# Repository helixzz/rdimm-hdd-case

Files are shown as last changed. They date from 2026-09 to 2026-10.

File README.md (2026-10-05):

# RDIMM HDD Case

**最新完整版本：[v4.4.1 实物版本标记版](docs/v4.4.1.zh-CN.md) · [下载](https://github.com/helixzz/rdimm-hdd-case/releases/tag/v4.4.1)**。外壳底面、上盖外面及两片托盘厚端梁均刻有 `V4.4.1` 和 BASE/LID/MID/TOP 代号。完整两盘 P2S＋AMS 2 Pro 工程，参考 **4:53:10 / 167.67 g / 32 次换料**；配合尺寸与 v4.4 相同，可复用旧件。专用支撑部分仍需工具，刻字实物效果及完整套件验证待完成。以下为历史测试与版本记录。

**历史完整版本：[v4.4 双材料整套工程](docs/v4.4.zh-CN.md) · [下载](https://github.com/helixzz/rdimm-hdd-case/releases/tag/v4.4)**。四个永久零件、两盘、8 条裸 DDR5 RDIMM；采用 RC6 实测能拆净的整块 Support For PLA 支撑，统一 3.2 mm 安装孔并屏蔽孔内支撑，移除角部脆弱残片。P2S＋AMS 2 Pro 参考 **4:51:04 / 167.66 g / 32 次换料**，比旧单材料版更慢；固定端和顶盖限位支撑仍需工具，完整套件装配与耐久待实测。以下为历史测试和版本记录。

**RC6 实测更新：[结果与后续方向](docs/validation-v4.4-trials.zh-CN.md)**。N 两端下垂，固定端阻挡 DIMM，免支撑对照未通过。A 基本合格，A/C 支撑均可一次拆净、无残留；A 固定端及 C1/C3 仍需工具用力拆除。该结果取代下方 RC6 的“待验证”状态，不代表完整产品已通过验证。

**最新测试盘：[v4.4 RC6：整块支撑与无支撑对照](docs/v4.4-rc6-solid-trial.zh-CN.md) · [下载](https://github.com/helixzz/rdimm-hdd-case/releases/tag/v4.4-rc6-solid-trial)**。一盘 A/N/C1/C3 四件，取消细齿与异材锁键，可拆支撑及把手全部 Support For PLA。N 是真正无支撑的诊断对照，非生产承诺。P2S＋AMS 2 Pro 参考 **1:03:14 / 26.27 g / 10 次换料**；[整盒研究](docs/rc6-solid-study.zh-CN.md)筛选低把手候选约 4:51:09 / 32 次。实际打印与拆除仍待验证。

**2026-10-05 实测更新：[RC5 反馈与整块支撑初筛](docs/validation-v4.4-trials.zh-CN.md)**。DIMM 支撑在拆除前已出现散丝，RC5 一体支撑未通过；分体压条使用复杂，暂不作为首选。C 组较易拆净但仍有交界面瑕疵，P1/H32 观察正常。后续转向简单、整块专用材料牺牲支撑，已筛选并发布下列 RC6 对照盘。

**上一轮测试盘：[v4.4 RC5：一体/分体压条对比](docs/v4.4-rc5-peel-trial.zh-CN.md) · [下载](https://github.com/helixzz/rdimm-hdd-case/releases/tag/v4.4-rc5-peel-trial)**。一盘七件：A 连体稀疏支撑，B＋独立永久压条，C1/C3、H32、修正孔内支撑的 P1。P2S＋AMS 2 Pro，约 **1 小时 21 分 27 秒 / 34.12 g / 12 次换料**。B 固定端和压条无支撑；活动端仍需支撑。仅试件，实际拆除与装配待验证。[整套成本比较](docs/rc5-structure-study.zh-CN.md)：A/B 仍比旧双材料候选慢，尚不能宣称生产提速。

**2026-10-04 实测反馈：[RC4 结果与改进方向](docs/validation-v4.4-trials.zh-CN.md)**。H32 的 3.2 mm 孔表现良好；A 固定端仍难拆，A/C 的 Support for PLA 接触薄片仍有残留，尚未达到免工具拆净目标。P1/P2 漏加孔内禁支撑，已在研究副本修正并复核；原发布附件未覆盖。RC5 已完成整盒候选筛选，现提供一体/分体同盘复核。

**上一轮测试盘：[v4.4 RC4：完整产品研究实物复核](docs/v4.4-rc4-product-trial.zh-CN.md) · [下载](https://github.com/helixzz/rdimm-hdd-case/releases/tag/v4.4-rc4-product-trial)**。一盘六件，PLA Basic＋Support for PLA / AMS 2 Pro；约 **1 小时 03 分 15 秒、25.00 g、6 次换料**。验证支撑把手、卡簧斜撑、顶盖限位支撑、3.2 mm 孔，以及真实外壳截面的填充对照。尚非完整生产版本。

**完整产品优化研究：[整套切片、材料策略与批量排版](docs/full-product-optimization.zh-CN.md)**。以完整 8 条容量盒子为对象：选择性双材料约 4 小时 10 分钟；两套三盘平均每套约 3 小时 37 分钟 / 专用支撑料 3.67 g。已整合 3.2 mm 安装孔、角部残片清除及支撑改进，完成几何与刀路检查；尚待实物验证，不是新生产版本。

**制造改进研究：[质量、效率与后处理评估](docs/manufacturing-study.zh-CN.md)**。拨片斜撑及支撑把手去底脚的四试件对照盘，参考从 63 分 43 秒降至 49 分 55 秒，少三处底脚接触界面；含材料分配、装卸路径及残留避让检查。后续 RC4 实测仍有拆除和残留问题，见上方反馈；不是新生产版本。

**上一版试件：[v4.4 RC3 双材料测试盘](docs/v4.4-rc3-dual-trial.zh-CN.md) · [下载](https://github.com/helixzz/rdimm-hdd-case/releases/tag/v4.4-rc3-dual-trial)**。P2S＋AMS 2 Pro，PLA Basic＋**Support for PLA**；一盘四件，明确建模上下接触层并加宽支撑把手，约 64 分钟 / 22.86 g（含冲刷及擦料塔）。孔径已选定 **3.2 mm**，用于 H32 及后续完整工程；本版仍是局部试验，非完整替换套件。[上轮实物反馈](docs/validation-v4.4-trials.zh-CN.md)。

**上轮综合试件：[v4.4 RC2 一盘 12 件](docs/v4.4-rc2-combined-trial.zh-CN.md) · [试件下载](https://github.com/helixzz/rdimm-hdd-case/releases/tag/v4.4-rc2-combined-trial)**。约 57 分钟、22.6 g，合并 DIMM 槽支撑/残留避让、顶盖支撑抽取、安装孔孔径及托盘角部清理。仅用于局部验证，不替代完整套件。

**当前完整版本：[v4.3](docs/v4.3.zh-CN.md) · [正式下载](https://github.com/helixzz/rdimm-hdd-case/releases/tag/v4.3)**。保留侧壁加强棱，并用从底板长出的连续内凹圆弧连接，棱顶圆角、与活动托盘留 0.4 mm 间隙。完整四件两盘，P2S 参考约 3 小时 11 分钟，比 v4.2 增加约 13 秒。仅外壳变化，v4.2 盖板和托盘可复用。完整实物配合与强度仍待验证。

**历史完整版本：[v4.2](docs/v4.2.zh-CN.md) · [正式下载](https://github.com/helixzz/rdimm-hdd-case/releases/tag/v4.2)**。下载一个完整包即可得到全套两盘 P2S 工程、四个零件、支撑示意及检查记录。托盘第一弹臂采用 3 mm 基座，盖板采用连续间隙与斜面导入；八处齿头下方让位 0.5 mm，底部改为连续内凹 R6 过渡；两盘参考约 3 小时 11 分钟。实际完整配合与强度仍待实物验证。已有 RC4 盖板可复用；外壳及旧托盘需更新才能获得全部修复。

**历史盖板修订：[v4.1-rc4 替换盖板](docs/v4.1-rc4.zh-CN.md)**。延续斜面导入，将连接颈侧间隙向下连续延伸并平顺接回根部，修正 RC3 横移与上浮组合时的局部干涉。仅重打盖板约 37 分钟，RC1/RC2 外壳、托盘复用；舌片主体厚度和承托面积保持 RC3，实际松紧和强度待验证。

3D-printable storage for **8 bare DDR5 RDIMMs** inside a **147 × 101.6 × 26 mm** envelope, with traditional 3.5-inch HDD side and bottom mounting positions.

为服务器内存设计的硬盘位收纳盒：三层托盘，容量 2 + 3 + 3 条，优先保持标准 3.5 寸硬盘外形。目标参考内存为 Samsung M321RAJA0MB2-CCP / CCPKF，打印机参考为 Bambu Lab P2S。

**历史结构候选：[v4.1-rc2 缩小拨扣窗口](docs/v4.1-rc2.zh-CN.md)**。两个短端开口的上方恢复连接壁，下部保留拨扣和支撑清理空间；配置 p2 对小拱顶局部屏蔽支撑，六侧孔内也无支撑。RC1 盖板及托盘不变、可继续使用。完整两盘参考 3 小时 12 分 6 秒，较 RC1 增加约 30 秒、0.63 g。几何和名义刀路通过，实际操作与抗震/跌落仍待验证。

**上一版结构：[v4.1-rc1 扣合与卡扣根部加固](docs/v4.1-rc1.zh-CN.md)**。四处平面扣脚、加厚弹臂和根部圆角、长侧壁三角加强筋；仍按压、滑 8 mm、抬盖，8 条四件两盘。不混用 v4.0/v3 盖板及托盘。

**上一版打印工艺：[v4.0-rc4-p1 六侧孔局部禁止支撑](docs/v4.0-rc4-p1.zh-CN.md)**。保留 RC4 圆孔尺寸，切片确认六孔内支撑归零，其余关键支撑保留；需打开带配置的工程，STL 不包含此修订。无支撑孔顶质量及实际定位销配合尚待打印验证。

**历史几何候选：[v4.0-rc4 两条长边 R2 圆角](docs/v4.0-rc4.zh-CN.md)**。在去除侧字的 RC3 基础上，只在长内壁与底板交界增加 R2，并保留安装孔净空；短端卡扣和 SATA 区不变。圆角最高 Z=6，活动托盘最低面 Z=10.8，间距 4.8 mm，完整几何路径和名义刀路检查通过。盖板及托盘与 RC2/RC3 兼容；外壳盘预计增加约 2 秒、0.13 g，整套仍约 3 小时 7 分。改善底部横纹的效果及完整实装尚待验证，当前打印无需中断。

**打印反馈与新候选：[v3.2-rc1 打印可靠性修订](docs/v3.2-rc1.zh-CN.md)**。v3.1 首个外壳出现按压锁扣粘连，暂停按旧方案批量制作。RC 修订锁扣、PCB 槽口，并提供明确支撑配置和一盘可选验证件；完整件仍两盘，既有盖板可保留。[候选几何](models/v3.2-rc1/)需要配套工艺，不能继续无支撑打印；本版仍待实物验证，未覆盖旧 Release。

**检查件实测更新：[RC2 A 底座修正](docs/v3.2-rc2-latch-check.zh-CN.md)**。RC1 小盖板缺少下承托而倾斜掉落，修正件只重打 A 底座，复用原小盖板，参考约 13 分钟。单槽实际 DIMM 装卸无干涉，但固定力偏弱、清理费技巧；完整套件与运输性能仍未验证。RC2 此处仅为检查件修订，不替换整套 RC1 文件。

**当前固定版本：[v3.1 完整两盘实测版](docs/v3.1.zh-CN.md) · [下载 Release](https://github.com/helixzz/rdimm-hdd-case/releases/tag/v3.1)**。v3-S 正式命名为 v3.1，单件几何不变；单套两盘（外壳＋盖板、三个托盘），STL / 3MF 二选一。另有十套共 15 次任务的批量排版与实际参考切片时间。状态仍为待实物验证的预发布，不能把时间估计当作质量保证。[版本规则](docs/versions.zh-CN.md)。

**历史工作名称：[v3-S 一体拨扣托盘](docs/v3-simple.zh-CN.md)，当前请使用 v3.1**。保留 8 条容量和 v3 外壳，取消三片独立限位框，内部只剩三个托盘；每槽插入固定端、拨扣放下、松手固定。新试件仍[一盘完成](models/v3-simple/first-test-all.stl)，整套缩减为两盘。尚未打印验证卡扣力度、耐用性与实际保持能力；请先试单槽件。[查看实际网格预览](models/v3-simple/simple-tray-preview.png)。

**New experimental v3: [免工具取放与固定背板避让](docs/v3.zh-CN.md).** No mandatory internal screws; sliding lid with a release latch, three keyed retainer frames, 2 mm deeper mounting holes, and a connector-end recess. Remains 147 × 101.6 × 26 mm / 8 modules. Print the mechanism/retainer coupons and empty bay-fit gauge first: **v3 has not been physically tested**, and the connector recess does not establish universal backplane compatibility. Closed cover required for inversion retention. Complete [three-plate STL layouts](models/v3) are supplied; v2 and v2-R remain unchanged and must not be mixed with v3.

V3 now includes [engraved operation guides](models/v3/operation-guides.png): `1 PRESS`, `2 OPEN`, `KEEP LEVEL`, matching layer numbers, `LIFT` at the thick end bars, and `SATA END`. These are shallow recesses in the printable geometry, with no external font dependency; the assembly interfaces remain compatible with the earlier unmarked v3.

**V3 首次试打只需一盘：[first-test-all.stl](models/v3/first-test-all.stl)**。空壳、单槽托盘与框、滑轨及锁扣小样共 7 件已排好位置，[查看排版](models/v3/first-test-all.png)。保持 100% 比例，按层打印；需按说明设置局部支撑并检查细筋。无需再分别打印三组试件。

**Status: engineering prototype. A user printed v2 and reported noticeable movement when carrying it.** The experimental [v2-R retention retrofit](docs/retention.zh-CN.md) adds a screwed tray stack and PCB-edge keepers while reusing the v2 body; **the retrofit is not yet physically tested**. This is not a certified ESD or transport enclosure. V2 offers either plastic mounting pilots or optional metal inserts on the six side holes; bottom and lid pilots still require tapping.

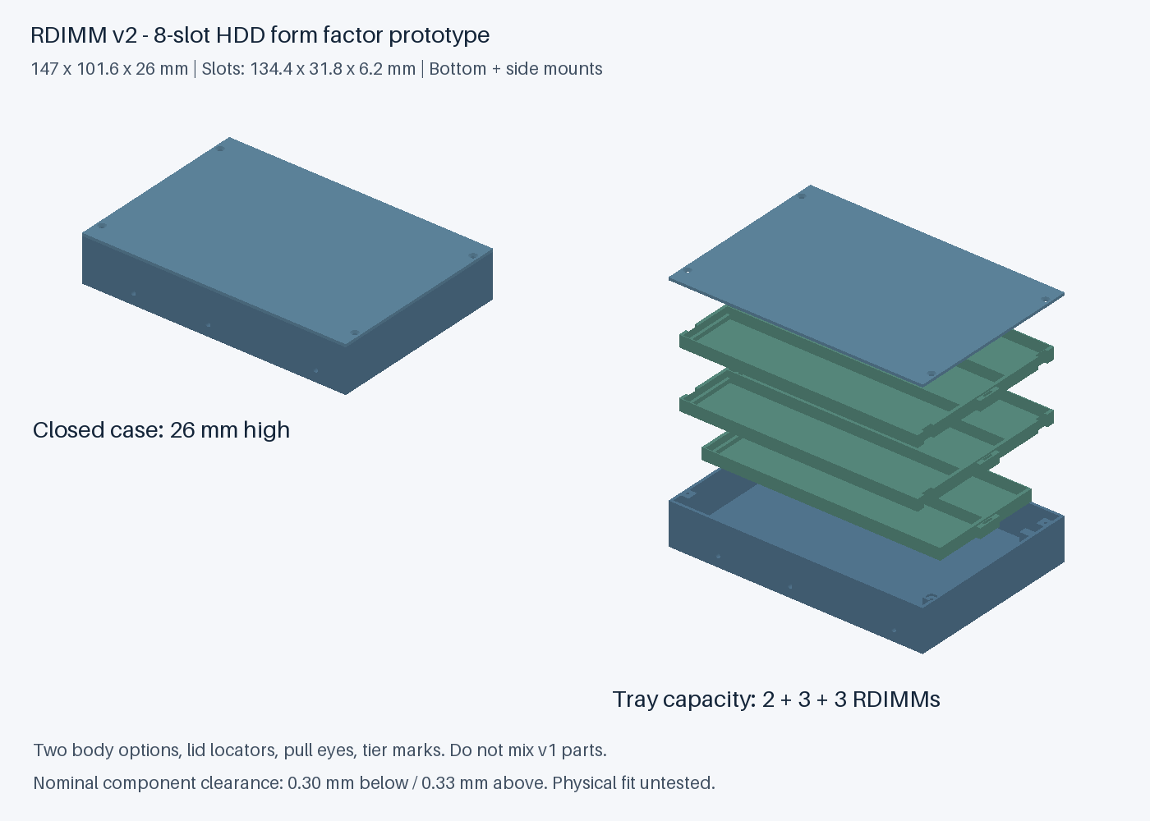
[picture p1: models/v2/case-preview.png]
Mesh-derived assembly preview


**V2 prototype:** greater component-to-floor clearance, lid locating collars, tray pull eyes and tier marks, plus optional side inserts. See [changes and tradeoffs](CHANGELOG.md) and the [detail preview](models/v2/v2-details.png). Do not mix v1 and v2 parts.

## Print the current prototype

- **已有 v2 外壳且遇到晃动：[v2-R 固定升级件与小样说明](docs/retention.zh-CN.md)**。先打印 `models/v2-retention/first-test-plate.stl`；需额外 M2 螺丝，不能混用旧托盘。
- **整盘打印：[P2S 两盘排版与导入说明](plates/v2/README.zh-CN.md)**。每盘一个 STL / 3MF，无需逐件摆放；普通攻牙版和侧面嵌件版分别提供替代第一盘。
- Browse [v2 STL files](models/v2), or use GitHub **Code → Download ZIP** on the branch you intend to print. [V1 files](models/v1) remain available as a historical baseline.
- **先阅读：[v2 中文打印与装配说明](docs/v2.zh-CN.md)**。尺寸出处和原始硬盘孔位来源另见 [v1 基准说明](docs/printing.zh-CN.md)。
- Print one `fit-coupon-1-slot-print-3.stl` first, then three total plus `stack-coupon-cap.stl` for stack fitting. If choosing side inserts, also print `side-insert-coupon.stl` before the body.
- Full set: choose **one** of `body-pilot.stl` / `body-side-inserts.stl`; add `tray-bottom-2.stl`, `tray-middle-3.stl`, `tray-top-3.stl`, and `lid.stl`, one each. STL units are mm; use 100% scale. The lid is already exterior-face-down for printing.

HDD mounts use **6-32 UNC**, not M3. The optional metal-side version is dimensioned specifically for **PEM IUTB-632-150** inserts. Bottom holes remain 2.7 mm plastic pilots, now 3.3 mm deep. Limit installed screw intrusion to 3.0 mm and check actual effective thread depth. The lid uses four M2 countersunk screws; its plastic pilots still require tapping. Read the full guide before printing or installing hardware.

## Design basis and limitations

| Item | v2 value |
| --- | --- |
| Assembled envelope | 147 × 101.6 × 26 mm |
| Capacity | 8 RDIMMs; not a proven maximum-density packing |
| Nominal cavity per module | 134.4 × 31.8 × 6.2 mm |
| Reference maximum module envelope | 133.80 × 31.40 × 5.57 mm |
| Nominal component clearance | 0.30 mm below, 0.33 mm to next tray above |
| Mounting positions | 6 side, 4 bottom; traditional HDD pattern |
| PCB contact assumption | 2 mm component-free region at each short edge |

The envelope comes from Micron's DDR5 RDIMM reference drawing, cross-checked against another Samsung double-sided RDIMM drawing. It is **not a measured or verified mechanical drawing for the exact target Samsung part**. Sources and coordinate conventions are recorded in the [design/printing guide](docs/printing.zh-CN.md#设计基准与来源).

Automated checks cover closed meshes, connected parts, both body assemblies, simplified RAM interference, 64 component-offset cases, insert envelopes, the coupon stack, and 3 mm screw penetration. They do not establish print tolerances, tapping strength, exact component placement, chassis compatibility, or ESD performance. There is no independent PCB latch: arbitrary-orientation retention and transport safety are not established. Ordinary PETG/ASA is not inherently static dissipative. Physical work remains explicitly tracked in the [v2 validation record](docs/validation-v2.md). A 38 mm upright variant is a future design direction; chassis clearance must be established before adopting it.

## Rebuild on another computer

Use **Python 3.12** and Git on Windows, macOS, or Linux. From the repository root:

```sh
python -m venv .venv
# Windows PowerShell:
.venv\Scripts\Activate.ps1
# macOS / Linux instead:
# source .venv/bin/activate
python -m pip install -r requirements.txt
python src/build_case.py
```

The v2 generator writes nine STL files, `verification.json`, and two mesh-derived PNG previews to ignored `build/`. Geometric assertions run as part of generation; do **not** run Python with `-O`. To choose another directory, pass `--output-dir PATH`. The default preview labels are English; for Chinese labels supply `--font PATH_TO_CHINESE_FONT` (font not bundled).

The design parameters currently live near the top of `src/build_case.py`. Changing dimensions requires reviewing the construction and checks, not just editing a single number. Commit source changes and intentionally regenerated `models/v2/` artifacts together; normal rebuilds leave the tracked baseline untouched. To refresh the v2 baseline, use `python src/build_case.py --output-dir models/v2`. Rebuild the untouched v1 design with `python src/build_v1.py --output-dir build/v1`. GitHub Actions rebuilds both versions on Windows and Linux and uploads the generated files.

## Collaborating

See [CONTRIBUTING.md](CONTRIBUTING.md) for the edit/build/review workflow and [AGENTS.md](AGENTS.md) for agent handoff constraints. Open an issue for print feedback or design proposals. Include module part number, material, nozzle/layer settings, measurements, and photos when available. Share changes in a branch and pull request so work from different computers can be reviewed together.

## License

Original source, CAD/model files, previews, and documentation in this repository are provided under the [MIT License](LICENSE). Referenced manufacturer drawings are linked as design references, are not redistributed here, and retain their respective owners' rights. No manufacturer endorsement or universal fit certification is implied.

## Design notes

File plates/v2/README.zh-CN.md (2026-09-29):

# v2 整盘打印排版（P2S）

已有用户实打反馈：原 v2 携带时有明显晃动。这里仍是原版打印文件；[v2-R 固定升级件](../../docs/retention.zh-CN.md) 可保留外壳、更换内部件和盖板，先试小样。

完整盒子为 **两盘、共五个零件**。每盘提供相同排版的 STL 和通用 3MF，二选一导入，**不要两种格式同时导入**。无需逐件手动摆放。

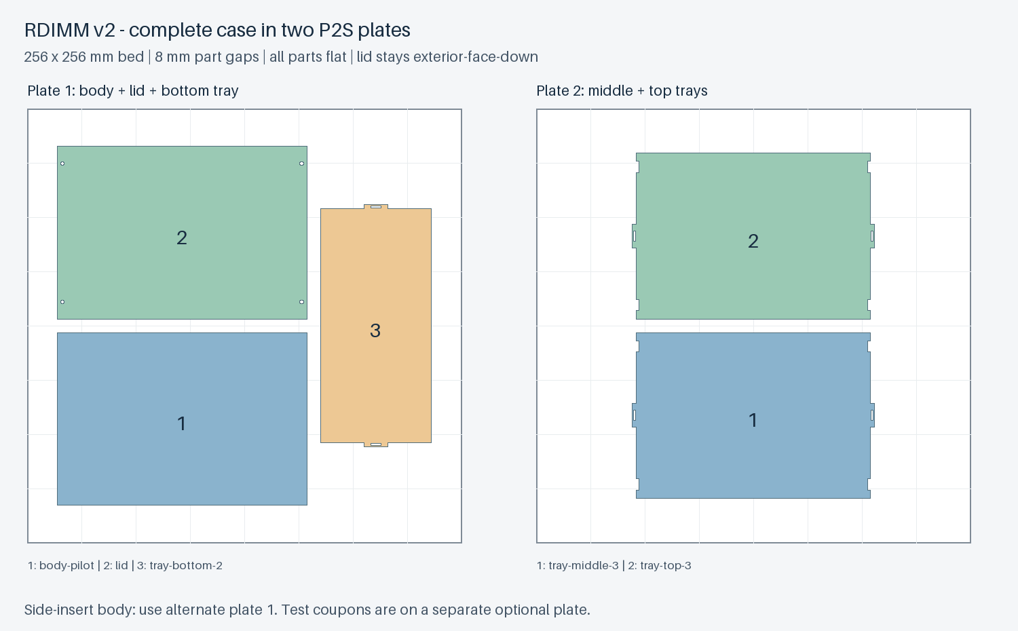
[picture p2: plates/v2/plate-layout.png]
两盘排版


## 打印哪些文件

| 文件（扩展名任选 `.stl` 或 `.3mf`） | 内容 | 是否必选 |
|---|---|---|
| `plate-1-pilot` | 普通攻牙外壳＋盖板＋两槽底托盘 | 与下一项二选一 |
| `plate-1-side-inserts` | 侧面嵌件外壳＋盖板＋两槽底托盘 | 与上一项二选一 |
| `plate-2-middle-top` | 三槽中托盘＋三槽顶托盘 | 必选 |
| `optional-test-plate` | 三个单槽试件＋试装平盖＋一个嵌件孔径试件 | 可选；不是正式盒内零件 |

默认打印 `plate-1-pilot` 和 `plate-2-middle-top` 即可得到一套。侧面嵌件版的指定五金与加工要求见 [v2 装配说明](../../docs/v2.zh-CN.md)。试件仍建议先试装；若只想先打一个单槽，原始单件文件在 `models/v2/`。

## 在 Bambu Studio 中使用

1. 新建项目，选择实际 **P2S、喷嘴、打印板和耗材**；本排版按 256 × 256 mm 热床制作。
2. 导入选定的第一盘文件。STL 已把同盘零件保存在同一个文件内；3MF 是保留相对位置的模型组件，**不含打印机/耗材/工艺预设**。若软件询问，按模型/几何导入。保持 **100% 比例**，不拆散后重新排列，不自动改变朝向。
3. 使用**逐层打印**，不要切换为逐对象顺序打印；8 mm 间距不是喷头逐对象避让距离。使用已有合适的耗材配置，0.4 mm 喷嘴可从 0.20 mm 层高开始检查。盖板已经外表面朝下，不要再次翻转。
4. 切片并检查床边、薄壁、侧孔桥接和首层。若需要 brim，可先将宽度控制在每件 3 mm 以内；更大的 brim、裙边或新增擦料塔可能需要重新检查排版。没有预生成 G-code，也没有发送到打印机。
5. 第一盘打印后取件、清理打印板，再打印第二盘。也可在同一个 Bambu Studio 项目中新建第二个打印盘，把第二盘文件导入那里。**不要把两个文件同时放到同一物理打印盘。**

每盘 STL 导入后被整体自动居中通常不影响相对布局；不要选择把各个实体重新自动排布。正式第一盘占地约 220.4 × 211.2 mm，第二盘约 142.8 × 203.6 mm。全部零件都接触 Z=0，未叠放打印。

## 为什么不能保持平放而合成单盘

对实际 v2 网格的 XY 投影做并集后，五个零件的投影面积合计约 **65,912.76 mm²**；256 × 256 mm 热床只有 **65,536 mm²**。即使不留任何间距，保持这些打印朝向也不能装进同一平面。这一结论不涉及把零件竖起来、修改设计或增加另一种支撑策略。

本排版只平移零件，并将两槽托盘绕 Z 轴旋转 90°，没有缩放或修改模型。正式两盘均留至少 8 mm 零件包围盒间距；第一盘最小床边余量约 17.8 mm，第二盘约 26.2 mm。两种第一盘是替代选项，不能同时打印当作同一套所需零件。

打印面积参考：[Bambu Lab 官方 P2S 介绍](https://blog.bambulab.com/the-icon-redefined-meet-the-p2s-a-completely-reengineered-version-of-the-ultra-productive-p1-series/)。

## 重建与验证

在项目根目录运行：

```sh
python src/layout_v2.py --output-dir plates/v2
```

生成器从现有 `models/v2/*.stl` 读取，检查尺寸保持、床内边界、8 mm 间距、STL 闭合性及实体数量、导出回读坐标/体积、3MF XML 网格回读；记录源 STL 的 SHA-256。详细结果在 `layout-verification.json`。

这些几何验证不是实际打印验证。Bambu Studio 的命令行导入/再导出检查另记录在 `bambu-import-check.json`，并不代表已切片或已选择你的耗材配置。v2 原有的实物验证与 ESD 限制仍适用。

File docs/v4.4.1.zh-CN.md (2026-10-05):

# v4.4.1：每个零件都有实物版本号

完整收纳盒可放 **8 条裸 DDR5 RDIMM**，外形 147×101.6×26 mm，底层两槽、两片活动托盘各三槽。采用 P2S＋AMS 2 Pro、PLA Basic＋Support For PLA 双材料工程。

本版在 v4.4 完整工程上增加可直接打印的版本号与零件代号，便于识别拆散、混放的零件。只增加非配合面的浅凹字，四个永久零件的装配尺寸、20 块专用支撑、3.2 mm 安装孔和日常操作不变。已有 v4.4 零件可以继续配合使用，无需仅因缺少标记而报废。

| 零件 | 实物文字 | 位置 |
|---|---|---|
| 外壳 | `V4.4.1 BASE` | 外壳底面，翻过来可正向阅读 |
| 上盖 | `V4.4.1 LID` | 上盖外侧平面 |
| 中层托盘 | `V4.4.1`、`MID` | 厚端梁顶面 |
| 顶层托盘 | `V4.4.1`、`TOP` | 厚端梁顶面 |

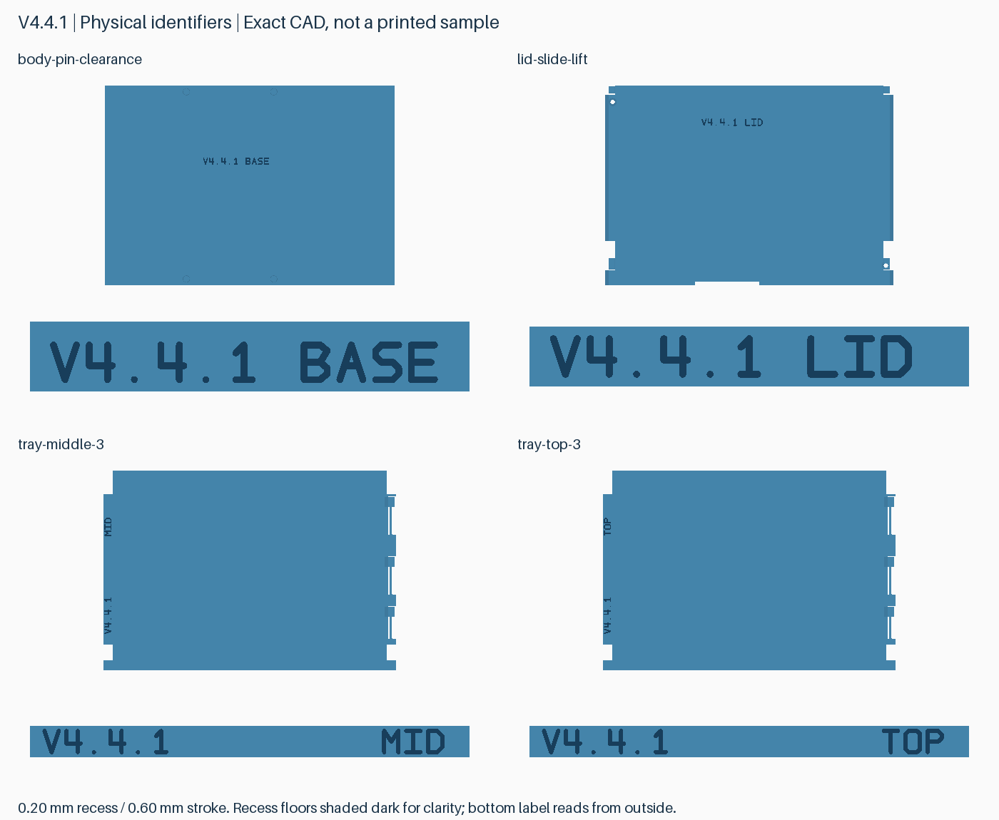
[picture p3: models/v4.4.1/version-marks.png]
版本标记位置


图为真实 CAD 几何示意，字槽底面加深颜色以便辨认；实际仍为同色单材料表面，没有额外换色。字深 **0.20 mm**、笔画宽 **0.60 mm**、字高约 3.6 mm。托盘薄底板、卡簧和 DIMM 接触面不刻字。保留原有操作提示。从本版起，后续版本的所有永久零件均须带完整版本号，试件还须带试件编号；一次性拆除的支撑不标号。

## 下载与打印

从 [v4.4.1 Release](https://github.com/helixzz/rdimm-hdd-case/releases/tag/v4.4.1) 下载 **rdimm-v4.4.1-complete-P2S-AMS2Pro.zip**。这是完整两盘工程，不是补丁文件。解压后以“工程”打开：

- `rdimm-4.4.1-plate-1-pin-clearance-P2S-AMS2Pro.3mf`：外壳＋上盖。
- `rdimm-4.4.1-plate-2-upper-trays-P2S-AMS2Pro.3mf`：中层＋顶层托盘。

| 打印盘 | 参考时间 | 总耗材（含冲刷、擦料塔） | 换料 |
|---|---:|---:|---:|
| 1 外壳＋上盖 | 3 小时 24 分 23 秒 | 121.39 g | 22 次 |
| 2 两片托盘 | 1 小时 28 分 47 秒 | 46.28 g | 10 次 |
| 整套 | **4 小时 53 分 10 秒** | **167.67 g** | **32 次** |

相比 v4.4，整套增加约 **2 分 6 秒**，换料次数不变。以上为 Bambu Studio 切片估算，不含换盘和后处理。P2S、0.4 mm 喷嘴、0.20 mm 层高、纹理 PEI 板、按层打印。材料 1：Bambu PLA Basic；材料 2：**Bambu Support For PLA / GFS02**，不是 Support for PLA/PETG。打印前映射至实际 AMS 槽位。

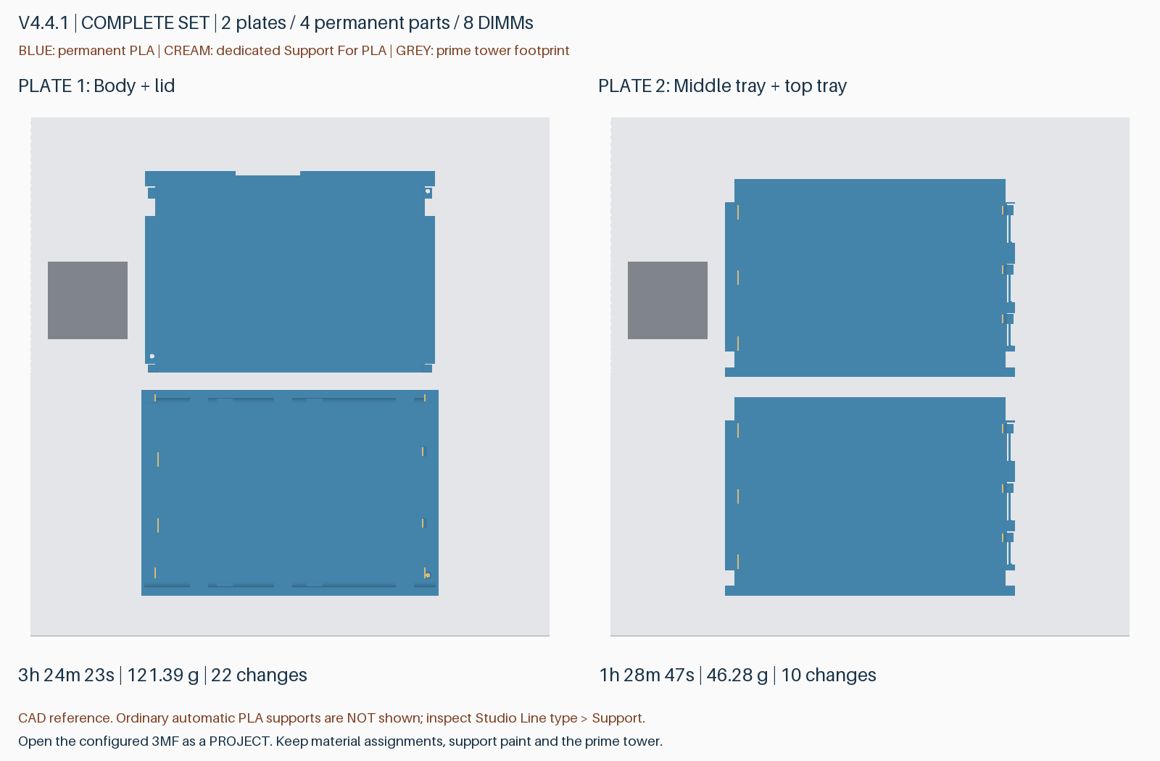
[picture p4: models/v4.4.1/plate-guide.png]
完整两盘排版


保留文件中的摆放、材料分配、禁支撑涂色和擦料塔；不要重新拆分模型、自动落底或全局禁用支撑。普通自动支撑仍用 PLA，20 块专用支撑及其把手均为 Support For PLA。双向冲刷各 800 mm³，不冲刷进成品或支撑。包内四份 STL 只供几何参考，不可替代配置工程；无 G-code。

## 拆支撑与装配

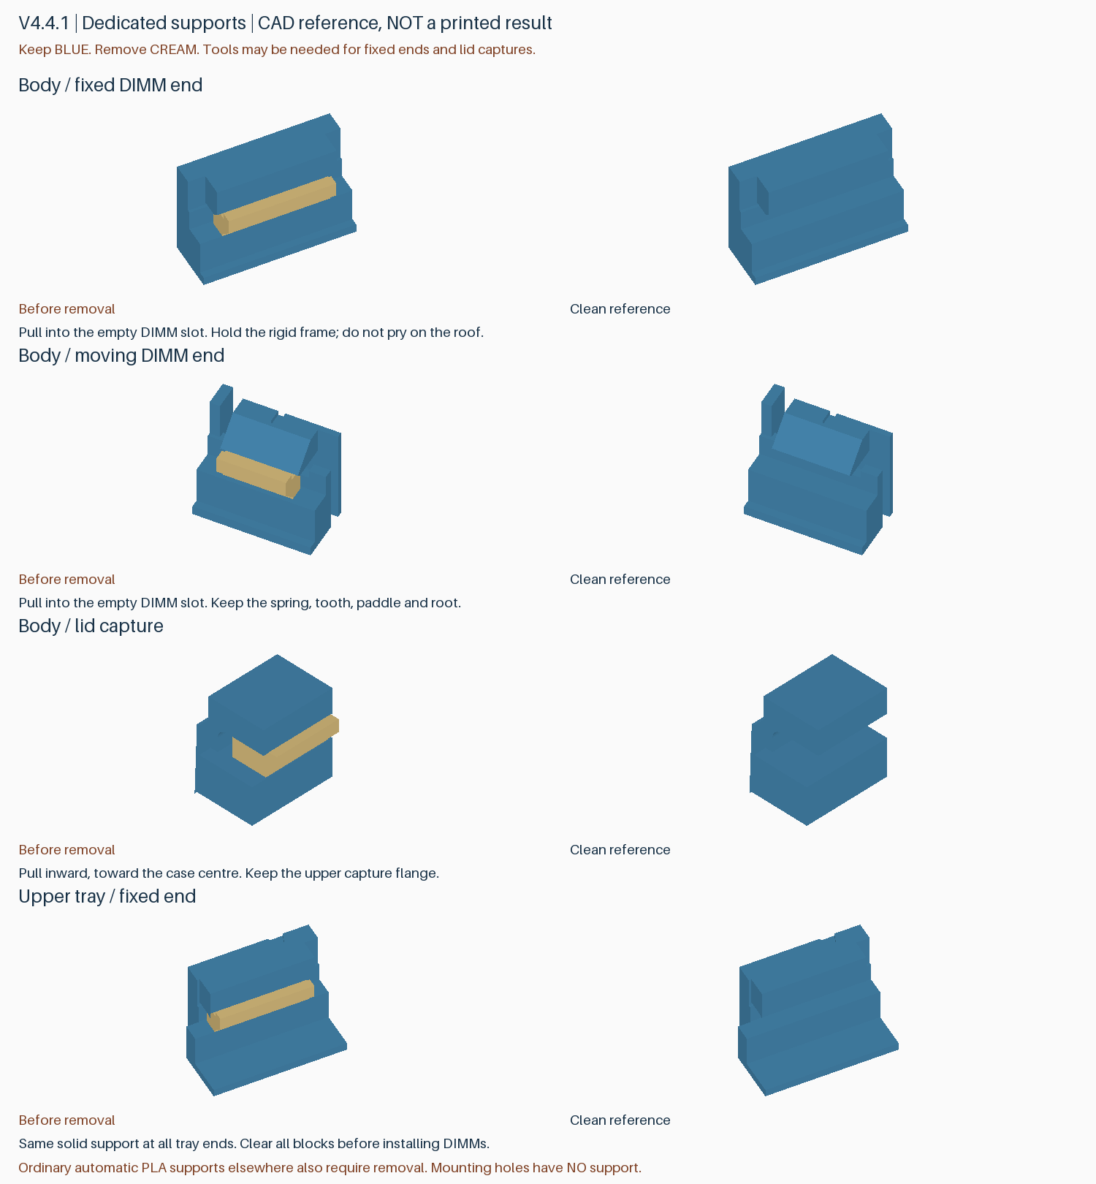
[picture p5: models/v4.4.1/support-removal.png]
支撑拆除示意


图中蓝色保留，米黄色拆除；另有未画出的普通 PLA 自动支撑，可用 Studio 的线类型预览检查。DIMM 两端支撑向空槽内侧取出，顶盖限位支撑向盒子中心取出。扶住刚性框架，不要在卡簧或顶棚上猛撬。固定端和顶盖限位仍可能需要工具；RC6 局部试件实测可一次拆净，不代表完整盒子的每处都能徒手拆除。十个底部/侧面安装孔均已屏蔽孔内支撑。

清理后先检查空盒卡簧回弹与上盖装卸，再安装内存；固定端先就位，拨开活动端装入。上盖沿 OPEN 方向滑动约 8 mm 后抬起，装回反向操作。3 mm 卡簧基座、齿头、PCB 承托台、盖板限位顶棚均保留。

参考兼容对象为三星 M321RAJA0MB2-CCP/CCPKF 一类无散热片 DDR5 RDIMM；不支持马甲条，未验证 DDR4 或其他板形。单侧 SATA 避让深 7.5 mm，无电气连接功能，实际硬盘槽/背板先用空盒验证。普通 PLA 无 ESD 防护认证。

## 验证范围与重建

- 几何标记均完整落在实体面上，字槽后方保留至少：外壳 2 mm、上盖/托盘 1 mm 的实体；四件保持连通、水密，文字不凸出外形。标记仅减料，其余结构沿用 v4.4 已检查的几何与装卸路径。
- 两盘重新切片无警告，配置导入网格、20 块专用支撑逐层连续及接触覆盖、10 孔无支撑、8 条 DIMM 弹臂通道、外壳锁扣自由通道重新通过检查。
- 186 个托盘卡簧根部层连接、8 处齿头间隙和 8 处普通支撑区域复核通过。六处文字区域的字槽内部采样无名义挤出覆盖、无自动支撑填入；版本号未在切片中被填平。
- 实物刻字清晰度受首层、平台纹理和耗材影响，尚待打印确认；完整双材料套件装配、抗冲击和疲劳仍未完成实物验证。数值检查不能证明这些性能。

源码入口：`build_v4_4_1.py` 生成几何；`manage_v4_4_1.py prepare --bambu <Studio路径> --profiles <官方BBL配置目录>` 配置并切片；依次运行 `manage_v4_4_1.py audit`、`manage_v4_4_1.py preview`。公开报告位于 `docs/reports/v4.4.1-*`。在干净 `v4.4.1` 标签提交运行 `manage_v4_4_1.py package` 生成完整包和 SHA-256。旧 v4.4 及其他已发布标签、附件保持不变。

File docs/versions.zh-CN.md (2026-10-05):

# 版本管理

| 名称 | 定位 | 目录 / 固定依据 |
|---|---|---|
| **v4.4** | 完整双材料两盘：整块专用支撑、3.2 mm 十孔无支撑、清除脆弱角片 | [说明](v4.4.zh-CN.md)、[Release](https://github.com/helixzz/rdimm-hdd-case/releases/tag/v4.4)；RC6 局部能拆净，固定/C 仍需工具，完整套件待实测 |
| **v4.4-rc3-dual-trial** | 一盘四件：PLA＋Support for PLA 专用接触层、加宽支撑把手、选定 H32 | [说明](v4.4-rc3-dual-trial.zh-CN.md)、[预发布](https://github.com/helixzz/rdimm-hdd-case/releases/tag/v4.4-rc3-dual-trial)；1 小时 03 分 43 秒，完整版本仍为 v4.3 |
| **v4.4-rc2-combined-trial** | 一盘 12 件：槽支撑、顶盖支撑、孔径及角部清理综合试验 | [说明](v4.4-rc2-combined-trial.zh-CN.md)、[预发布](https://github.com/helixzz/rdimm-hdd-case/releases/tag/v4.4-rc2-combined-trial)；56 分 31 秒，完整版本仍为 v4.3 |
| **v4.4-rc1-support-trial** | 一盘 A/B 支撑拆除和残留避让试验，非正式替换托盘 | [说明](v4.4-rc1-support-trial.zh-CN.md)、[预发布](https://github.com/helixzz/rdimm-hdd-case/releases/tag/v4.4-rc1-support-trial)；完整版本仍为 v4.3，待试印 |
| **v4.3** | 完整两盘：保留加强棱＋底部连续圆弧；仅外壳更新 | `models/v4.3/`、[说明](v4.3.zh-CN.md)、[Release](https://github.com/helixzz/rdimm-hdd-case/releases/tag/v4.3)；v4.2 盖板和托盘复用，强度待实测 |
| **v4.2** | 完整两盘正式发行版：3 mm 托盘基座、齿头下让 0.5 mm、内凹 R6 底部过渡、RC4 盖板 | `models/v4.2/`、[说明](v4.2.zh-CN.md)、[Release](https://github.com/helixzz/rdimm-hdd-case/releases/tag/v4.2)；统一包，实物验证待完成 |
| **v4.1-rc4** | 连续颈部净空、斜面接回根部的替换盖板候选 | `models/v4.1-rc4/`、[说明](v4.1-rc4.zh-CN.md)；仅替换盖板，修正组合位姿局部干涉，实际手感/强度待验证 |
| **v4.1-rc3** | 斜面导入、扩大间隙的替换盖板候选 | `models/v4.1-rc3/`、[说明](v4.1-rc3.zh-CN.md)；兼容 RC1/RC2 外壳与托盘，仅需打一盘盖板，配合及强度待实测 |
| **v4.1-rc2** | 缩小两处底层拨扣窗口并恢复上方连接壁，配套 p2 支撑配置 | `models/v4.1-rc2/`、[说明](v4.1-rc2.zh-CN.md)；RC1 盖板、托盘兼容，实际操作与抗震待实测 |
| **v4.1-rc1** | 平面扣脚、卡扣根部及侧壁加固候选，工艺 p1 保留六孔屏蔽 | `models/v4.1-rc1/`、[说明](v4.1-rc1.zh-CN.md)；必须整套使用，抗震/跌落待实测 |
| **v4.0-rc4-p1** | RC4 几何的六侧孔支撑屏蔽工艺补丁，孔顶待实测 | [工艺说明](v4.0-rc4-p1.zh-CN.md)；需要带配置的工程，不另建几何目录 |
| **v4.0-rc4** | 两条长内壁底部 R2 圆角试印候选，保留孔净空 | `models/v4.0-rc4/`、[评估与说明](v4.0-rc4.zh-CN.md)；与 RC2/RC3 配套件兼容 |
| **v4.0-rc3** | 取消外侧凹刻的待实测候选，未加圆角 | `models/v4.0-rc3/`、[说明](v4.0-rc3.zh-CN.md)；与 RC2 盖板及托盘兼容 |
| **v4.0-rc2** | 按 SATA 标准补足导向头进深至 7.5 mm，完整待实测候选 | `models/v4.0-rc2/`、[说明](v4.0-rc2.zh-CN.md)；RC1 盖板和上托盘复用，外壳更新 |
| **v4.0-rc1** | 单侧 SATA 方向修正、底层一体化、短滑抬盖的完整待实测候选版 | `models/v4.0-rc1/`、[说明](v4.0-rc1.zh-CN.md)；新外壳与新盖板成套使用，旧 Release 不变 |
| v2 | 已有实物反馈的旧托盘方案 | `models/v2`，保留不改 |
| v2-R | 内部螺丝固定实验 | `models/v2-retention`，不是当前免工具方案 |
| v3 / v3.0 | 三个托盘 + 三片独立限位框 | `models/v3`，标签 `v3.0` 固定在 `a675a8b3467316f5444930ef6d1a1fd0e53bebea` |
| v3-S | 一体拨扣方案工作名称 | `models/v3-simple`，几何基准提交 `cc9afd5bc0aef89c80ddbaa6241953b412729875` |
| **v3.1** | 一体拨扣方案的完整实测发行版 | **`models/v3.1`，标签 `v3.1` 与 GitHub Release** |
| **v3.2-rc1** | 修订外壳锁扣、托盘槽口并明确配置支撑的待实测候选版 | `src/build_v3_2.py`、`models/v3.2-rc1/`、[说明](v3.2-rc1.zh-CN.md)；不覆盖 v3.1 |
| **v3.2-rc2（仅 A 试件）** | 修复小盖板倾斜下落，重用 RC1 小盖板；非完整套件发行版 | `models/v3.2-rc2-latch-check/`、[范围与打印说明](v3.2-rc2-latch-check.zh-CN.md)；完整外壳和托盘仍为 RC1 |

v3.1 单件几何与 v3-S 相同，外壳 / 滑盖与 v3 相同；只有托盘方案需要成套替换。v3.1 不使用旧限位框，不能与 v2 / v2-R 零件混装。小样与整盘文件也应取自对应目录，不要凭 `first-test-all.stl` 的同名文件判断版本。

版本号描述设计快照，不表示已经通过实物验证；v3.1 首次发布标记为预发布。几何检查、参考切片、实物装配和批量可靠性是不同阶段，验证表仅填写实际观察。

## 发布规则

1. 修改源代码，生成单件、整盘、预览和清单，再完成几何与导入检查。只在需要时重新跑切片对照。
2. 将源代码与生成物一起提交；确认对应提交的 Windows / Linux CI。
3. 创建不移动的标签。以标签对应提交生成 Release 下载包，记录 SHA-256 和提交号。
4. 发布后不覆盖旧标签或同名附件。模型、公差、功能切片配置改变时发布新编号，如 v3.1.1 / v3.2；兼容性在更新记录明确说明。
5. 原型反馈写入对应版本实测表，记录机器、材料、层高、文件校验、打印日期和完整结果。不要把后来版本的测试结论回填到旧版本。

最少盘数结论仅针对单套、固定平放方向和不叠印。批量十套的 15 次任务是一种已检查方案，不作全局最优声称。

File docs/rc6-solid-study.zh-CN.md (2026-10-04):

# RC6 整块支撑研究

依据 RC5 拆除前即有散丝的实物反馈，取消异材锁键、分散齿和分体永久压条。保持完整盒子永久几何、3.2 mm 孔、既有工艺及冲刷配置，改变可拆的专用材料支撑。

## 完整两盘成本

| 方案 | 时间 | 换料次数 | 专用材料总量 | 全部耗材 |
|---|---:|---:|---:|---:|
| 前轮高把手整块初筛 | 5:28:37 | 46 | 26.86 g | 183.38 g |
| 本轮低把手，局部顶高 5.0 mm | 4:51:09 | 32 | 18.78 g | 167.66 g |
| 本轮较高把手，局部顶高 5.4 mm | 5:01:54 | 36 | 21.10 g | 172.16 g |

耗材均含正常擦料塔与冲刷。5.0 mm 候选的实际专用支撑体约 0.50 g，剩余大部分开销来自换料。对比基线 RC5 一体锁键方案 4:54:32，仅少约 3 分 23 秒；对比历史 RC4 选择性接触层方案 4:10:29 仍更慢。支撑更大并不必然使总时间更长，跨越多少换料层更重要；但这些结果只适用于已切片的组合，不能把单项节省直接相加。

把手从内侧向外以 45°底面长出，末端厚 1.0 mm，整块宽度延续接触面的宽度。5.0 mm 版本的外伸约 0.85 mm（DIMM）/0.95 mm（C），较高版本增加 0.4 mm；能否方便手指施力尚未知。新把手在高于顶棚接触面的位置留出间隙，避免与保留件融合。

## 为什么选择低把手

两档完整几何及 660 个支撑取出姿态通过。5.0 mm 两盘的 20 个支撑均从首层起单体连续，并保持逐层连续；最低下方 PLA 投影覆盖约 85.6%，最低顶棚接触区刀路覆盖约 98.6%，最长未覆盖扫描段 0.45 mm。全部 10 个安装孔与 8 条弹臂通道通过刀路检查。

5.4 mm 在其中一个固定端接触区出现 0.60 mm 的局部刀路空段，超过本轮 0.50 mm 的筛选界限，因此没有通过完整细查，也没有作为本次交付候选。0.50 mm 是约一条标称 0.42 mm 挤出线宽加采样/边缘余量的工程筛选值，不是物理失效阈值。不能据此断言较高把手实物一定更差。

本次接触区域填为完整块体，不再把“越稀疏越好”作为目标。接触面积增加可能令取出力上升。每层连通及下方投影覆盖只能排除某些明显不稳定的几何，不能模拟异材附着力、喷嘴拖动或热变形；RC5 失败已经证明连通性通过不等于实际可靠。

## 无支撑对照的边界

研究副本还去掉整盒所有建模局部支撑，并保留相应禁支撑区域。初步切片约 3:06:54、0 次换料；尚未完整审核所有自动生成支撑，**不作为“整盒完全免支撑”的合格数据或生产下载**。

交付试件 N 则做了明确的全件刀路检查，自动支撑及专用材料均为零。其永久结构与 A 相同（仅标字不同），足以做同盘实物对照。局部接触面首个 PLA 层在下方没有直接承托；屋顶仍与周边永久结构连接，并非整个零件浮空。是否下垂、是否妨碍 DIMM 装入、是否能保持内存，要以实际结果决定。不会只凭“能切片”和照片中最终成形就移除生产支撑。

数据位于 [研究报告目录](reports/rc6-solid-study/)，可打印的局部试验见 [RC6 一盘指南](v4.4-rc6-solid-trial.zh-CN.md)。不发布研究整盒为新版生产工程。

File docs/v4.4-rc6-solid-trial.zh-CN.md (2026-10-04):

# v4.4 RC6：整块专用支撑与无支撑对照

RC5 的 DIMM 支撑在打印完成、尚未拆除时就出现散丝。RC6 取消细梳齿和 PLA/Support 锁键，把**可拆支撑体及把手全部做成连续的 Support For PLA 实体**；永久零件仍为普通 PLA。独立永久压条不再进入本轮试验。

本版只有一张局部测试盘，不是完整生产托盘。最新完整版本仍为 v4.3。

## 打印入口

[下载版本 ZIP](https://github.com/helixzz/rdimm-hdd-case/releases/tag/v4.4-rc6-solid-trial)，解压后以工程方式打开唯一的 **rdimm-4.4-rc6-solid-trial-plate-0-P2S-AMS2Pro.3mf**。

- P2S，0.4 mm 喷嘴，0.20 mm 层高，纹理 PEI 板，按层打印。
- 材料 1：Bambu PLA Basic；材料 2：**Bambu Support For PLA / GFS02**。映射到实际 AMS 2 Pro 槽位；不是 Support for PLA/PETG。
- 保留零件材料、禁支撑涂色和正常擦料塔，不要全局关闭支撑，也不要把全部自动支撑界面改成材料 2。专用支撑是显式建模的零件，切片中按材料识别。
- 双向冲刷仍为 800 mm³，不冲刷到模型、填充或支撑中。本轮没有用减少冲刷量或提高速度换取节省。
- 参考 **1 小时 03 分 14 秒，10 次换料**；PLA **20.49 g**＋Support **5.78 g**，总计 **26.27 g**，包含冲刷及擦料塔。实际专用支撑体约 0.117 g。

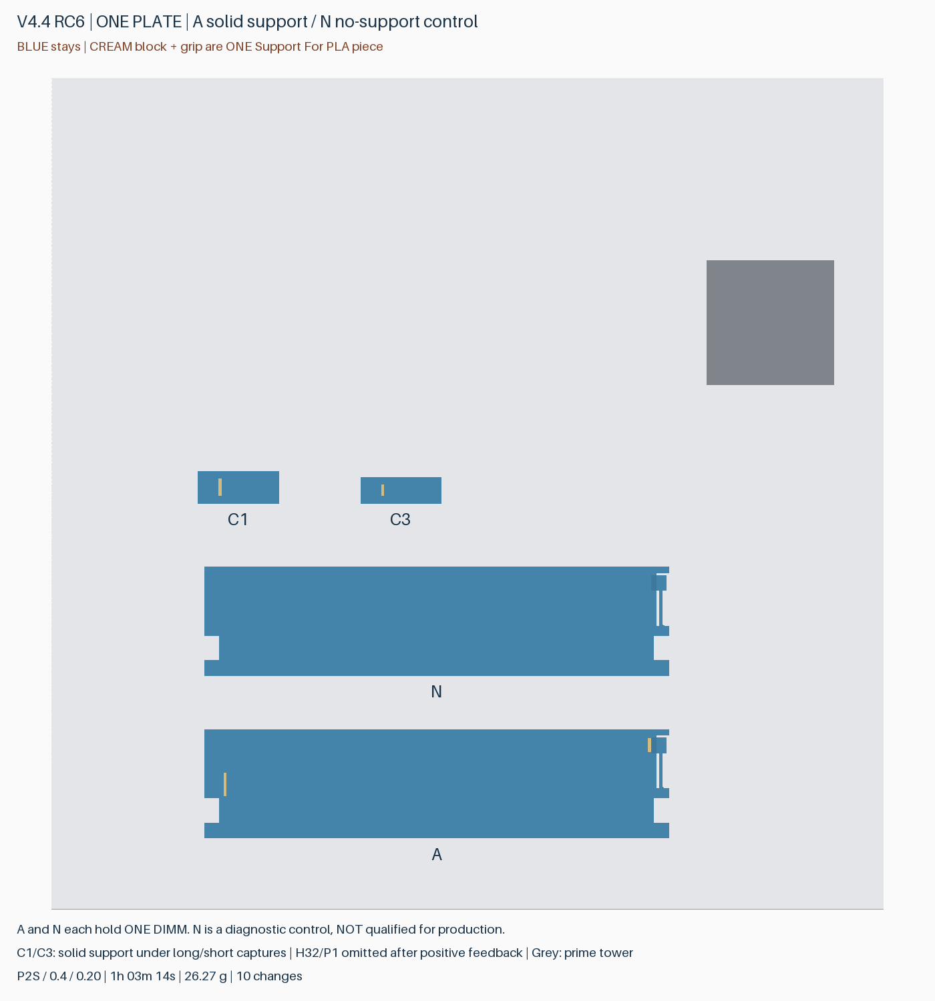
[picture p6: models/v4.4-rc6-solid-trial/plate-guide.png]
整盘识别


图中蓝色是保留件，米黄色是整块取出的专用支撑。只需两种耗材。几何参考 3MF 不含完整工艺，请使用 ZIP 中的已配置工程。

## 这盘验证什么

| 件 | 结构 | 检查内容 |
|---|---|---|
| A | 一体 DIMM 槽，固定端和活动端均使用整块支撑 | 支撑是否完整打印；是否容易整块取出；有无残留；永久齿头底面质量 |
| N | 与 A 相同的永久结构，仅识别字不同，完全不加局部支撑 | 首层悬空能否形成可用底面；是否下垂、缩窄槽口；DIMM 装卸与保持 |
| C1 | 长顶盖限位结构，整块专用支撑及把手 | 拆除难度、支撑残留、保留顶棚底面质量 |
| C3 | 短顶盖限位结构，同样采用整块支撑 | 与 C1 分别记录，避免只看丢弃支撑的表面 |

N 是诊断对照，**不是已经通过的免支撑方案**。同盘换料仍会发生，不可用 N 的打印时间推断独立单材料整套时间。H32、P1 已获得正面反馈，本轮不重复打印；完整研究继续保留 3.2 mm 孔及禁支撑。

## 拆除与记录

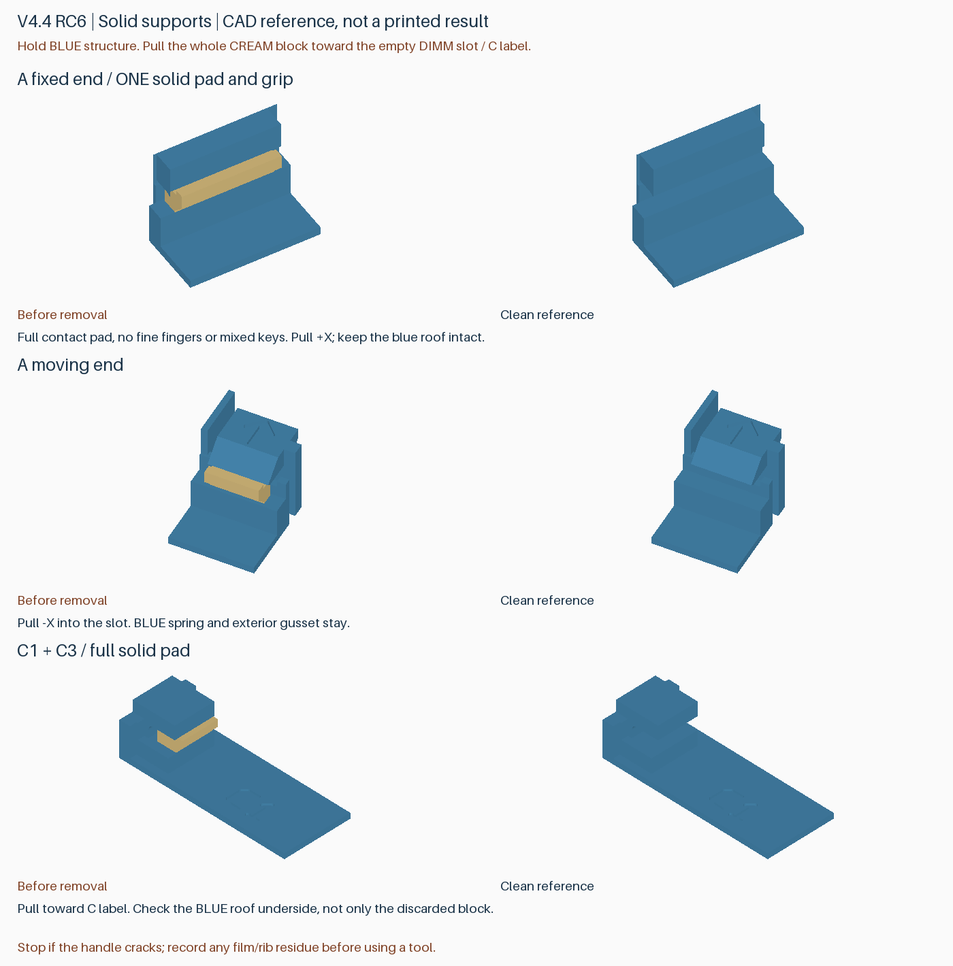
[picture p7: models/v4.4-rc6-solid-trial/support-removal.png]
保留件与整块支撑


1. 冷却后先观察并记录：是否已有散丝、翘起、脱落或缺失的支撑。这样能区分打印失败和拆除断裂。
2. 扶住蓝色刚性框架，抓住米黄色宽把手，向开放的槽内拉出。A 两端都向 DIMM 槽中央拉；C 向标字的一侧拉。把手与支撑同材同体，不需要拆开它们。
3. 不用活动卡簧或顶棚当支点猛撬。如果仍需工具、仍会断裂或留薄层，请按真实体验记录，不必强求徒手。
4. 检查留下的 PLA 顶棚/齿头底面，分别记录拉丝、下垂、坑洞、残料。**支撑容易取下与功能面打印良好是两项不同指标。**
5. N 无支撑可拆。先与 A 比较槽口与底面，清掉松散碎屑后再轻试 DIMM；放不进时不要硬压。检查活动舌片回弹，以及轻微翻转时内存是否会脱出，不进行带真 DIMM 的跌落试验。

建议反馈格式：A 固定端 / A 活动端 / C1 / C3：打印是否完整、徒手或工具、残留、永久面质量；N：底面质量、DIMM 装卸、保持效果。

## 筛选与验证

完整产品先比较了两档实心宽把手：5.0 mm 顶高方案约 **4:51:09 / 32 次换料**；5.4 mm 约 **5:01:54 / 36 次换料**。本盘采用 5.0 mm；比上一轮未发布的高把手整块候选 **5:28:37 / 46 次**少约 37 分 28 秒、14 次换料。仍慢于历史 RC4 选择性界面候选约 4:10:29；没有实际制造时间或质量保证。

整盒 20 组支撑通过取出路径和实际刀路检查；所有 10 个安装孔无支撑，8 条自由弹臂通道无干涉。完整几何验证含 DIMM、载条托盘、底层释放与顶盖动作。此前版本的永久几何没有在本轮被改形。

这次额外检查了支撑**从第一层开始就是单个连续区域，并且逐层连续**。本盘首层与下方 PLA 刀路的投影覆盖约 97.1%–99.9%；规定接触区域的顶面刀路覆盖约 98.9%–100%。覆盖采样间距 0.05 mm，仍有最多 0.40 mm 的局部刀路间隙，不能称为每处绝对贴合。N 的两个接触面首层下方均没有直接承托。

这些是几何和名义挤出刀路检查，不是粘接、喷嘴碰撞、热变形或剥离力仿真。宽底面比细齿更连续，但能否稳定打印、是否更好拆、会不会因接触面积变大而更粘，都需要本轮实测。详见 [整盒比较报告](rc6-solid-study.zh-CN.md)。旧版标签和附件不覆盖。

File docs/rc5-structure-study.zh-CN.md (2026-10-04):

# RC5 完整产品结构比较

目标是改善整个 8 条 DIMM 收纳盒的制造和后处理，试件只用于筛选之后的实物复核。本轮没有发布新的完整生产套件。

## 同一设备与工艺下的整套切片

P2S / 0.4 mm / 0.20 mm，PLA Basic + Support For PLA，正常擦料塔，双向冲刷均 800 mm³，不冲刷进功能件。未提高打印速度或改变外壁/顶面质量设置。耗材包括冲刷和塔。

| 完整方案 | 两盘合计 | 换料 | PLA | Support For PLA | 总耗材 |
|---|---:|---:|---:|---:|---:|
| RC4 选择性双材料，历史基线 | 4:10:29 | 12 | 约 139.95 g | 7.23 g | 147.19 g |
| A 连体梳齿 + PLA 锁键把手 | 4:54:32 | 32 | 149.22 g | 18.67 g | 167.88 g |
| B 固定端分体压条；其余同 A | 4:55:30 | 32 | 149.65 g | 18.46 g | 168.11 g |

基线已知的实测缺点是固定端支撑把手先断，专用材料接触薄片残留。A 用连体专用材料梳齿替换分离的上下薄片，并通过 PLA 把手的几何锁键拉出；专用材料跨越更多层，增加换料。因此 A 比基线多约 44 分钟，不能称为效率提升。

B 每个完整托盘/底座增加一根永久压条，整套增加三件。固定端的八个狭槽不再需要支撑，但活动卡簧和顶盖限位仍需专用材料；相关层仍要换料，整套次数没有下降。当前 B 比 A 多约 58 秒、0.23 g；专用材料少约 0.21 g。它主要验证是否能用一次装配换掉困难清理，并不证明生产效率更好。

此前全专用材料把手方案约 5 小时 29 分只是初筛；早期锁键方案约 4 小时 39 分未通过实际刀路锁键检查。最终加大锁键、抬高连接后采用上表结果，不能沿用早期时间。

## 结构与工艺筛选

- A：固定端稀疏齿间隙 0.8 mm，活动端更小；连接脊把不同齿连为同一可取出件。两种材料实体不重叠，名义锁键能带动支撑；实际剥离力与层间断裂仍未知。
- C：保留 RC4 的两端 0.6 mm 接触齿与既有跨度，再接上取出脊。没有简单把 DIMM 支撑间距套用到长顶棚。新增连接脊会增加局部接触，不能说所有接触面积均比 RC4 小。
- B：两个蘑菇形安装柱承受上提/侧移，外侧小舌片阻止反向滑出。压条倒置打印，安装槽用斜面收口，消除早期设计在内部平顶生成的自动支撑。永久零件全部 PLA，固定端无专用材料。
- B 安装条长度避开已有外壳立柱；保留原 PCB 座面与压住 PCB 的位置。完整托盘仍按原动作进出外壳，日常 DIMM 取放不需要拆压条。
- H32 保持 3.2 mm；修复 P1/P2 旧试件漏涂孔内禁支撑的生成流程，本次只留 P1 复核实际外壳截面。

## 验证边界

每种完整方案检查 512 个参考 DIMM 姿态、242 个载条托盘进入姿态、1520 个底层释放姿态、132 个顶盖姿态。B 另外逐件检查 80 个压条装卸位置、11 个舌片抬起位置及五方向几何止挡。抬起形状是名义变形示意，非材料力学仿真。

完整 A 的 20 组、B 的 12 组专用支撑经过名义实际挤出线宽的连接/锁键/屋顶覆盖检查；两种整套各 10 个孔内无自动支撑，8 条自由弹臂通道无材料干涉。B 的三根永久压条及固定端无自动支撑。打印盘/擦料塔无平面重叠，路径在 256 mm 范围内。

RC5 最终测试盘的屋顶下方最长未覆盖 Y 向扫描段：A 固定端 0.50 mm、A/B 活动端 0.40 mm、C1 4.25 mm、C3 2.45 mm；网格步长 0.05 mm。这是刀路覆盖指标，不是热变形或桥接质量预测，也不意味着每层所有齿都已相连。不同高度的齿由上升连接脊最终连通。

报告见 [结构研究数据](reports/rc5-structure-study/)，最终测试盘见 [RC5 说明](v4.4-rc5-peel-trial.zh-CN.md)。目前仅几何与切片通过，不能宣称零残留、指定拔力、抗跌落或量产验证完成。下一步以同盘 A/B 的清理时间、安装时间、残留和保持表现选择路线；进一步分拆其他结构才可能消除剩余换料，但尚未验证。

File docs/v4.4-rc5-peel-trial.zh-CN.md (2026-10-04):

# v4.4 RC5：一体支撑与分体压条对比盘

一盘打印两种 DIMM 固定结构，比较拆支撑、装配和实际保持效果。本版为局部试件，**不能作为完整托盘装进旧外壳**。最新完整版本仍是 v4.3，旧版附件保持不变。

## 下载与打印

[下载版本包](https://github.com/helixzz/rdimm-hdd-case/releases/tag/v4.4-rc5-peel-trial)，解压后只打开其中的 **rdimm-4.4-rc5-peel-trial-plate-0-P2S-AMS2Pro.3mf**，选择打开为工程。已经排成一盘；不要用仓库的无配置几何 3MF 替代。

- P2S、0.4 mm 喷嘴、0.20 mm 层高、纹理 PEI 板，按层打印。
- 逻辑材料 1：Bambu PLA Basic；材料 2：**Bambu Support For PLA / GFS02**。发送前映射到实际 AMS 2 Pro 槽位。本工程不是 Support for PLA/PETG 配方。
- 保留对象/零件材料、局部禁支撑、正常擦料塔和冲刷配置。梳齿是显式建模的材料 2 零件，不会在“自动支撑”类别里显示。
- 不要把所有自动支撑界面全局改成材料 2；其余自动支撑采用 PLA 和已有间隙。不要启用冲刷进功能件、填充或支撑。
- 参考时间约 **1 小时 21 分钟**，**12 次换料**，总耗材约 **34.1 g**，包括冲刷与擦料塔。精确值见随包切片报告；实际时间与机器准备、耗材状态有关。

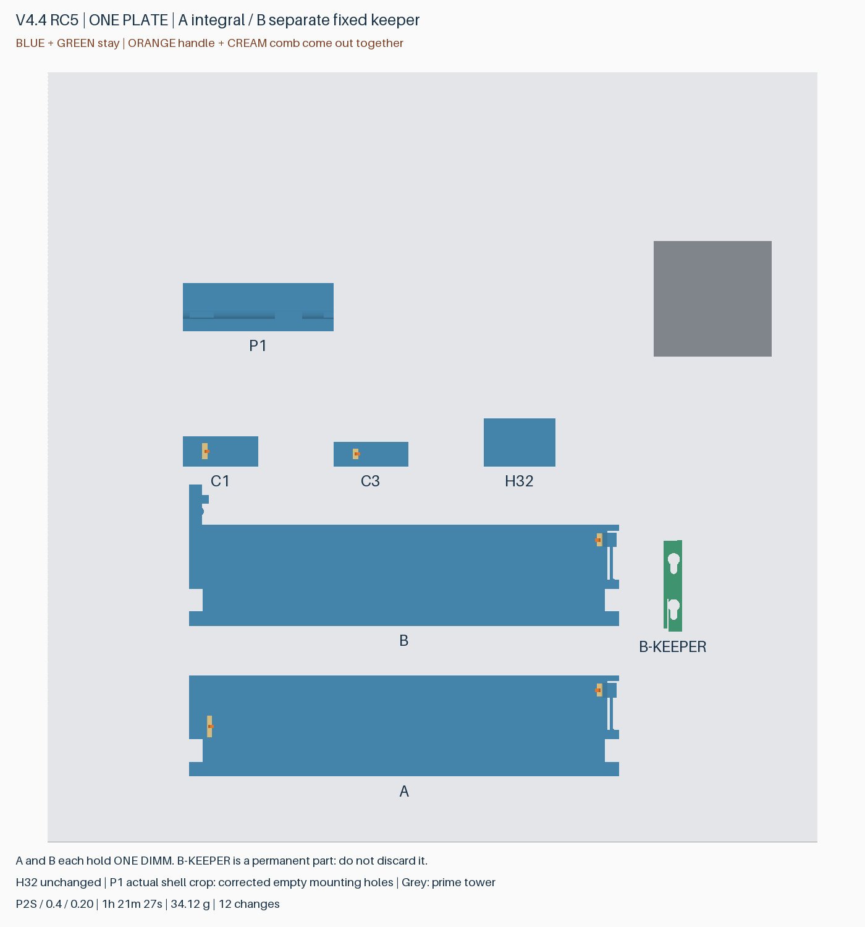
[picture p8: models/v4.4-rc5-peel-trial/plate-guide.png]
整盘识别图


图中颜色用来区分功能，不要求实际使用四种颜色。整盘仅两种材料。**B-KEEPER 是永久压条，不是要扔掉的支撑。**

## 各件怎么测试

| 标记 | 本次改变 | 重点记录 |
|---|---|---|
| A | 一体固定端；专用材料梳齿连成整体，PLA 把手通过几何锁键带动梳齿 | 固定端/活动端分别能否徒手取出；是否仍残留薄层；把手是否先断 |
| B + B-KEEPER | 固定端改为独立 PLA 压条，倒置打印后装配；活动端与 A 相同 | 压条能否无工具安装；是否松动、翘起；DIMM 是否易装且留在槽内 |
| C1、C3 | 长/短顶盖限位结构，支撑改成连体梳齿与锁键把手 | 侧向取出难度、残留、限位表面完整性 |
| H32 | 保留已通过试验的 3.2 mm 侧孔/底孔 | 作为孔径、孔顶质量的对照 |
| P1 | 实际外壳截面；补上之前漏掉的孔内禁支撑 | 两个安装孔均应没有自动支撑；观察孔顶与底板过渡 |

H32 和 P1 的孔内已逐一核对实际刀路，没有自动支撑。P1 不是整个外壳的平整度或强度测试。

## A、C 支撑拆除

完全冷却后，扶住刚性框架，握住伸出的 PLA 把手，沿槽的开口方向向外拉出；A 是朝 DIMM 槽中央，C 是远离限位顶棚向敞开侧。可以小幅侧向松动，但不要拿活动卡簧或顶棚当支点猛撬。取出的应是把手和相连梳齿整体。

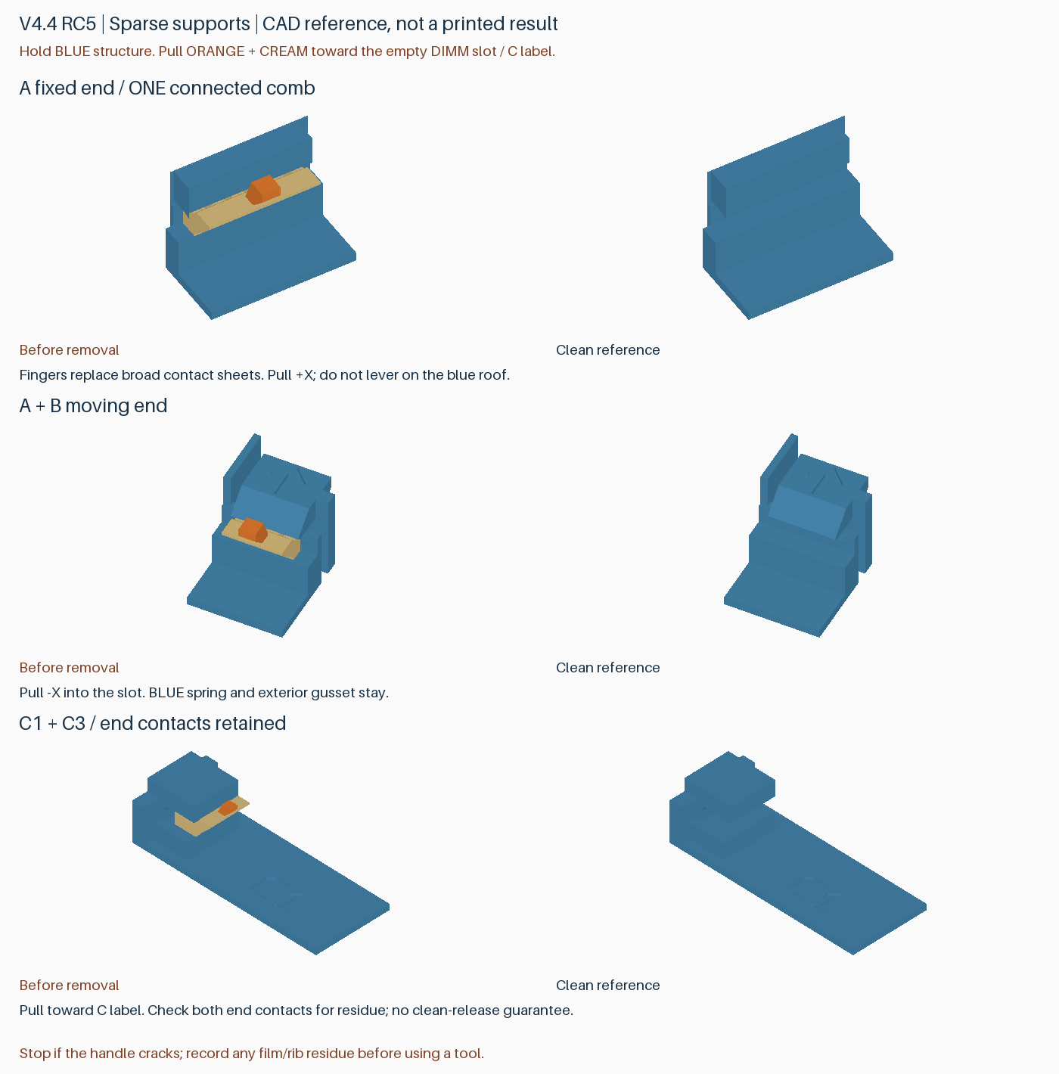
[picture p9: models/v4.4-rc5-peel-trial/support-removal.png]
支撑与保留件识别


DIMM 支撑采用稀疏接触齿；C 保留上轮端部接触位置，没有一律扩大跨度。连接脊负责带出专用材料，但能否避免残留仍需实测。若再次发生把手断裂或薄层残留，请先记录位置，再清理；不能用切片连通性替代实际剥离结果。

## B 压条装配

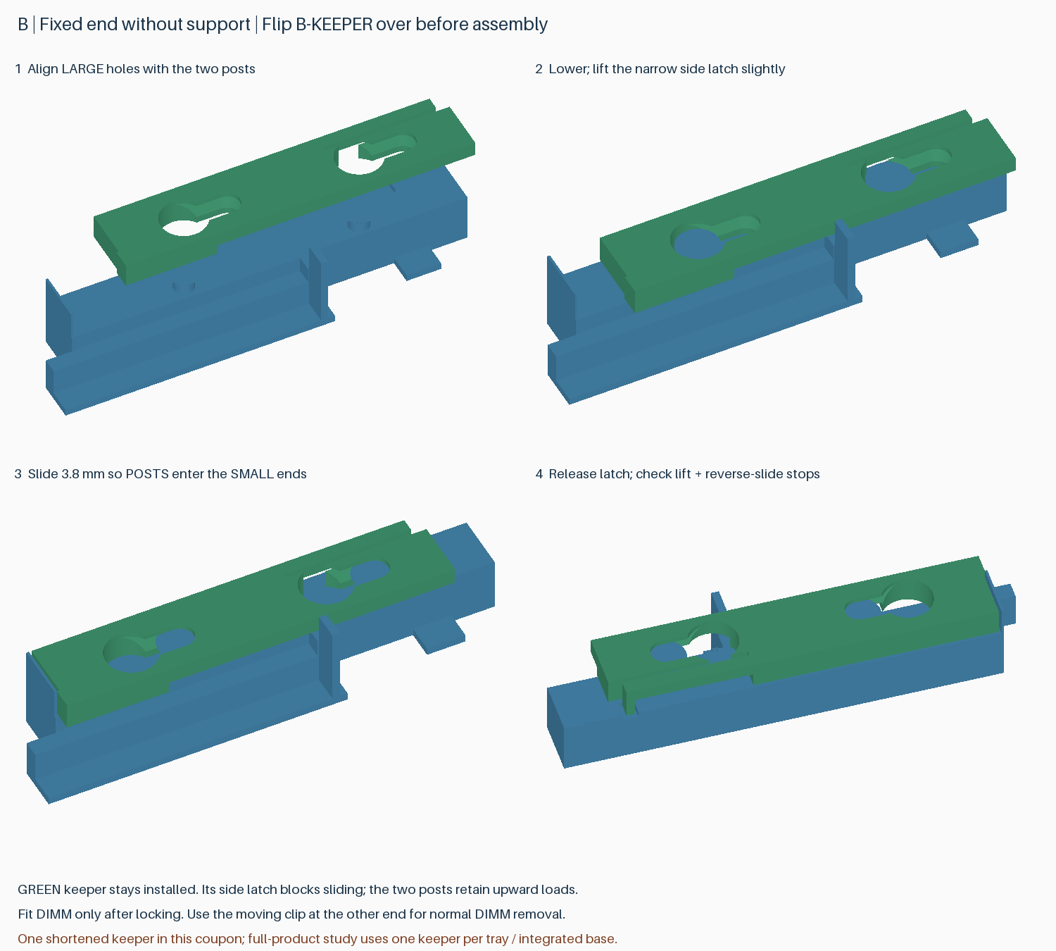
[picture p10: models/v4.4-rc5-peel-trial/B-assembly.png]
B 装配示意


1. 拿起 B-KEEPER，翻至压住 PCB 的短齿朝槽内、蘑菇形安装柱能进入大孔的方向。
2. 将两个大孔对准 B 上的两根安装柱，放到底。
3. 轻抬压条外侧的小止退舌片，沿长条方向滑动 **3.8 mm**，让柱头进入窄槽；松手使止退齿落入凹位。只需轻抬到能滑动，不要大幅掰折。
4. 轻提压条确认没有脱开，再按原方式从另一端拨开活动卡簧，装入 DIMM。日常取放内存无需拆这根压条。

若需拆压条，先取出 DIMM，轻抬止退舌片、反向滑回大孔位置后抬出。B 试件左端的延长底座是单槽试验的安装区域，不代表完整托盘会向外加长。

## 已检查与尚待验证

已检查完整 8 槽盒子的 DIMM 装卸、托盘放入、顶盖动作，以及分体压条装卸路径；两种完整候选的所有 10 个安装孔、8 条活动卡簧通道和相关材料刀路也已核对。本盘 5 组支撑的打印刀路线宽/层间连接与把手锁键、4 个孔的禁支撑、B 固定端及压条无自动支撑均通过检查。

这些检查不能预测粘接力、残留、翘曲、装配手感、疲劳或跌落保持能力。请分别反馈 A 固定端/活动端、C1/C3 的拆除和残留，以及 B 的装配难度和保持效果。先空件装配，确认没有碎屑或干涉后再放 DIMM。

本轮优先比较后处理方式，**并非提速版**。完整候选 A 约 4 小时 54 分，B 约 4 小时 55 分，均 32 次换料，慢于旧选择性双材料候选的约 4 小时 10 分。B 只消除了固定端狭槽支撑，其余结构仍需换料；详细成本与局限见 [完整结构比较](rc5-structure-study.zh-CN.md)。

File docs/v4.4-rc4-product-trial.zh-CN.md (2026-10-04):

# v4.4 RC4：完整产品研究的实物验证盘

> **2026-10-04 实测更新：** A 固定端把手仍会先断，A/C 接触层仍有残留；H32 表现良好。P1/P2 漏加安装孔禁支撑，原附件确有孔内支撑。详见[实物反馈与修正复核](validation-v4.4-trials.zh-CN.md)。原发布附件保持不变，本盘未通过免工具拆净目标，不建议为重现这些已知问题再次打印。

**一盘六件，P2S / 0.4 mm / 0.20 mm / AMS 2 Pro，PLA Basic＋Support for PLA。**

参考 **1 小时 03 分 15 秒，6 次换料**；PLA **21.45 g**＋Support for PLA **3.55 g**，合计 **25.00 g**，包含冲刷及擦料塔。时间来自 Bambu Studio 2.8.2.61 切片估算，不含取件和清理。

下载本版本的 `rdimm-v4.4-rc4-product-trial-P2S-AMS2Pro.zip`，解压后打开其中唯一的 `.3mf`，选择 **作为工程打开**。完整生产版本仍是 v4.3；本盘用于复核已经完成整套研究的候选，不是替换外壳或托盘。

## 打印前

1. 材料 1 对应 **Bambu PLA Basic**，材料 2 对应 **Bambu Support For PLA**（不是 Support for PLA/PETG）。发送时映射到实际 AMS 槽位。专用支撑料未到货时请先保存工程，不要将材料 2 也映射成普通 PLA。
2. 保持 **100% 比例、按层打印、Textured PEI Plate**，保留排版、擦料塔和全部零件。不要拆分组件、合并成 STL 或统一分配成一种材料。
3. P2 已设置独立对象参数；P1 及其他试件保持基准参数，无需手动切换配置。
4. **自动支撑界面显示材料 1（PLA）是有意设置。** 难拆位置的 14 个专用接触体已作为模型部件分配材料 2；不要把全局自动界面改成材料 2，否则会增加不必要的换料。

保留普通擦料塔、两方向各 800 mm³ 冲刷，关闭冲刷到成品/填充/支撑。这是沿用的试验设置，实际换料残留与结合强度仍需观察。

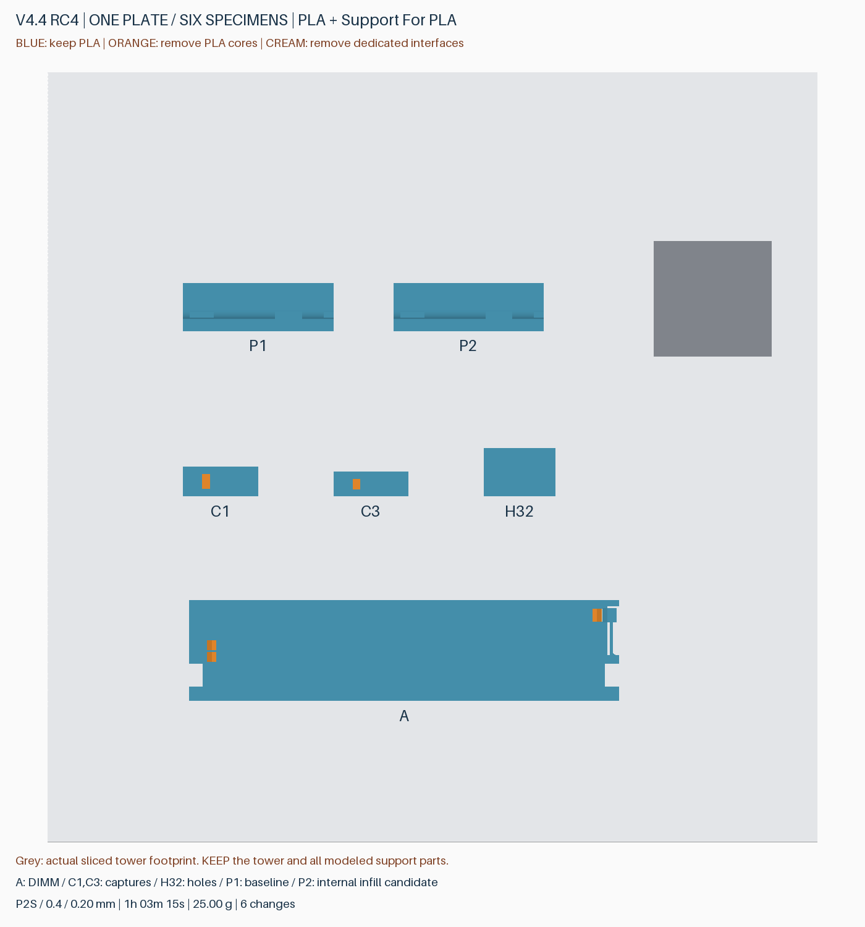
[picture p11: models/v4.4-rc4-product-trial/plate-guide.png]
六件一盘排版


## 六个试件

| 标记 | 完整产品对应位置 | 验证重点 |
|---|---|---|
| **A** | 上层托盘的一个完整 DIMM 槽，保留 3 mm 卡簧基座和原接触尺寸 | 三个抬高的支撑把手，取消底脚，上下专用接触层；拨片下方增加 45° 斜撑，不再生成此处额外自动支撑；验证残留、DIMM 装卸和回弹 |
| **C1** | 较长的顶盖限位结构，保持功能截面、缩短下方立柱 | 加宽把手＋上下专用接触层，水平抽出是否顺畅，槽内是否干净 |
| **C3** | 较短的顶盖限位结构 | 与 C1 相同；短结构单独验证 |
| **H32** | 标准孔深的侧孔与底部盲孔，各一个 | 已选定 **3.2 mm** 孔径、孔内无支撑；检查孔顶、有效深度及硬盘螺丝/免工具销钉配合 |
| **P1** | 实际外壳底板＋侧壁圆弧/加强棱的 50 × 16 × 12 mm 截段 | 基准：内部实心线宽 0.42 mm、稀疏线宽 0.45 mm、不合并填充层 |
| **P2** | 与 P1 相同的截段，仅刻字不同 | 候选：内部实心/稀疏线宽 0.50 mm，合并部分稀疏填充层；比较表面和局部刚度 |

P1/P2 保持原 Z 高度和打印朝向，几何来自完整研究外壳 X35–85 / Y0–16 / Z0–12 mm 区域；除刻字外一致。实际刀路确认 P2 出现 0.4 mm 稀疏填充层，P1 为 0.2 mm；两者顶面仍为 0.42 mm 线宽、0.2 mm 层厚，外墙参数不变。

未加入尚未入选的扩大残留凹槽、激进减薄、减少冲刷或无擦料塔方案。小试件不能验证四张托盘满盘时的翘曲和粘附。

## 支撑怎么拆

冷却后取件。下图为实际 CAD 对照，**蓝色保留；橙色 PLA 芯和米白色专用接触层去除**。橙色和蓝色仅为示意，实际二者使用同一种 PLA。

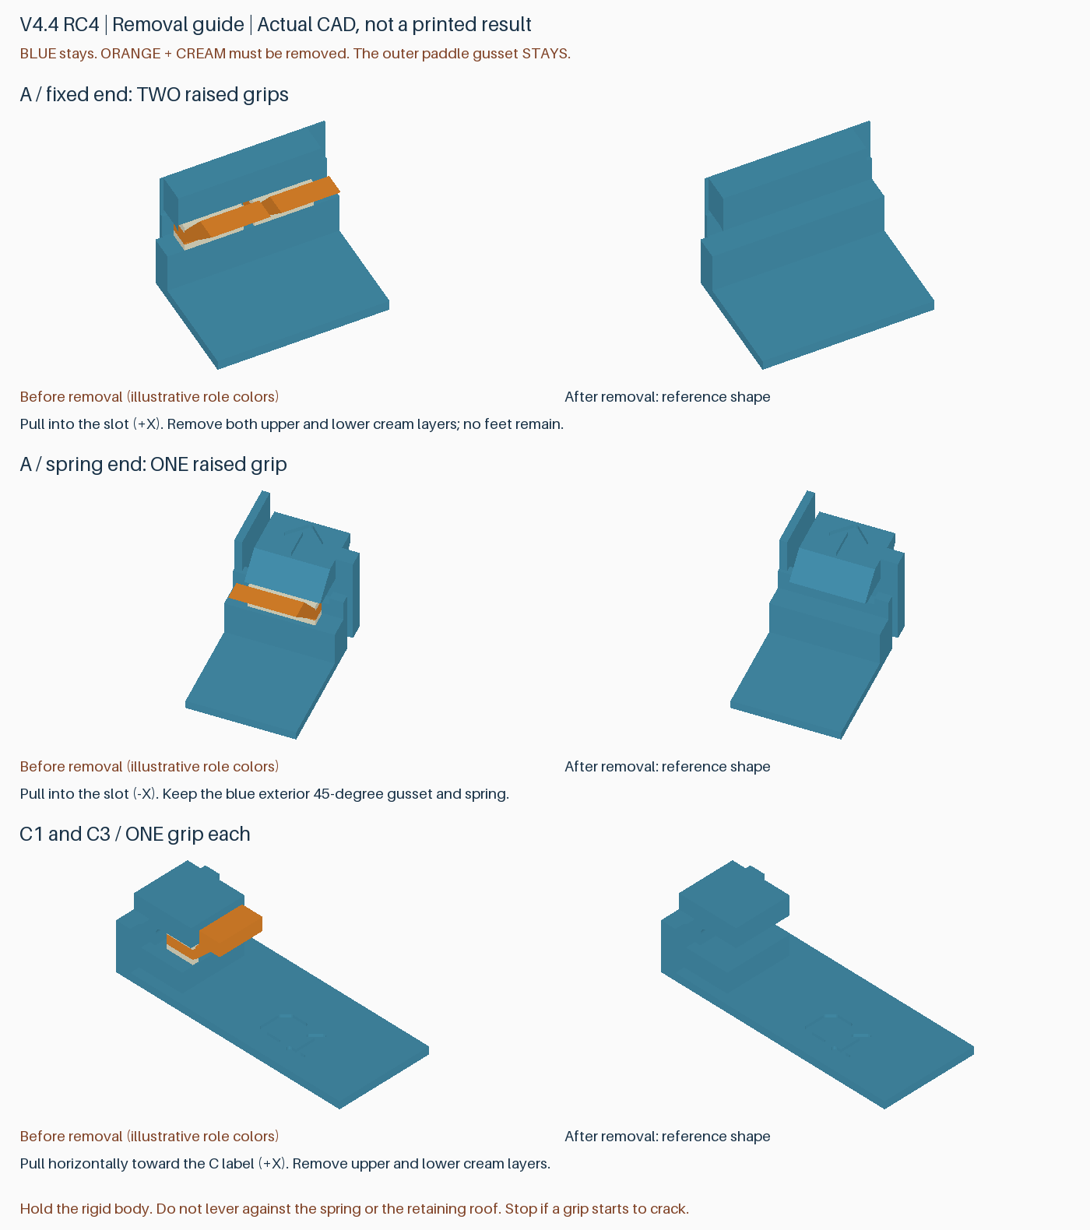
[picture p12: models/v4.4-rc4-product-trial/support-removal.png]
拆除前后对照


- **A 固定端两个把手、卡簧端一个把手**：扶住刚性框架，逐个水平向 DIMM 槽中心拉。去除上下薄接触层。卡簧头、外侧斜撑和基座均保留。
- **C1/C3 各一个把手**：扶住底座，向刻有 C 字样的一侧水平拉出。上下接触层均需去除；不要用顶盖限位唇当撬动支点。
- **H32**：孔内没有设计支撑，不应有需要拔出的实心塞；检查桥接垂丝。先记录原状，再尝试螺丝/销钉。
- **P1/P2**：不用拆内部填充。先比较表面，再用相近的小幅手力比较弯曲感即可，不需要掰断。

若把手先变白、裂开或断裂，停止加力并记录位置，再判断是否需要镊子辅助。装入 DIMM 前清除可脱落残渣，确认卡簧可活动；不要用 DIMM 挤压未拆干净的支撑。

## 打印后反馈

| 试件 | 建议记录 |
|---|---|
| A / C1 / C3 | 能否徒手抽出；是否需镊子/撬动；把手是否完整；清理耗时；上下界面有无残留 |
| A | DIMM 是否自然入槽、两端元件避让、卡簧回弹和固定效果；在软垫上方轻轻翻转检查是否固定，不做跌落测试 |
| H32 | 侧孔/底孔是否直接可用、孔顶垂丝、螺丝咬合或过紧、免工具销钉配合 |
| P1 与 P2 | 顶面凹陷/透出填充纹、侧面横纹、圆弧过渡；P2 是否明显更软或更易裂 |

优先验证 A/C 的后处理。若 P2 表面或刚度变差，即使更快也不采用；完整产品该工艺候选仅约省 10 分钟。小截面只能筛选明显问题，不能证明整盒刚度、长跨度顶面、满盘热变形或运输保护能力。

## 已完成的检查

- 六件及独立支撑体均为连通封闭网格；五个支撑芯共 **165 个水平抽出位姿**通过，无材料实体重叠。
- 对应完整产品的 512 个 DIMM、242 个托盘进入、1,520 个底层拆卸、132 个盖板位姿检查通过。
- 导入后全部三角形对应保留，最大顶点舍入约 **0.0000108 mm**；436 个局部禁支撑标记保留。
- **14 个专用接触体**逐一核对实际材料及上下接触区域；卡簧自由段不被填充；H32 两孔无自动支撑，外侧拨片下无额外自动支撑。
- P1/P2 参数和实际刀路差异通过；擦料塔与模型平面包围盒最小间距约 **36.53 mm**；切片无警告。这些不是粘接力、热翘曲、疲劳或跌落仿真。

研究依据：[整套优化比较](full-product-optimization.zh-CN.md)。本版通过实物后再整合下一完整版本，不覆盖既有发布文件。

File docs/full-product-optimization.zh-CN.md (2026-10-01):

# 完整产品制造优化研究

本轮以 **8 条容量的完整盒子** 为对象：外壳（含底层槽）、盖板、两张活动托盘，共四个成品零件。评价整套打印时间、材料、装配和后处理；试件只用于筛选后的实物复核。本页为研究记录，未生成新的生产版本，已发布 v4.3 和双材料 RC3 试件不变。

## 建议优先采用的方向

1. **选择性使用 Support for PLA**：只在难接近的 DIMM 固定结构和顶盖限位结构内，放置明确建模的专用接触层；易接近的普通支撑仍用 PLA。配合抬高的支撑把手、取消底脚，以及八处拨片下方的 45° 斜撑。
2. **批量时两套分三盘打印**：两外壳、两盖板、四托盘分别集中打印。整套实际切片显示，平均每套比双材料逐套打印少约 33 分钟，专用支撑耗材接近减半。
3. **内部线宽优化作为次级候选**：单独加宽内部填充每套仅省约 6 分钟；与隔层稀疏填充合用可省约 10 分钟。保留候选，但须验证顶面和刚度，不能因切片更快直接升级生产配置。

这里没有一个已证明同时提高所有指标的方案：双材料方案仍比单材料打印慢。它是否值得，取决于实际拆支撑、清理和返工时间能减少多少；这些还没有实测。

## 统一基准与整套结果

环境：Bambu Studio **2.8.2.61**，P2S / 0.4 mm 喷嘴 / 0.20 mm 层高 / Textured PEI，PLA Basic；双材料使用 **Support For PLA（GFS02）**。AMS 实际槽位仍需映射。以下时间是切片估算，材料包含冲刷及擦料塔；不含冷却、换盘和人工清理。

所有本轮几何共用 **3.2 mm 侧面和底部安装孔**，保留孔轴位置和名义深度（侧 5.7 / 底 5.3 mm），并删除活动托盘两处旧角部薄片及底部细条。未扩大 DIMM 槽，不改四件成品的数量、容量或 147 × 101.6 × 26 mm 外包络。

| 完整一套，均为两盘 | 切片时间 | 总耗材 | 其中 Support for PLA | 换料次数 |
|---|---:|---:|---:|---:|
| 单材料公共对照 | 3:09:24 | 125.36 g | 0 | 0 |
| 单材料＋八处拨片斜撑 | 3:08:09 | 125.19 g | 0 | 0 |
| 所有自动支撑界面均用专用料 | 6:06:36 | 192.38 g | 30.42 g | 50 |
| 建模内部接触层，其他自动界面仍用专用料 | 5:20:58 | 173.62 g | 20.92 g | 34 |
| **选择性专用界面（首选材料策略）** | **4:10:29** | **147.19 g** | **7.23 g** | **12** |

八处斜撑在真实完整产品上仅省约 **75 秒**，主要价值是免去八处额外自动支撑的清理。先前四试件盘节省的十几分钟，不能外推到成品。

选择性方案相对“所有自动界面都用专用料”减少约 **1 小时 56 分钟、76% 专用料**。全套共有 28 个可拆 PLA 支撑芯和 64 个明确建模的专用接触体：外壳 10 芯 / 28 接触体，每张托盘 9 芯 / 18 接触体。抬高把手避免底脚形成更多专用接触层；八个拨片斜撑消除其下方的额外自动支撑。

这 64 个接触体在切片中属于模型挤出，逐体分配专用料。其余自动支撑设置为 PLA，顶底 Z 间隙 0.2 mm、界面间距 0.25 mm；没有把内部建模的专用接触体改回 PLA。保留两方向 800 mm³ 冲刷、普通擦料塔，关闭冲刷到成品/填充/支撑。800 mm³ 是沿用的保守试验设置，尚无实际换料污染验证。

## 批量排版：两套三盘

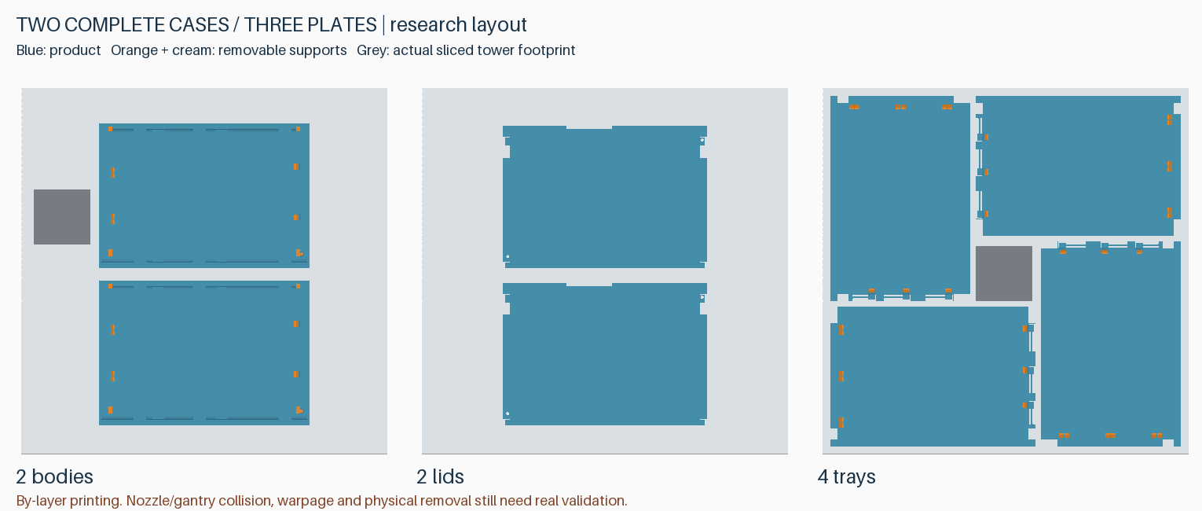
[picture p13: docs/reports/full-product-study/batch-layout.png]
两套完整盒子三盘排版


蓝色为成品，橙色及浅色为可拆支撑；灰色小方块为实际 G-code 中擦料塔的铺料包络。

| 打印盘 | 内容 | 切片时间 | PLA | Support for PLA | 换料 |
|---|---|---:|---:|---:|---:|
| 1 | 2 个外壳 | 3:58:59 | 145.48 g | 4.86 g | 8 |
| 2 | 2 个盖板，单材料 | 1:05:45 | 48.50 g | 0 | 0 |
| 3 | 4 张托盘，中层/顶层各 2 | 2:09:29 | 71.21 g | 2.49 g | 4 |
| **两套合计** | **8 个成品零件** | **7:14:13** | **265.19 g** | **7.34 g** | **12** |

平均每套 **3:37:07 / 总计 136.27 g / 专用料 3.67 g**。相对同一选择性方案逐套打印，时间降低约 **13.3%**，专用料降低约 **49.2%**，两套从四次打印减为三次。每套的功能接触体和冲刷设置不变，只分摊换料及擦料塔成本。尚未叠加下面的线宽/隔层填充候选，不能把两组节省直接相加。

四托盘采用 90° 递进旋转排布，模型间距 4 mm，外缘约留 5.5 mm。已检查实际挤出线宽、塔底扩展和支撑路径：中央塔与模型包围盒最小平面间距约 **3.73 mm**，整盘挤出 XY 包络约 5.50–250.50 mm，无切片警告。采用按层打印。

这是名义铺料路径检查，**不是喷头/龙门机构全空间碰撞或热翘曲仿真**。满盘边缘的粘附、长托盘翘曲和不同方向表面差异，应由第一盘完整批量件验证，不能用小试件替代。也未证明这是数学上的全局最少盘数。

## 内部填充与精细程度

以下均使用同一选择性双材料完整两盘，网格和支撑标记完全相同，仅改变表内参数：

| 变动 | 整套时间 | 比 4:10:29 节省 | 总耗材 | 取舍 |
|---|---:|---:|---:|---|
| 填充方向 45° → 0° | 4:05:02 | 5:27 | 147.72 g | 仅约 2.2%，并略增料，不优先 |
| 内部实心线宽 0.42 → 0.50、稀疏线宽 0.45 → 0.50 mm | 4:04:35 | 5:54 | 147.28 g | 温和效率候选，需看顶面与实际挤出 |
| 自动合并稀疏填充层 | 4:05:30 | 4:59 | 146.14 g | 实际出现 0.4 mm 稀疏填充层，需验证支承与刚度 |
| 加宽内部线宽＋合并稀疏填充层 | 4:00:07 | 10:22 | 146.33 g | 数值最佳，仅约 4.1%；保留次级候选 |

这些方案均维持 12 次换料、专用料 7.23 g。逐段解析 G-code 确认顶面仍采用 0.42 mm 线宽及 0.2 mm 层厚，外墙线宽集合未改变；合并的是部分稀疏填充层，内部实心填充仍为 0.2 mm 层厚。内部标称线宽不等于所有窄缝路径均恒定 0.5 mm。

保持外表面参数只能减少变量，不能证明表面质量必然不变：内部支承、热积累与流量变化仍可能影响成品。本轮没有全局提速、削减墙数/顶底层、缩减冲刷量、停用擦料塔或采用实验性稀疏擦料塔。

## 检查覆盖与实物复核筛选

- 完整几何：512 个 DIMM 位姿、242 个装载托盘进入位姿、1,520 个底层拆卸位姿、132 个盖板位姿；单体连通及原有止挡检查通过。
- 完整选择性支撑：28 个支撑芯，水平抽出路径合计 924 个采样位姿；无模型/支撑体积重叠。几何可抽出不代表粘接力小或把手不会断。
- 切片：选择性基准、四个工艺候选和三张批量盘，共 13 盘实际路径审计通过。每套核对 64 个专用接触体、10 个无自动支撑安装孔、8 个卡簧自由活动通道；批量按两套检查。接触覆盖率保留为测量值，局部线缝/倒角不被描述成处处零间隙满接触。
- 总计比较 9 组完整单套方案及 1 组两套批量方案，21 盘实际切片，无警告。单套几何材料策略、内部工艺与批量摊销分别比较。

材料到货后的优先复核只保留 **两类**：① 原尺寸功能接触面＋选择性专用界面＋无底脚把手/拨片斜撑，检查拆除力、残留、装卸和卡簧回弹；② 同一功能截面的内部线宽/隔层填充对照，检查顶面及局部刚度。先验证①；②收益较小，不值得为省十分钟牺牲质量。局部残留让位凹槽暂不扩大应用，先观察专用料是否已经消除主要残留，避免无谓减薄限位结构。

通过局部复核后，再用第一套完整件检查全层装配、盖板操作和成品质量，并用第一盘真实批量排版检查整盘打印行为。**切片和几何审计不能证实界面粘接、材料混合、疲劳、冲击强度、热变形或表面粗糙度。** 后续按完整编号候选发版，禁止把研究文件当独立 hotfix 混入现有发布包。

## 证据与复现

[汇总数据](reports/full-product-study/summary.json) · [完整几何检查](reports/full-product-study/dual-selective-geometry.json) · [逐盘实际刀路审计](reports/full-product-study/toolpath-audits.json) · [批量切片与文件哈希](reports/full-product-study/batch-two-slicing.json)。同目录保留各模式逐盘时间、耗材、特征时间及工程/G-code 哈希，不提交本机配置、原始 G-code 或官方完整预设。

```text
python src/evaluate_full_product.py --geometry-only
python src/evaluate_full_product.py --bambu <Bambu Studio executable>
python src/evaluate_full_process.py --bambu <Bambu Studio executable>
python src/evaluate_product_batch.py --bambu <Bambu Studio executable>
python src/audit_full_product.py
python src/preview_product_batch.py
python src/summarize_full_product.py
```

切片复现需先用仓库既有 v4.3 和 RC3 配置准备脚本建立本机 `build/v4.3-unpainted-projects`、`build/v4.4-rc3-dual-trial-projects`，并安装所列 P2S 耗材预设。几何检查无此本机依赖，已加入 Windows/Linux CI。研究工程全部保存在忽略的 `build/full-product-study`；尚未发布可生产的新版本。

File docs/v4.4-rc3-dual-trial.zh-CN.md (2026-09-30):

# v4.4 RC3：Support for PLA 双材料测试盘

本版针对单材料支撑难拆、抽取把手先断的问题，提供 **一盘四个试件**：A 单槽 DIMM、C1 长扣槽、C3 短扣槽、H32 安装孔。它是有固定标签和完整配置的试验版，不是完整外壳或替换托盘。当前完整套件仍为 v4.3；双材料拆除效果通过实物确认后，再应用到完整套件。

## 下载及打印

从 [Release](https://github.com/helixzz/rdimm-hdd-case/releases/tag/v4.4-rc3-dual-trial) 下载 `rdimm-v4.4-rc3-dual-trial-P2S-AMS2Pro.zip`。解压后，将唯一的 `rdimm-4.4-rc3-dual-trial-plate-0-dual-P2S-AMS2Pro-PLA-SupportForPLA.3mf` **作为工程打开**，不要只导入几何、拆分后自动落盘，也不要删除其中看似重复的薄片。

| 配置 | 本版设定 |
|---|---|
| 打印机 | Bambu Lab P2S，0.4 mm 喷嘴，AMS 2 Pro |
| 层高 | 0.20 mm，100% 原尺寸，按层打印 |
| 耗材 1 | Bambu PLA Basic：保留结构、支撑主体和把手 |
| 耗材 2 | **Bambu Support For PLA**：可拆接触层；预设 ID GFS02 |
| 参考耗时 | **1 小时 03 分 43 秒**，10 次换料 |
| 参考用料 | PLA 16.95 g + Support For PLA 5.91 g = **22.86 g**，包含冲刷和擦料塔 |

上述数据来自 Bambu Studio 2.8.2.61 的切片估计，不是实测时长。手工建模的界面本体只消耗约 0.049 g 专用材料，总用料主要还包含换料消耗与自动支撑界面。此盘目标是降低拆除难度，不代表双材料打印更快。

发送前，将工程的逻辑耗材 **1 映射到实际 PLA Basic 槽、2 映射到实际 Support for PLA 槽**；不要求一定占用 AMS 的物理 1、2 号槽。不要把两者映射为同一种 PLA，也不要换成 Support for PLA/PETG 或 Support W 预设。若实际使用 PLA Pure，请选择对应实际耗材并重新切片，时间和路径可能变化，本报告对应 PLA Basic。

保留擦料塔、两方向各 800 mm³ 的冲刷量，以及禁止冲刷进模型、填充和支撑的设置。800 mm³ 是这次试验保守采用的起点，未经混料强度实测，并非厂商保证值。此盘尚不以缩减冲刷量省时；发送前重新切片，按“耗材”着色检查：主体均为耗材 1，耗材 2 仅出现在接触界面及相关自动支撑界面、擦料塔。

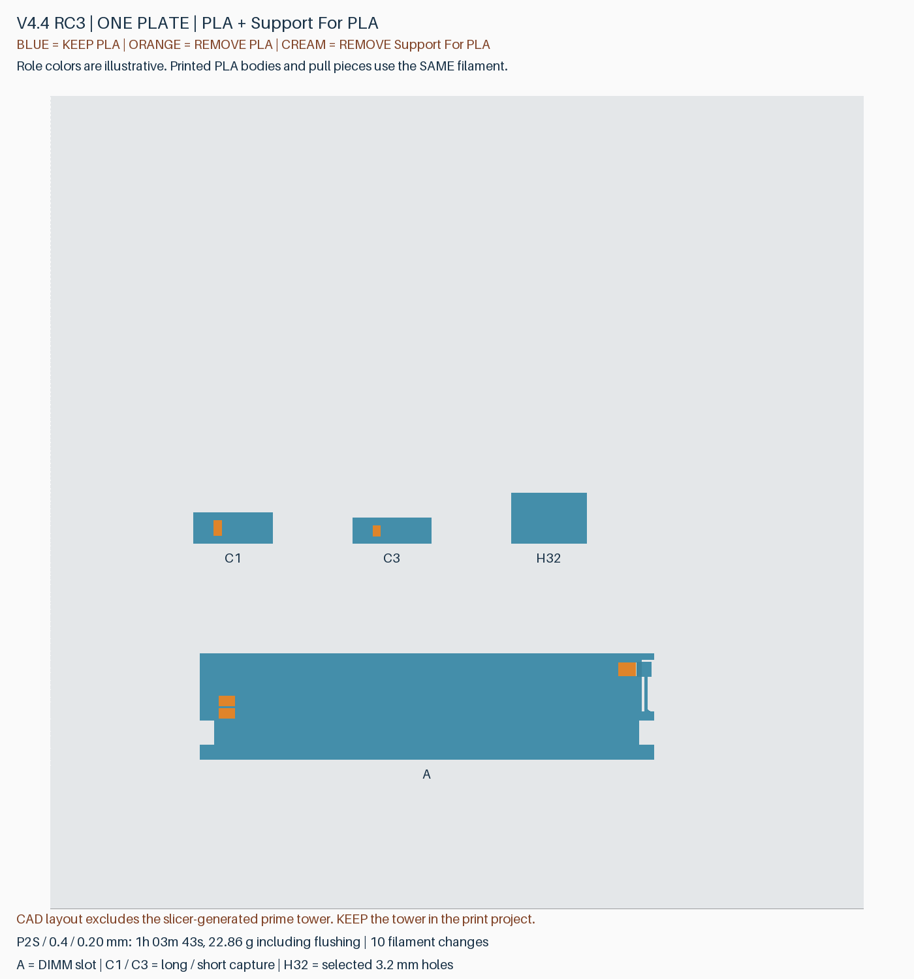
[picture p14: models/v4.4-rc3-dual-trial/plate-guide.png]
一盘布局


## 与单材料测试盘的差异

- 5 个可拆 PLA 支撑主体与保留结构之间，明确建立 **17 个独立的 Support For PLA 接触薄片**，上、下接触面及把手底脚均按实际位置处理。只改切片器的“支撑界面耗材”不会改变旧版手工建模的 PLA 支撑，所以本版同时修改了模型分件和逐件耗材分配。
- A 保留原有 DIMM 接触位置，暂不采用 B 的额外让位，以观察更易剥离的界面是否已足够解决残留阻碍问题。外侧拨片仍有自动支撑，其界面也使用耗材 2。
- C1/C3 的把手宽度由 2.4 mm 分别增至 4.8/3.4 mm，并增大握持端、对可拆件指定 100% 填充。保留扣槽本身的几何；实际把手抗断能力仍需试印。
- 安装孔候选已经收敛为 **3.2 mm**。H32 的侧孔和底孔均为该公称孔径，保留原孔深和入口倒角，并屏蔽孔内支撑。后续完整外壳将以 3.2 mm 为默认值；本次不会回写 v4.3 或旧版下载文件，也不表示已经交付了 3.2 mm 的完整外壳。

Support for PLA 是界面耗材，拆除时仍需取下支撑，不能把它当成水溶材料。使用依据及产品区分见 [Bambu 官方产品页](https://eu.store.bambulab.com/en-ch/products/support-for-pla-petg)；工程使用本地官方 **Support For PLA @BBL P2S** 预设，不混用该页其他型号的预设。

## 打印后如何处理

图中蓝色保留；橙色 PLA 支撑主体和米白色专用接触薄片都要去除。橙色只是示意图的角色颜色，实际打印时支撑主体与保留结构使用同一卷 PLA。

1. 冷却并取下试件。A 固定端两件、弹簧端一件，沿槽向中间抽取；先扶稳刚性边框，不用弹簧承受拆除力。
2. C1/C3 各一件，沿底板朝刻字一侧抽出；清理支撑上下两面的界面薄片。若把手开始开裂，停止继续硬拉，记录是哪一件。
3. A 外侧拨片下的自动支撑也需清除。对照右侧清理后形状，确认槽内和弹簧下方没有薄片残留，再装入 DIMM 检查插拔与回弹。
4. H32 无需挖孔内支撑。普通硬盘螺丝使用 6-32 UNC，勿用 M3 代替；不得拧到盲孔底部。孔径的选择不等于任意托架销钉或螺丝长度都适配。

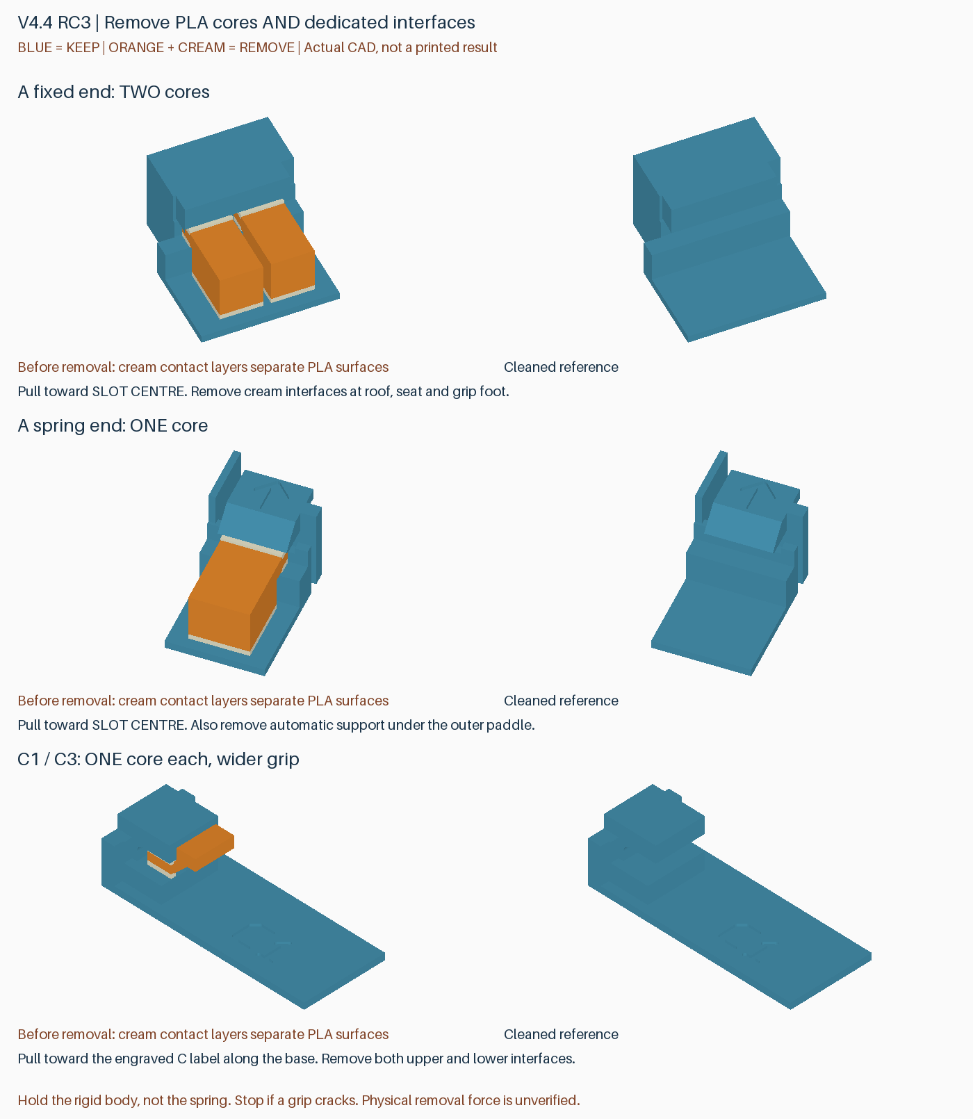
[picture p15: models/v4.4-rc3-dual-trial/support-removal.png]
支撑及清理后对照


反馈重点：A/C 是否能直接抽取、界面是否留在槽内、把手是否完好、DIMM 放置是否更顺畅且保持正常固定。无需重复打印 RC2 的全部孔径候选。

## 已检查与未验证的范围

每个独立分件均封闭、方向一致且单连通；保留件、PLA 支撑和专用界面没有体积重叠，5 个支撑主体共 165 个名义抽取位姿通过检查。配置重存后，几何顶点舍入低于 0.000011 mm，26 个分件的材料分配及 442 个支撑屏蔽面保留。

实际切片无警告；逐处检查 17 个建模界面的专用材料路径、上下 PLA 接触、自动支撑界面材料、AMS 换料指令，以及 H32 两孔内无支撑。接触层采用紧贴设计；实际线条的圆边、接缝和入口斜面使局部并非整面零间隙，检查报告保留这些覆盖率和间隙范围。以上是名义刀路检查，**不模拟混料、粘接、收缩或拆除力，也不等于通过实物测试**。

复现入口为 `build_dual_trial_v4_4_rc3.py`、`prepare_dual_trial_v4_4_rc3.py`、`audit_dual_trial_v4_4_rc3.py`；下载包内含几何检查、切片与路径报告、清单及校验值，不含直接发往打印机的 G-code。

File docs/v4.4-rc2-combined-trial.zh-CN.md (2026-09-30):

# v4.4 RC2：一盘综合改进试件

将 DIMM 槽内支撑、顶盖限位下的支撑、安装孔和托盘角部清理合在 **一盘、12 个带编号试件**中。它们是局部验证件，不能替代完整托盘或外壳；完整套件仍为 v4.3。

## 打印

下载 [v4.4-rc2-combined-trial](https://github.com/helixzz/rdimm-hdd-case/releases/tag/v4.4-rc2-combined-trial) 中的 `rdimm-v4.4-rc2-combined-trial-P2S.zip`。解压后将唯一的 `rdimm-4.4-rc2-combined-trial-plate-0-combined-P2S-PLA-Basic.3mf` **打开为工程**。

P2S、0.4 mm 喷嘴、PLA Basic、0.20 mm 层高参考：**56 分 31 秒，22.57 g**，不含拆支撑时间。使用实际耗材重新切片，保留 100% 尺寸、摆放方向和支撑配置。PLA Pure 应选择对应耗材后重新切片，时间与粘接表现可能不同。

**不要关闭全部支撑，也不要删除模型中的可拆块。** 本盘有 10 块建模支撑，在切片中显示为“模型”；A/B 外侧拨片下还需要自动支撑。工程对内嵌支撑区域和安装孔做了局部屏蔽，裸 STL / 几何 3MF 不包含这些设置，不作为打印入口。

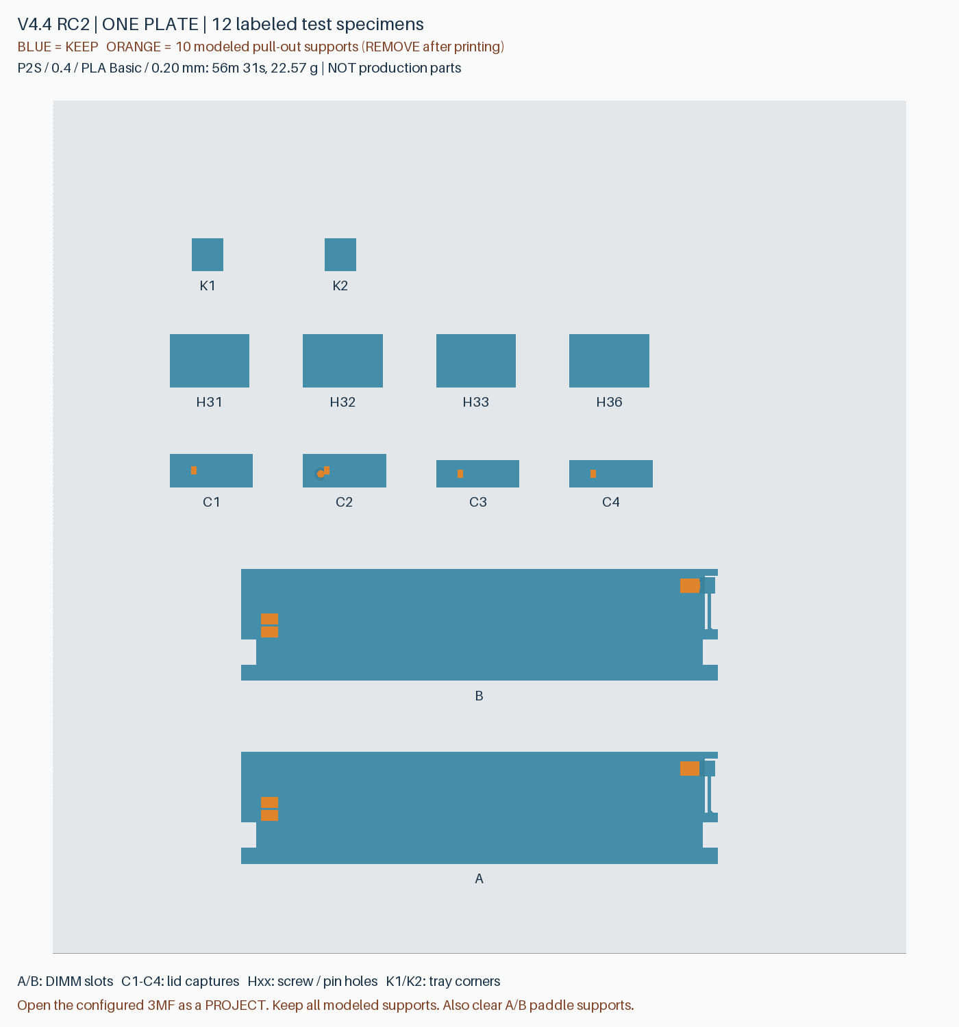
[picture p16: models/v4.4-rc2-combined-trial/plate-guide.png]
整盘编号


## 每个编号测试什么

| 标记 | 改进与对照 | 需要观察 |
|---|---|---|
| A | 保留原槽接触面，固定端两块、卡簧端一块可夹取支撑 | 是否容易抽出、会不会断在里面 |
| B | 与 A 相同的支撑；槽中部承托面和顶面局部避让约 0.3 mm，保留两侧各 1.2 mm 定位面 | 少量清理残留是否更不挡 DIMM；卡簧回位、保持力是否正常 |
| C1–C4 | 从外壳四个限位位置提取的槽口，支撑改为窄接触条与凸起夹持头 | 是否能朝内抽出，避免用螺丝刀伸入槽内反复撬 |
| H31 / H32 / H33 | 3.1 / 3.2 / 3.3 mm 标称孔径，每件各有一个底孔、一个侧孔，入口小倒角 | 标准硬盘螺丝能否形成有效固定，同时检查实际托架销兼容性 |
| H36 | 原 3.6 mm 孔径对照，底孔和侧孔各一个 | 用同一颗螺丝、同一个定位销比较 |
| K1 / K2 | 托盘两个相关角部局部件；去掉废弃薄片及下面的细底条，保留主要边框 | 是否还有细条残留或容易碰断的碎片 |

A/B 与上一盘 RC1 的几何相同，方便沿用对照。B 的齿头中部有局部减薄，实际保持力与寿命尚待验证。K1/K2 对应此前确认的两处薄片位置，并非把托盘所有导向和边框都删掉；本轮处理是清除废弃残片，不是加厚残片。

C1/C2 对应较长的槽口，C3/C4 对应较短的槽口。为节省打印，柱子下段截短，并加上编号底座；槽口形状、打印朝向和层高相位保留。它们用于拆支撑测试，不能验证整盒刚性或盖板装配手感。

## 拆支撑

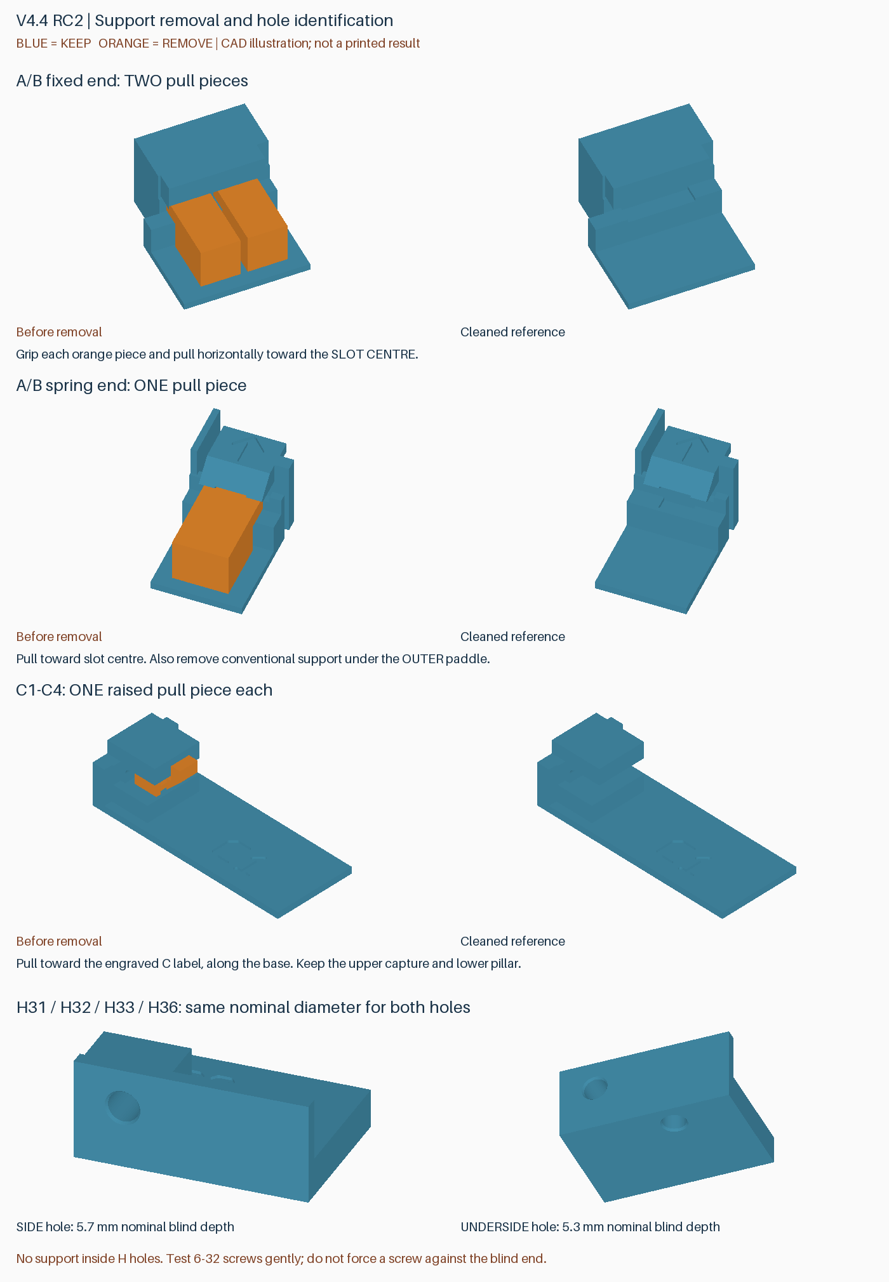
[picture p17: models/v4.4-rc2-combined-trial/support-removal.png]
保留结构、抽取支撑及安装孔位置


图中蓝色保留、橙色拆除，颜色仅用于说明，单色打印不会自动变色。

1. **A/B：**每件固定端两块、卡簧端一块，夹住外露部分，沿槽长度方向朝槽中央水平拉出。固定端两块分别处理，不把薄唇或卡簧当撬点。另拆除外侧拨片下的自动支撑，再装 DIMM。
2. **C1–C4：**夹住槽外凸起的支撑头，朝刻有 C 编号的底座方向水平抽出。上方限位唇和下方构造柱都要保留；不要掰上方限位唇。
3. **H 系列：**孔内没有设计支撑，不需要挑出“填充柱”。观察孔顶有无下垂和堵孔；如果螺丝提前顶住，应区分孔顶下垂、孔径过小和螺丝过长。
4. **K1/K2：**主要看薄片和底条所在位置是否干净。保留余下的主要边框，不需要撬掉任何蓝色部分。

如果夹持头断裂或上方薄唇跟着变形，停止加力并记录编号；本盘就是验证这些失败模式，切片通过不代表一定能整块轻松抽出。

## 安装孔比较

使用 **6-32 UNC 的常规 3.5 寸硬盘螺丝，不是 M3**。H31/H32/H33/H36 表示设计孔径，实际打印孔径会受工艺影响。每件底孔标称盲深 5.3 mm、侧孔 5.7 mm；试印孔顶的下垂可能缩短可用深度。

建议先用 H36 对照，再由 H33、H32 到 H31 逐步比较。使用同一颗短螺丝、相近的旋入深度，避免顶住盲孔底部；记录哪一档可以适度用力旋入、退出，且无开裂或滑牙。塑料中的固定可能涉及螺纹成形和磨损，不能只按材料弹性推断。若有免工具托架，再比较其定位销能否正常进出。

试件方便比较孔径，周围刚度及受力方式不等同于完整外壳，不能据此直接给出拧紧扭矩或抗拔载荷。请反馈侧孔和底孔各自最合适的编号，二者可以选不同孔径。

## 已做检查

- 12 个保留件及 10 块建模支撑均为闭合、单连通网格，整盘留有边界和零件间距。
- A/B 支撑 198 个抽出位置检查通过；C 支撑在完整外壳及局部试件上各检查 204 个抽出位置，无刚体相交。
- 托盘去掉薄片及底条后，完整装配的 512 个 DIMM 位姿、242 个带内存托盘入盒位姿、1520 个底层释放位姿及 132 个盖板位姿检查通过。
- Bambu Studio 最终工程切片无警告；829 个局部支撑屏蔽面保存后保留，网格和全局打印设置未被屏蔽操作改变。
- 最终刀路抽样检查的支撑上下间隙至少 0.2 mm；C 槽没有重复自动支撑，夹持头与支撑主体的名义挤出连接存在；八个安装孔无支撑刀路，托盘角部指定区域无底条残留刀路（该检查排除首层）。

这是几何和名义挤出路径检查，实际桥接下垂、界面粘接、拆除力、卡簧保持力、螺丝手感仍需本次试印确认。无更改已发布的 v4.3 或 RC1 文件；试验结果确定后，再整合完整新版。

请反馈：**A/B 哪个更容易清理和装内存；C1–C4 能否直接夹住抽出；H 系列侧孔/底孔各选哪档；K1/K2 是否还有细条。**

[几何与布局记录](../models/v4.4-rc2-combined-trial/verification.json) · [切片记录](reports/v4.4-rc2-combined-trial-slicing.json) · [刀路检查](reports/v4.4-rc2-combined-trial-toolpath.json)

重建脚本：`build_combined_trial_v4_4_rc2.py`、`prepare_combined_trial_v4_4_rc2.py`、`audit_combined_trial_v4_4_rc2.py`、`preview_combined_trial_v4_4_rc2.py`、`package_combined_trial_v4_4_rc2.py`。

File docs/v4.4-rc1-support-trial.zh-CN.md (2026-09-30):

# v4.4 RC1：一盘支撑拆除与残留容忍度对比试件

**仅用于试验，不是整盒发行版，也不是可装进外壳的正式托盘。当前完整版本仍是 v4.3。** 用户反馈 v4.3 整体效果不错，但 DIMM 两端内嵌支撑难拆、残留影响入槽。本盘两个完整长度单槽 A/B，可直接用同一条实际内存比较，不需要再打印整个盒子。

## 打印入口

下载 [试件预发布](https://github.com/helixzz/rdimm-hdd-case/releases/tag/v4.4-rc1-support-trial) 的 `rdimm-v4.4-rc1-support-trial-P2S.zip`。解压后打开唯一的 `rdimm-4.4-rc1-support-trial-plate-0-support-ab-P2S-PLA-Basic.3mf`，选择 **打开为工程**。

P2S、0.4 mm 喷嘴、PLA Basic、0.20 mm 层高参考：**一盘约 31 分 55 秒、13.12 g**，不含拆支撑。按实际耗材重新切片，保持 100% 尺寸、原摆放、层高和支撑配置。PLA Pure 的实际时间及拆除表现可能不同。

**不要关闭全部支撑，也不要删除模型里的可拆支撑块。** 这次可拆块本身是建模出来的牺牲结构，在 Bambu Studio 中会显示为“模型”刀路；拨片外侧仍有常规自动支撑。工程已对手工支撑及槽顶局部屏蔽自动支撑，避免狭缝被重复填满。裸 STL/几何 3MF 不含这些配置，不作为本次打印入口。

## 两件的区别

| 标记 | 支撑 | 槽内结构 | 要比较的事项 |
|---|---|---|---|
| A | 固定端两块、卡簧端一块，均有外露夹持部 | 保留 v4.3 第一槽的接触几何 | 新支撑形状是否更容易夹住、抽出 |
| B | 与 A 相同 | 两端槽口中部的顶面与承托面分别局部避让约 0.3 mm，保留两侧各 1.2 mm 的定位面 | 少量残留是否更不容易挡住内存；锁定是否仍正常 |

两件都保留 3 mm 卡簧根部。没有统一扩大整条 PCB 槽：保留区域的承托面仍为 Z3，固定唇/齿头底面仍为 Z4.6。B 的中部齿头有局部减薄，这是试验变化，尚未确认保持力与耐用性。该方案暂未推广到整盒八个槽位。

## 拆除方式

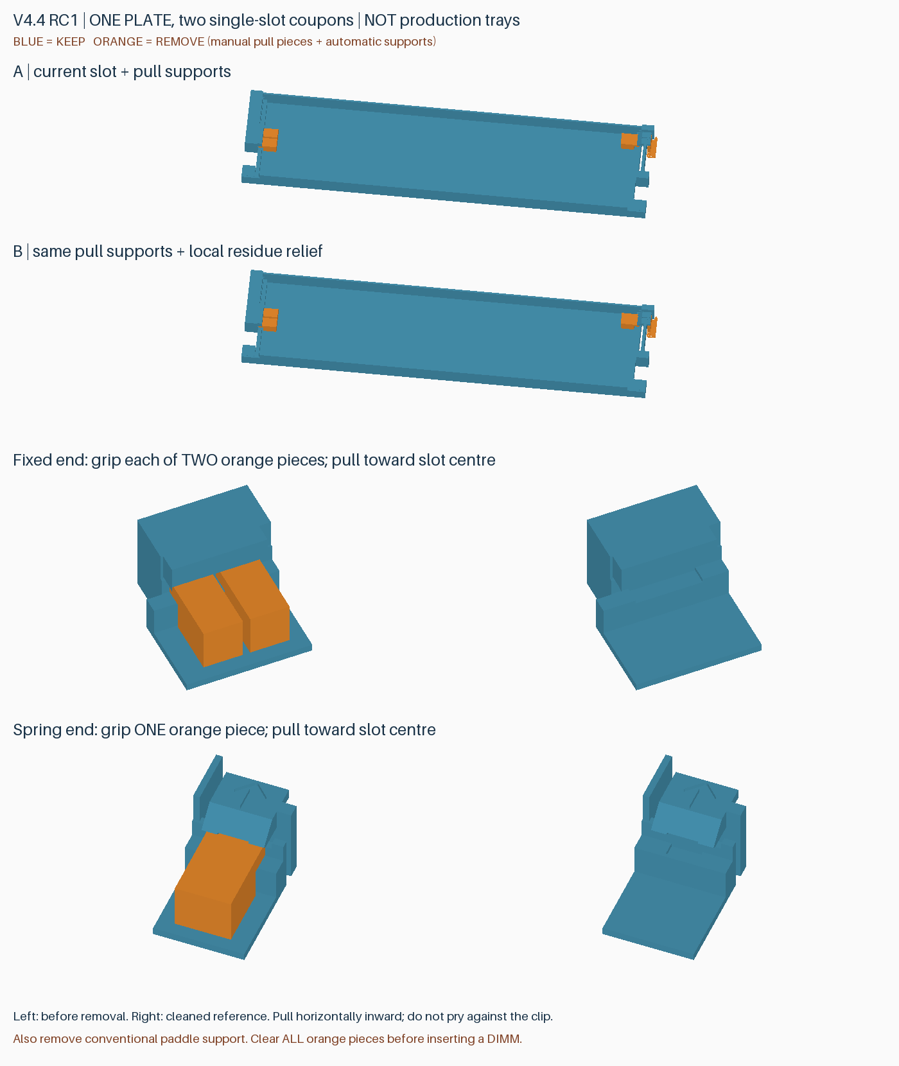
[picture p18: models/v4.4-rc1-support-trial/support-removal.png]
蓝色保留、橙色拆除


1. 冷却取下试件，先辨认固定端的两块夹持部，以及卡簧端朝槽内伸出的一块夹持部。每件共有 **三块手工支撑**，此外还有拨片外侧的自动支撑。
2. 用平口钳或镊子夹住外露部分，沿槽长度方向**朝槽中央水平拉出**，固定端两块分别处理。必要时轻微晃动夹持块松开，不用薄齿头、弹臂或固定唇作撬点。
3. 清除拨片外侧的自动支撑。保留长弹臂、齿头、底部承托面、3 mm 实心基座；不要因为它们与支撑同色而剪掉。
4. 确认三块手工支撑均移除后，再装 DIMM。图中橙色仅用于说明，单色打印时不会自动变色。

若夹持部断裂、支撑仍牢固粘住，或薄唇随之变形，停止加力并记录位置。这正是试件需要验证的失败模式，不表示支撑已经保证能整块拔出。

## 试完反馈什么

请分别记录 A/B：

- 固定端两块、卡簧端一块：能否顺利夹住和抽出，是否断成残块，是否必须向槽内撬。
- 拆到通常能接受的清洁程度后，DIMM 能否顺畅放入和取出。不要故意留下大块支撑后强压内存。
- B 是否比 A 更容易入槽；放入后卡簧是否回位、是否增加晃动。先在桌面轻轻尝试抬起取出，不用真实内存做跌落测试。
- 固定唇底面是否明显下垂、夹持部是否牵伤保留结构。

优先用同一条无散热片 DDR5 RDIMM、同一耗材和工艺比较。并非兼容其他板形的通用内存槽。

## 已完成的检查与限制

- 两个试件及六块手工支撑均为闭合网格；每块支撑朝槽中央平移 0–8 mm 的 33 个位置均无几何干涉，共 198 个位置。
- 两种参考长度、两种 PCB 厚度的 DIMM 静态、抬起/抽出路径检查通过；上方限位仍存在。这不是强度或实际手感测试。
- 最终工程切片无警告，58 个局部支撑屏蔽面保存后保持。刀路抽样检查：支撑与保留结构最小间隙 0.2 mm；B 的中部凹槽间隙更大，拨片自动支撑仍保留。
- 在固定端非定位区域模拟一个 0.2 mm 高残留凸点，A 与参考内存相交，B 不相交。只代表该处该种残留，不表示所有残留都可以忽略。
- **未验证：悬空面实际成形、界面粘接、夹持部强度、支撑抽出力、锁定力与寿命。** 支撑与模型同材质，不能从切片间隙推断一定容易拆。

[几何与试件布局](../models/v4.4-rc1-support-trial/verification.json) · [切片记录](reports/v4.4-rc1-support-trial-slicing.json) · [刀路与残留模拟](reports/v4.4-rc1-support-trial-toolpath.json)

源码 `build_support_trial_v4_4.py`、`prepare_support_trial_v4_4.py`、`audit_support_trial_v4_4.py`、`preview_support_trial_v4_4.py` 可重建本试验。v4.3 的源码快照、已发布附件及模型均不覆盖。A/B 清理后的参考 STL 仅用于查看，不能单独替代本次配置工程打印。

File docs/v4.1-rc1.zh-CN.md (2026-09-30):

# v4.1-rc1：顶盖扣合与卡扣根部加固候选

**已由完整 [v4.2](v4.2.zh-CN.md) 取代。旧活动托盘第一弹臂基座薄弱，需更换；RC4 盖板可复用；外壳及托盘需更新才能获得全部修复。请使用 v4.2 统一发行包管理打印文件。**

针对顶盖边缘易弯、容易脱出，按压卡扣偏软，以及盖板本身偏柔的反馈，重新设计四处盖板扣合，并加固弹臂与长侧壁。保持 **147 × 101.6 × 26 mm、8 条 DDR5 RDIMM、四个零件、两盘**；操作仍是 **按压 → 滑动 8 mm → 抬盖**，内部仍逐层取放、无需螺丝刀。

**这是未打印的结构候选，不是已通过振动或跌落测试的成品。必须使用整套 v4.1 外壳、盖板和两片托盘，不与 v4.0 或 v3.x 混装。** 原有圆孔、单侧 SATA 避让、无侧面凹刻和长内壁 R2 底部圆角保留。

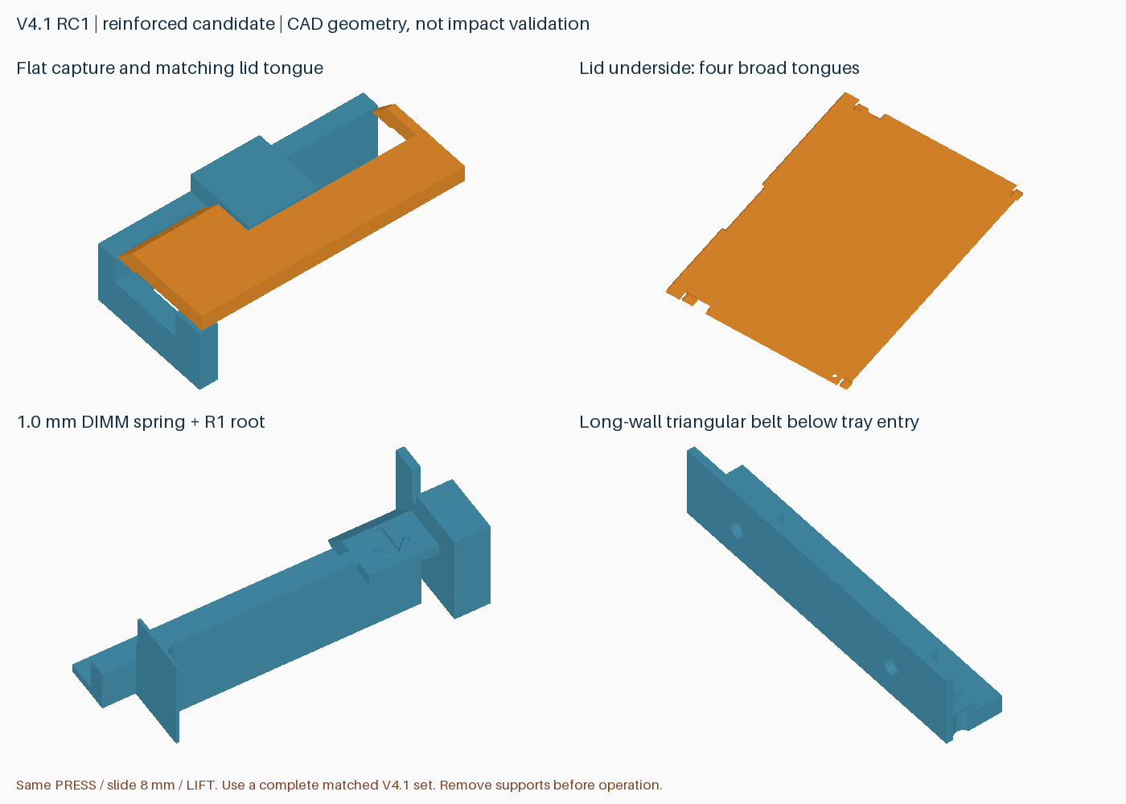
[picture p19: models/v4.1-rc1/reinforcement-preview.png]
加固结构预览


## 具体改动

| 部位 | 设计变化 | 目的及限制 |
|---|---|---|
| 顶盖固定 | 四个斜边扣合改为平面扣脚；外壳上压边厚 2 mm，盖板下扣脚厚 1.4 mm，名义水平重叠宽 3 mm | 将上拔载荷交给水平承托面，减小斜面将侧壁向外撑开的倾向；承托面积不等于承载能力 |
| 扣合根部 | 外壳压边根部 R0.8，盖板连接处局部 R0.4 | 缓和截面变化；盖板连接圆角止于参考元件包络之前 |
| 顶盖按压弹臂 | 厚度 1.0 → 1.2 mm，根部 R1，止退齿宽 5 → 7 mm | 提高截面刚度及止退接触宽度；手感、回弹和疲劳需要验证 |
| 八个 DIMM 卡扣 | 弹臂厚度 0.8 → 1.0 mm，根部 R1，齿及拨片宽度 4 → 4.8 mm | 增加根部和扣齿截面；仍须先拨开再取放，不能依靠强行压入 |
| 两条长内壁 | 在底层两槽外侧空隙增加三角加强筋 | 顶面 Z=10.4 mm，距第一活动托盘最低面 10.8 mm 留 0.4 mm；孔切削体从新增材料中减去 |
| 托盘端部 | 调整避让口及顶盖扣脚经过的局部槽 | 保持垂直取放和盖板原有行程；这也是不能混用旧托盘的原因 |

四处扣脚扣除可选螺丝通道后，名义平面承托面积合计约 **52.67 mm²**，这是几何数据，不是强度或跌落评级。原可选螺丝位置保留；前端螺丝经过新的固定压边、盖板扣脚和下方底孔，起附加锁止作用。正常开合不要求螺丝，首轮功能验证也应在不装螺丝的状态进行。

没有整面向内加厚盖板：参考最不利上层元件到盖板中央的净空只有约 0.3 mm，不能将它当作可随意填充的空腔。当前优先改善已反馈最明显的边缘扣合和按压锁止，**尚未证明盖板中央抗弯性能改善**。托盘部分刚性端栏为新动线去掉了材料，不能以“所有位置都增厚”概括本版。

根部圆角、合理的弹臂截面和额外定位承托是常见的卡扣设计措施；材料、打印方向和间隙也影响结果。参考 [Protolabs 卡扣设计指南](https://www.hubs.com/knowledge-base/how-design-snap-fit-joints-3d-printing/)。其建议不构成本项目的力学验证；本次保持用户正在使用的 PLA 和切片速度，没有同时更换材料或提高速度。

## 打印工程及时间

交付包：`rdimm-v4.1-rc1-P2S-print-projects.zip`。包含第一盘外壳＋盖板、第二盘两片上托盘，以及支撑拆除图和验证记录。工程名的 `p1` 表示继续采用六侧孔的局部支撑屏蔽。**在 Bambu Studio 中打开为工程、保留配置，选择实际耗材后重新切片；不要仅导入为几何。** 仓库中的 STL 和纯几何 3MF 不携带此工艺。

P2S、0.4 mm、PLA Basic、0.20 mm、标准速度、按层打印；全局参数与 RC4-p1 相同：

| 项目 | RC4-p1 | v4.1-rc1 / p1 |
|---|---:|---:|
| 外壳＋盖板 | 2:04:39 / 89.98 g | **2:12:44 / 91.83 g** |
| 两片上托盘 | 1:01:39 / 34.71 g | **0:58:52 / 33.80 g** |
| 整套 | 3:06:17 / 124.69 g | **3:11:36 / 125.63 g** |

整套估计增加 **5 分 19 秒（2.9%）、0.94 g**，不含换盘和清理。时间为切片估计，不应当作秒级精度；PLA Pure 未独立计时。托盘因配合槽减少实体材料而缩短时间，并不表示其所有方向的刚度都提高。

## 支撑清理

六个侧孔继续不生成支撑；其他支撑必须保留。新外壳的四处平面压边下方、新盖板扣脚下方都需要清理。不能把保留的下扣脚、竖直连接段或卡扣弹臂剪掉。图中橙色是实际切片中的支撑刀路，蓝色是模型；右列为清理后的目标形状。

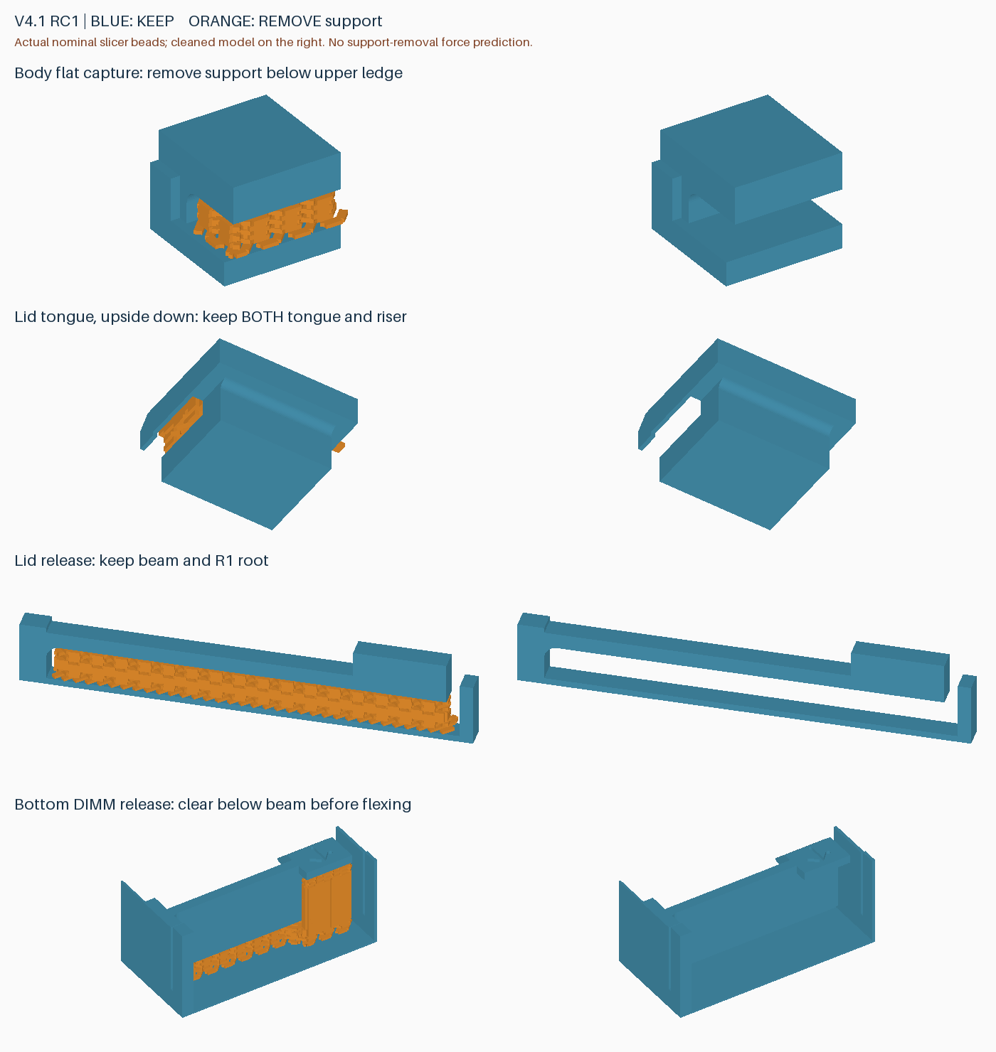
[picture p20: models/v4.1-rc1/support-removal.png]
支撑拆除图


压边下的支撑可以从开放侧接近，但仍可能需要镊子，**尚未确认比旧试件容易拆**。冷却后逐块清理，扶住固定框架，避免拿弹臂作撬杠；清完再检查回弹与盖板行程。六孔无支撑后孔顶是否下垂、定位销配合如何，也仍待实物确认。

## 已完成的验证

- 512 个参考 DIMM 尺寸/位置组合、242 个满载托盘入口位置、1520 个底层 DIMM 取出位置、132 个盖板路径位置检查通过；另检查弹臂示意位移、闭盖直移/倾斜止挡、层间限位和 6 个可选螺丝净空组合。
- 单一连通体、封闭网格、外形包络、安装孔、SATA 避让检查通过；导出后的网格可重建一致。SATA 隔墙到最不利参考元件的 0.2 mm 横向间隙不变。
- Bambu Studio 2.8.2.61 两盘无切片警告；第一盘支撑涂色保存重开后保留 289 个屏蔽面，网格坐标/索引不变。第二盘直接复用已验证工程，字节一致。
- **36 个支撑区域、9 个活动间隙**通过名义有限线宽刀路检查；六个侧孔包围区中的支撑刀路为零。

以上不是有限元、热变形、支撑拆除力或跌落仿真。刚体“有止挡”不能证明薄壁不变形、弹臂不断裂，也不能证明内存不会受冲击损伤。

## 首件验证与验收边界

先完成一套，清理支撑后检查空盖按压、滑动、抬起及回锁，做约 20 次开合，观察裂纹、发白、永久变形和卡滞。随后做真实 DIMM 的静态装卸与硬盘槽位适配，确认末端元件不接触加固结构。

倒置、轻摇及低高度跌落筛查使用**外形、质量接近的非贵重替身**，先从低高度开始并记录高度、落面、方向、载荷和次数。每一步检查盖板是否退出、扣脚/卡扣是否损伤、替身是否脱槽。出现裂纹或失锁即停止升级测试。此类试验只能筛查样件，不能代替规范振动/冲击测试；不要用珍贵的真实 DIMM 来验证首次跌落。

当前尚未定义并验证“轻微跌落”的高度和落地条件，因此不能给出防摔保证。普通 PLA 也没有因此获得缓冲或 ESD 防护能力。

[结构数据](../models/v4.1-rc1/reinforcement.json) · [几何检查](../models/v4.1-rc1/verification.json) · [切片报告](reports/v4.1-rc1-slicing.json) · [刀路检查](reports/v4.1-rc1-toolpath-audit.json) · [六孔检查](reports/v4.1-rc1-side-hole-audit.json)

重建：`python src/build_v4_1.py --output-dir models/v4.1-rc1`。先用 `prepare_v3_2_project.py --version 4.1-rc1` 生成两盘配置，再运行 `prepare_side_hole_project.py --geometry-version 4.1-rc1`；审计使用 `audit_v4.py --version 4.1-rc1-p1 --geometry-version 4.1-rc1 --depth 7.5` 及 `audit_side_hole_supports.py --version 4.1-rc1-p1 --baseline 4.1-rc1`。厂商配置和 G-code 仍只留本地。

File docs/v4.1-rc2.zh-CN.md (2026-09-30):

# v4.1-rc2：缩小底层拨扣窗口，恢复上方连接壁

**已由完整 [v4.2](v4.2.zh-CN.md) 取代。旧活动托盘第一弹臂基座薄弱，需更换；RC4 盖板可复用；外壳及托盘需更新才能获得全部修复。请使用 v4.2 统一发行包管理打印文件。**

两个大开口用于底层 DIMM 卡扣向外拨动及拆除打印支撑。RC1 将它们一直切到外壳顶边，留下了不必要的上部缺口。本版保留下部操作空间，将上方封成拱形窗口，使短端上沿重新连起来。

**仅外壳改变。v4.1-rc1 盖板和两片活动托盘原样兼容，无需重打。不要混用 v4.0 或 v3.x 的盖板、托盘。** 新包仍为四件、两盘，容量 8 条裸 DDR5 RDIMM，外形 147 × 101.6 × 26 mm，单侧 SATA 避让深度 7.5 mm；安装孔、按压/滑动 8 mm/抬盖操作及上一版加固结构均保留。

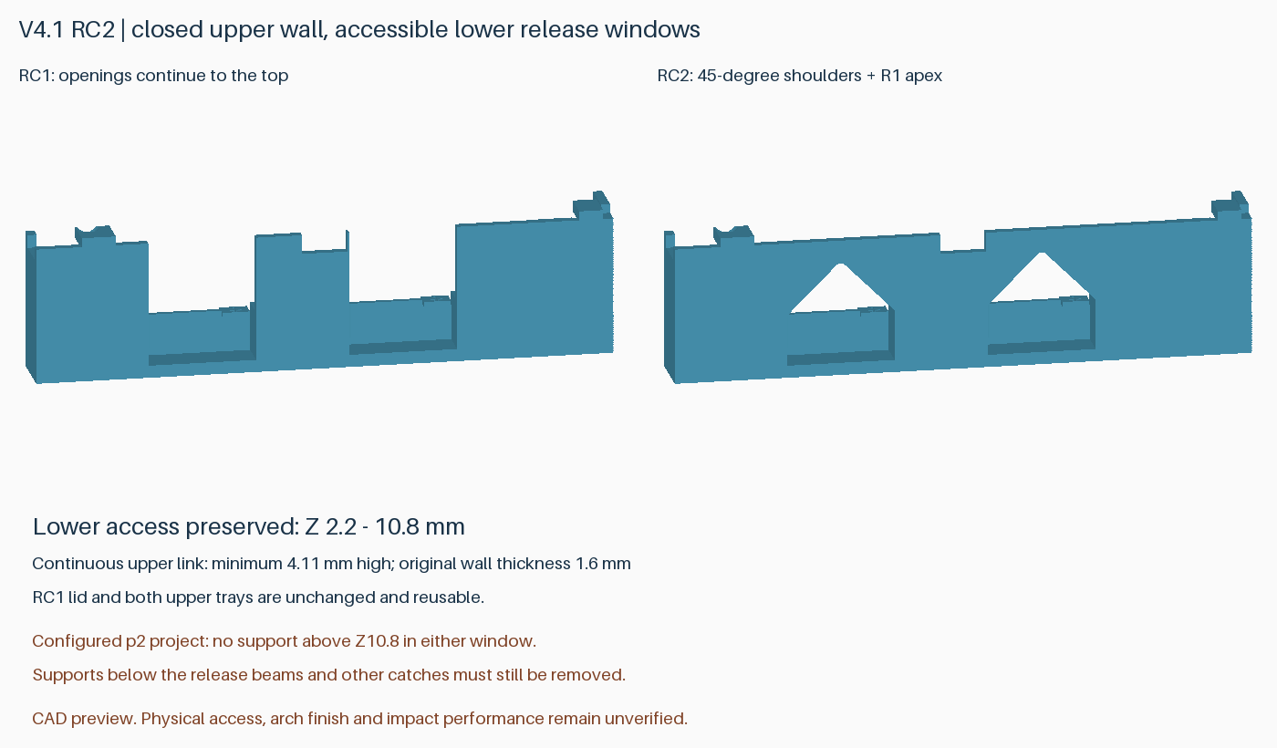
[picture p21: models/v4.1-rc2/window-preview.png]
窗口改动前后


## 结构与装卸空间

- 两个窗口各宽 19 mm，原有 Z=2.2–10.8 mm 的下部空间完整保留，Z=11.2 mm 才开始收拢。
- 两侧为 45°斜面，顶部 R1 圆弧；上方连接壁最薄处高度约 4.11 mm，沿用外壁 1.6 mm 厚度。圆弧顶端最大弦长约 1.415 mm。
- 新增材料只在原短端外壁范围 X=145.4–147 mm 内；底层卡扣示意位移、DIMM 取出、满载托盘垂直装卸及盖板开合路径检查通过。
- 盖板、托盘几何相对 RC1 的增减体积均为零；外壳仅增加约 514.45 mm³ 材料。重新连接上沿的目的在于减少大缺口带来的薄弱处，尚未测得强度提升幅度。

## 立即打印用文件

交付包：`rdimm-v4.1-rc2-P2S-print-projects.zip`。使用包内 **p2 工程**，在 Bambu Studio 中选择打开为工程、保留配置，核对实际耗材后重新切片。

| 打印盘 | 内容 | P2S / 0.4 mm / PLA Basic / 0.20 mm 参考 |
|---|---|---:|
| `plate-1-pin-clearance` | 新外壳＋盖板 | **2 小时 13 分 13 秒 / 92.46 g** |
| `plate-2-upper-trays` | 两片活动托盘 | **58 分 53 秒 / 33.80 g** |
| 合计 | 完整一套 | **3 小时 12 分 6 秒 / 126.26 g** |

相比 RC1-p1 整套增加约 **30 秒、0.63 g**。这是切片估计，不含换盘和清理时间；未提高速度，也未降低原有壁数或层数。已有 RC1 第二盘可直接继续打印；已有 RC1 盖板也可复用。

`p2` 增加两个拱顶的局部支撑屏蔽，并继续屏蔽六个侧孔。自动支撑原本会在小拱顶下生成两簇支撑，本工程对 45°斜面和短圆弧顶面局部涂色后，已确认两个窗口 Z>10.8 mm 的范围内没有支撑刀路。**全局支撑仍开启，卡扣和扣脚下方等必要支撑必须保留并清理。** STL 和仓库的纯几何 3MF 不包含这些设置，不能替代交付的打印工程。

窗口宽 19 mm 不等于一次桥接 19 mm：45°两侧在 0.20 mm 层高下每层各向内推进约 0.20 mm。最终工程在 Z=20.4 mm 首次封口；按 Z=20.2 mm 已打印刀路的名义线宽计算，两窗口各四条封口路径跨越的空隙约 **1.158 mm**（0.002 mm 采样）。这是保留无支撑拱顶的依据，不是不会下垂的保证；首件仍需观察封口处是否有松散挤出或明显下垂。

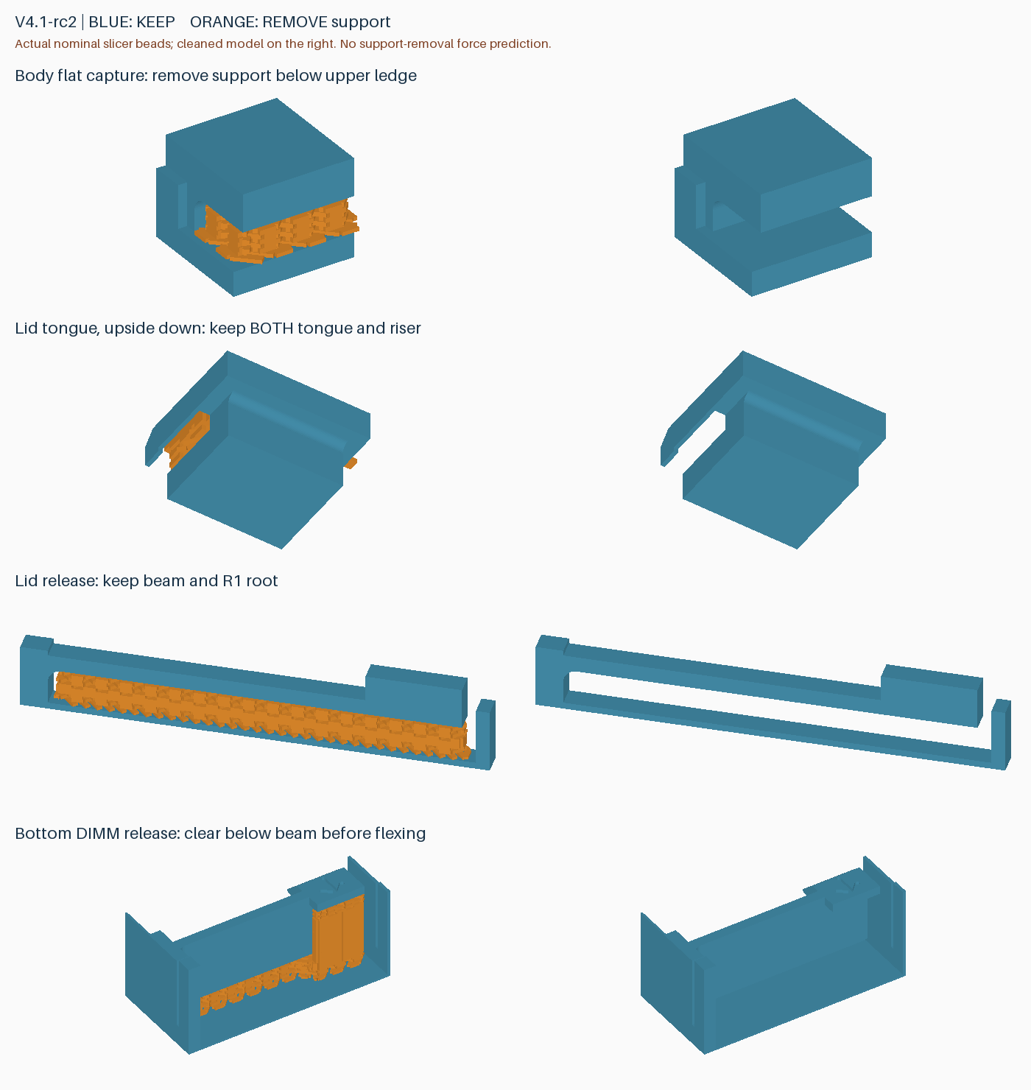
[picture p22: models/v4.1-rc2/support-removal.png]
保留与拆除部位


图中蓝色保留，橙色拆除；右侧为清理后的形状。拱顶与上方连接壁都是永久结构，不要剪除。底层卡扣下方的原支撑仍需拆掉，清理时扶住固定框架，不要用弹臂作撬杠。

## 验证结果及边界

- 几何检查：512 个参考 DIMM 组合、242 个满载托盘入口位置、1520 个底层取出位置、132 个盖板路径位置，以及孔位、SATA、网格和止挡检查通过。
- Bambu Studio 2.8.2.61 两盘无警告；支撑涂色重开保留 361 个面，工程重存的顶点坐标和三角索引不变。
- 原有 36 个必要支撑区域、9 个活动间隙检查通过；六个侧孔内和两个窗口上部的支撑刀路均为零。
- RC1 盖板和两片托盘与新外壳的混合版本静态配合检查通过，完整运动路径另按 RC2 整套检查。

这是几何与名义刀路验证，不是实际挤出、热变形或跌落仿真。新拱顶表面质量、手指操作便利性、完整装配、抗震及跌落仍待首件验证。先完成一套并检查开合、底层拨扣、DIMM 装卸及空盒插槽配合，再决定批量数量。

[兼容性数据](../models/v4.1-rc2/compatibility.json) · [几何检查](../models/v4.1-rc2/verification.json) · [切片报告](reports/v4.1-rc2-slicing.json) · [刀路检查](reports/v4.1-rc2-toolpath-audit.json) · [六孔检查](reports/v4.1-rc2-side-hole-audit.json) · [窗口检查](reports/v4.1-rc2-window-audit.json)

重建：`python src/build_v4_1_rc2.py --output-dir models/v4.1-rc2`。配置两盘后运行 `prepare_side_hole_project.py --geometry-version 4.1-rc2 --arch-windows`；最终检查使用 `audit_v4.py --version 4.1-rc2-p2 --geometry-version 4.1-rc2 --depth 7.5`、`audit_side_hole_supports.py --version 4.1-rc2-p2 --baseline 4.1-rc2` 和 `audit_v4_1_windows.py`。窗口对照还需先生成不带 `--arch-windows` 的 p1 对照工程。厂商配置和 G-code 仅保留在本地，用户实拍图不公开。

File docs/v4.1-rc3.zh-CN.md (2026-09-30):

# v4.1-rc3：斜面导入、平面承托的替换盖板

**已由完整 [v4.2](v4.2.zh-CN.md) 取代。旧活动托盘第一弹臂基座薄弱，需更换；RC4 盖板可复用；外壳及托盘需更新才能获得全部修复。请使用 v4.2 统一发行包管理打印文件。**

后续[盖板方案交叉评估](lid-options-review.zh-CN.md)发现：分别检查偏移无干涉，并不代表横移与上浮叠加后无干涉。RC3 连接颈过渡在探索性组合位姿下仍可能碰到压边；这不是实物必卡结论，当前仍应作为空盒实测候选。本次评估未覆盖或替换此版打印文件。

用户实测 RC2：舌片刚进入便很难推进，强压后越往里越紧，装好后无法徒手取下；同时反馈此前斜面滑槽装配明显更容易。正常操作不应依赖强压或工具撬动。本版借鉴斜面导入，保留闭合后的平面扣合和按压止退，并扩大槽内名义间隙。

**只需重打一片盖板，兼容现有 v4.1-rc1 / v4.1-rc2 外壳和托盘。** 外壳、安装孔、SATA 避让及托盘均不变。不与 v4.0/v3 盖板系统混用。

## 改动及取舍

| 部位 | RC2 | RC3 |
|---|---:|---:|
| 外壳压边与盖板连接颈侧向间隙 | 0.2 mm | 0.4 mm |
| 舌片上方名义间隙 | 0.2 mm | 0.4 mm |
| 舌片下方名义间隙 | 0.3 mm | 0.3 mm |
| 舌片主要配合段厚度 | 1.4 mm | 1.2 mm |
| 舌片根部厚度 | 1.4 mm | 1.4 mm，斜面过渡 |
| 入口 | 直角 | 0.6 mm 长双面斜面，入口边厚约 0.6 mm |
| 退出端 | 直角 | 0.3 mm 长小倒角 |

入口斜面负责引导，全行程间隙负责减轻卡紧；闭合后仍由水平扣合面承托，操作保持按压、滑动 8 mm、抬起。未整体缩放模型或使用全局 XY/流量补偿。原有根部圆角、盖板中心厚度和元件包络不变。

**这不是无代价的强度升级。** 连接颈上部局部宽度从 1.4 减至 1.2 mm，平面承托面积从约 52.67 降为 **41.80 mm²**。舌片局部减薄后不能声称保持原强度。名义上浮余量增大约 0.2 mm；新版在上抬 0.55 mm 时验证有刚体止挡，而旧版 0.4 mm 探针不再适用。

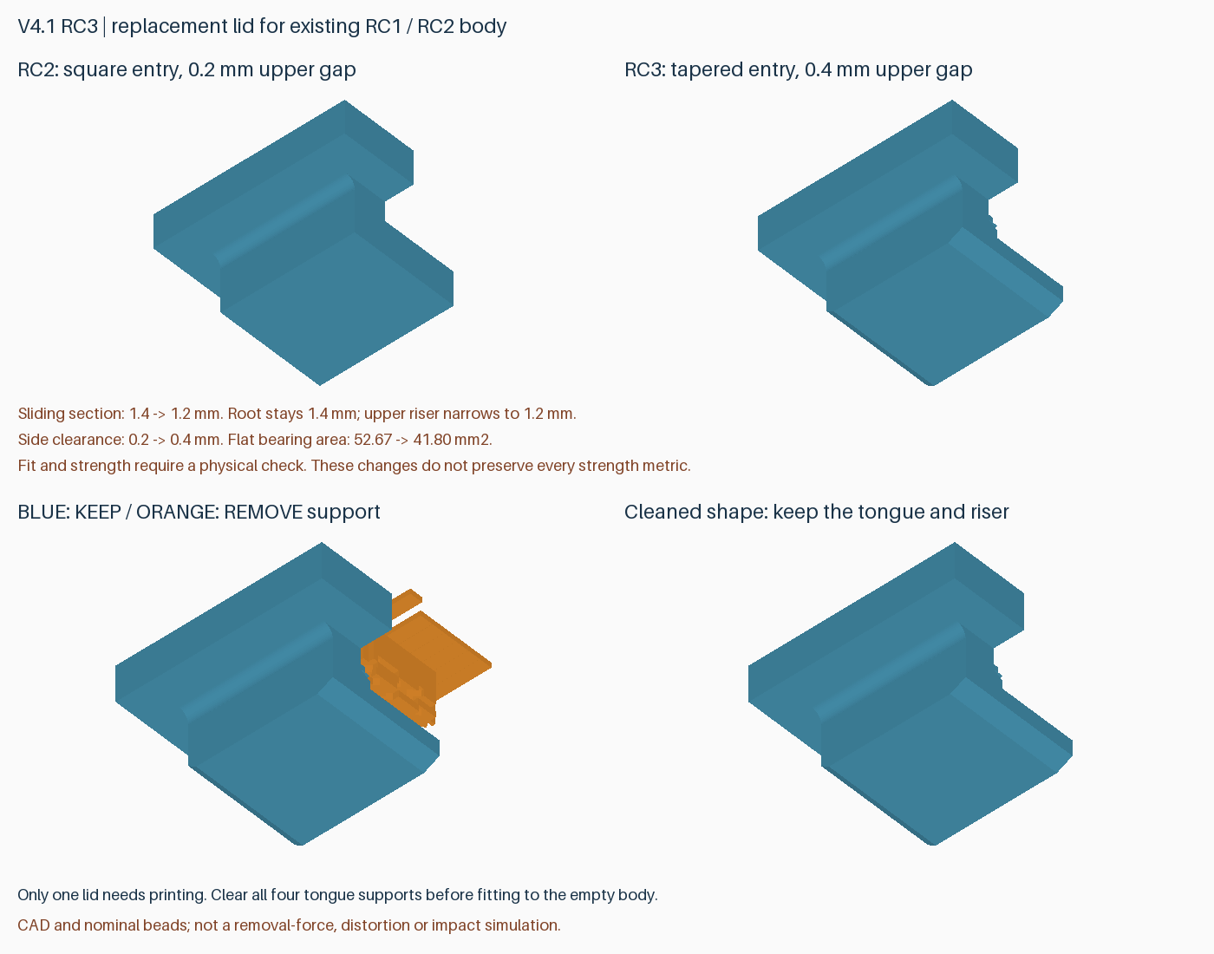
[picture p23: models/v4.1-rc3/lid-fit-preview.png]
配合及支撑对照


## 打印

交付包 `rdimm-v4.1-rc3-replacement-lid-P2S.zip` **只含一盘新盖板**。其中 `plate-3-replacement-lid` 的 3 是布局编号，不是要打三盘。打开 `rdimm-4.1-rc3-plate-3-replacement-lid-P2S-PLA-Basic.3mf` 为工程，保留朝向和支撑配置，按实际耗材重新切片。

P2S / 0.4 mm / PLA Basic / 0.20 mm 标准参考：**36 分 38 秒、24.25 g**，不含清理时间。四个舌片仍需要支撑；图中蓝色保留、橙色拆除，不要把导入斜面剪掉。先在空盒上检查能够徒手反复装卸、回锁后扣住，再装真实 DIMM。阻力明显就退出检查，不要再次强行闭合。

如果仍持续卡紧，需检查已有槽面的残余支撑、翘曲及实测尺寸，继续针对外壳调整，不能无限减薄舌片。新件无法消除旧外壳已发生的永久变形。原设计小间隙、支撑接触面和尺寸误差都可能参与卡紧，目前没有测出各项贡献。

仓库保留完整几何快照供重建；**本次配置切片和交付仅针对替换盖板**，不重新交付整套配置工程。旧 RC2 外壳及托盘文件仍有效。

## 验证

- 完整参考几何检查通过：512 个 DIMM 组合、242 个满载托盘入口位置、1520 个底层取出位置、132 个盖板路径位置；孔位、SATA、止挡、网格及可选盖板螺丝净空通过。
- 相对 RC2，盖板仅移除约 27.61 mm³，外壳和托盘增减体积为零。RC2 外壳配新盖板检查通过。
- 闭合盖板沿长轴偏移 ±0.3 mm，RC2 与外壳出现约 1.66–1.99 mm³ 干涉，RC3 干涉小于 0.001 mm³。这是名义偏移检查，不是变形公差认证。
- Bambu Studio 2.8.2.61 单盘无切片警告；四处舌片支撑名义 Z 间隔均 0.2 mm，检查范围内最小 XY 间隔约 0.159 mm。工程导入网格的边界、体积和连通体一致。
- **实际手感、保持力、疲劳及跌落未验证。** 未进行热变形或受力仿真，刀路通过不能证明实物卡紧已经解决。

[结构和兼容性](../models/v4.1-rc3/lid-fit.json) · [几何检查](../models/v4.1-rc3/verification.json) · [切片报告](reports/v4.1-rc3-slicing.json) · [支撑刀路检查](reports/v4.1-rc3-toolpath-audit.json)

重建：`python src/build_v4_1_rc3.py --output-dir models/v4.1-rc3`。配置切片使用 `prepare_v3_2_project.py --version 4.1-rc3 --plates 3-replacement-lid`，另提供模型/输出目录、Bambu 程序及配置路径。审计使用 `audit_v4.py --version 4.1-rc3 --geometry-version 4.1-rc3 --depth 7.5 --plates 3-replacement-lid`。旧版本和私人照片不覆盖、不公开。

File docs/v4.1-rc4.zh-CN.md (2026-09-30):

# v4.1-rc4：连续颈部间隙的替换盖板

**已由完整 [v4.2](v4.2.zh-CN.md) 取代。旧活动托盘第一弹臂基座薄弱，需更换；RC4 盖板可复用；外壳及托盘需更新才能获得全部修复。请使用 v4.2 统一发行包管理打印文件。**

**只重打一片盖板，继续使用 v4.1-rc1 / v4.1-rc2 外壳和托盘。** 打印约 **36 分 39 秒，24.25 g**。本版落实近期选型建议，修正 RC3 连接颈下方的小台阶，保留斜面导入、平面承托和按压止退。

## 直接打印

交付包：`rdimm-v4.1-rc4-replacement-lid-P2S.zip`。

其中的 `rdimm-4.1-rc4-plate-3-replacement-lid-P2S-PLA-Basic.3mf` 是带打印配置的单盖板工程。**在 Bambu Studio 中选择打开为工程，按实际耗材重新切片**。保留外表面朝下、0.4 mm 喷嘴、0.20 mm 层高和支撑配置；参考耗材为 PLA Basic。文件名中的 `plate-3` 是布局编号，只有一盘，不需要先打印另外两盘。

打印后清除四处舌片支撑，再用现有空壳轻试：按住止退扣、滑动检查阻力，然后检查闭合回锁及徒手释放。若越推越紧就退出，不用强压或工具撬合。通过后再装内存。原有外壳的残余支撑、翘曲或永久变形仍会影响配合。

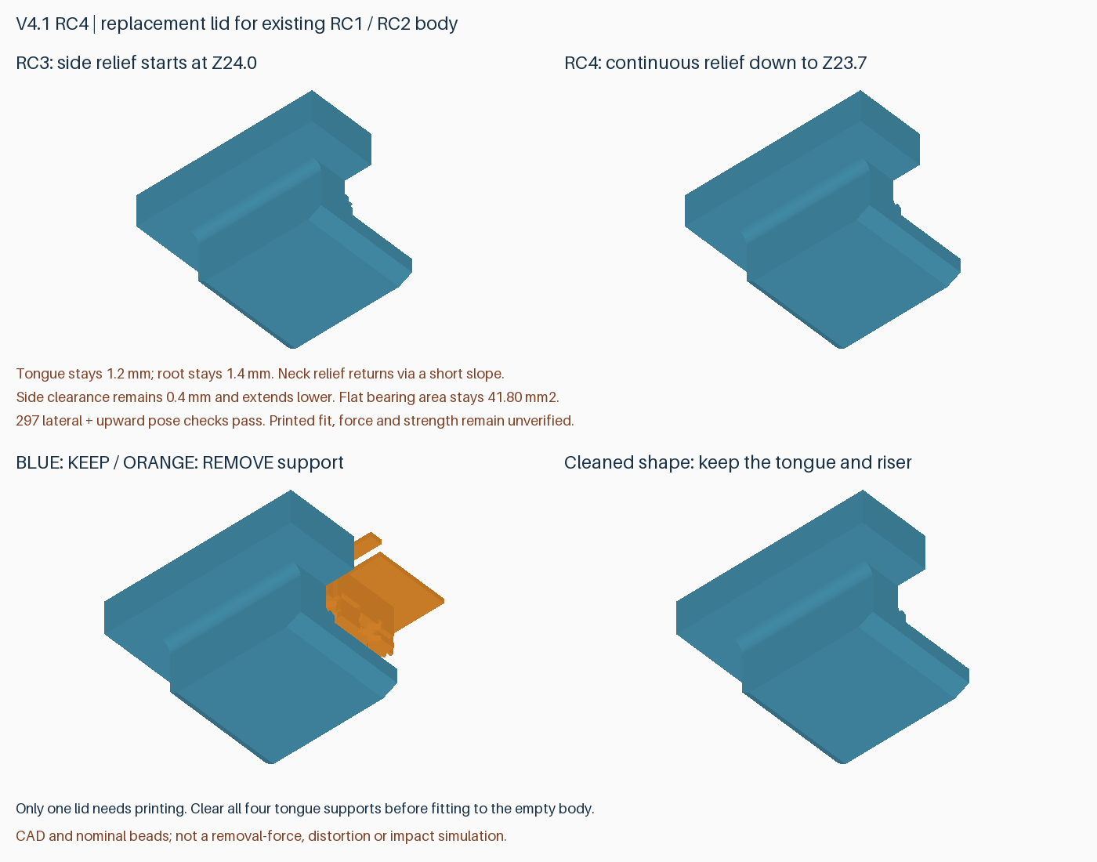
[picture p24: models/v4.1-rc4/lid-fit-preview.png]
保留部分与支撑


蓝色保留，橙色是应拆支撑；不要剪掉舌片、连接颈或入口斜面。

## 改动范围

- 原 RC3 侧间隙只从 Z24.0 mm 起扩大，以下留有台阶。本版将 0.4 mm 侧间隙连续延伸到 Z23.7 mm，再经 Z23.4–23.7 mm 的短斜面接回根部。
- 舌片主体仍厚 1.2 mm，根部保留 1.4 mm，连接颈最小宽度仍为 1.2 mm；没有再次整体削薄舌片。
- 相对 RC3，仅局部移除约 **1.509 mm³**。压边下的承托区域不变，名义平面承托面积仍为 **41.80 mm²**。局部截面有变化，不能据此承诺强度完全不变。
- 顶盖主体厚度、入口 0.6 mm 斜面、退出倒角、上下间隙、按压后滑动 8 mm 再抬起的操作不变。
- 外壳、安装孔、SATA 避让及托盘几何均未变化。不要与 v4.0/v3 盖板系统混用。

仓库保留完整几何快照供重建；此次只配置切片和交付一片替换盖板，原 RC2 外壳和托盘打印工程继续使用。

## 已完成的检查与边界

- 完整几何检查通过：512 个 DIMM 组合、242 个满载托盘入口位置、1520 个底层取出位置、132 个盖板路径位置，以及网格、孔位、SATA、止挡和可选盖板螺丝净空。
- RC2 原外壳配新盖板名义装配通过；横移 X=−0.3/0/+0.3 mm，上浮 Z=0/0.15/0.25 mm，滑程 Y=−8…0 mm（每 0.25 mm）共 **297 个组合位置**，与刚性外壳交叠均小于 0.001 mm³。该检查隔离弹性止退扣；正常解锁由完整装卸路径检查覆盖。
- 已复现的 RC3 横移 +0.3、上浮 +0.15 mm 干涉为 0.124561 mm³，新盖板对应干涉消除。偏移量是探索值，未测量实际打印误差。
- 另一个横移 −0.3、下压 −0.15、滑到 −8 mm 的探针触及侧壁上沿，RC3/RC4 都约 0.331 mm³；它位于本次连接颈修订之外。因此不宣称任意歪斜姿态均无干涉，也不建议向下压着盖板硬推。
- Bambu Studio 2.8.2.61 结果文件报告成功、无切片警告；工程导入网格边界、体积及连通体检查通过。四处舌片支撑的名义 Z 间隔为 0.2 mm，检查范围内最小 XY 间隔约 0.159 mm。时间比 RC3 增加约 0.8 秒，耗材近似不变。
- 本次 CLI 在写完结果和完整 G-code 后未于 90 秒内退出。已独立核验成功结果、文件完整性、G-code 结束标记和支撑刀路；交付的是需重新切片的工程，不含预切片 G-code。详见报告中的退出超时记录。
- **实际装卸手感、保持力、疲劳及跌落仍待实物验证。** 几何和刀路检查不模拟表面粗糙、热翘曲、粘接或操作力。

[结构及组合位置检查](../models/v4.1-rc4/lid-fit.json) · [完整几何检查](../models/v4.1-rc4/verification.json) · [切片报告](reports/v4.1-rc4-slicing.json) · [支撑刀路](reports/v4.1-rc4-toolpath-audit.json)

## 重建

`python src/build_v4_1_rc4.py --output-dir models/v4.1-rc4`

配置工程：`prepare_v3_2_project.py --version 4.1-rc4 --plates 3-replacement-lid`，另提供模型/输出目录、Bambu 程序及配置路径。审计：`audit_v4.py --version 4.1-rc4 --geometry-version 4.1-rc4 --depth 7.5 --plates 3-replacement-lid`。预览：`preview_lid_fit_rc4.py`。源代码及报告提交后运行 `package_lid_fit.py --version 4.1-rc4`，包中记录提交号和 SHA-256。

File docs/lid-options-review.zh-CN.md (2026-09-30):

# 盖板方案交叉评估

后续实施：[v4.1-rc4 替换盖板](v4.1-rc4.zh-CN.md)已落实下述近期方向。以下保留选型时的研究记录与边界。

基于 v4.1-rc3 源码和此前实物反馈，由三路独立评估分别审查旧壳改装、新架构、打印与操作风险，再交换结论交叉核验。**本轮是选型研究，没有发布新打印版本，也没有更改 RC3 文件。** 所谓优先级是当前证据下的研发建议，不是实测强度排名。

## 最优建议

**近期：保留现有外壳和短滑盖操作，下一片候选盖板优先修正连接颈间隙在高度方向不连续的问题。** 保留斜面入口、平面承托和独立止退，不再整体减薄舌片。它只涉及一片盖板，最适合现有打印件和生产时间限制；仍需实际徒手开合验证。

**下一代：优先建模比较“两处刚性挂钩＋一枚防脱手动滑闩”。** 盖板挂入后落下，推闩锁定；盖板本体不再四点同步滑入。若机构无法装进周边空间、需要过多改变托盘或增加拆装复杂度，则退回“落盖＋短程宽松扣合＋独立止退”的四件方案。尚未建模/切片的方案不提供打印耗时或承载能力数字。

## 对比

| 方案 | 旧 RC1/RC2 外壳 | 操作与优势 | 主要代价或风险 | 优先级 |
|---|---|---|---|---|
| 已交付 RC3 | 可复用 | 一片盖板，约 36 分 38 秒；入口斜面、间隙扩大 | 仍有四处配合和支撑接触面；组合姿态敏感点见下文；手感未实测 | 当前实测候选，不当作已修复成品 |
| 连续颈部净空＋短斜面导入 | 预计可复用，需完整验证 | 原操作、全套仍四件；针对小台阶，避免继续减薄承托 | 仍不能消除整体翘曲/支撑残余；需检查过渡处截面 | **近期首选开发方向** |
| 后缘两挂钩＋前端防脱滑闩 | 不能原样复用 | 挂入、落盖、推闩；主要受力由刚性搭接承担，弹片只辅助止退定位 | 全套约五件；需要新壳和盖，托盘是否可复用未知；空间及摆动路径尚未通过 | **新架构首选研究方向** |
| 落盖＋短程宽松扣合＋独立止退 | 需要新配合结构 | 接近现在操作、全套可保持四件；不靠越推越紧获得保持力 | 必须减少四处同时精密定位；不能仅把 8 mm 行程缩短便宣称问题解决 | 新架构的保守备选 |
| 两挂钩＋盖板平面内单个弹扣 | 需要新壳和盖 | 挂入、落盖扣上；全套可保持四件，无独立闩 | 主扣反复弯曲、意外触碰解锁、疲劳/层向强度需验证 | 少零件优先时考虑 |
| 全长紧配滑槽、渐紧燕尾/楔槽 | 不能直接匹配旧平槽 | 导向直观 | 长配合面和楔紧可能重演沿程阻力增大；斜面承载还可能产生撑开侧壁的分力 | 不优先 |
| 四角同时弹扣、分裂薄指 | 部分可做改装 | 看似增加扣点 | 同时释放难，薄指/多扣引入疲劳和打印清理问题 | 不推荐当前采用 |
| 磁吸、外置铰链、PLA 一体活铰链、多个旋钮、散装端挡 | 通常需要新壳/配件 | 各有特定适用场景 | 分别增加外购件、外凸/空间、寿命、操作次数或丢件风险 | 当前约束下靠后 |

这里的“旧斜槽手感更好”是用户实测，应当保留其导入价值；不等于应恢复整段斜面紧配。导向、抗掀盖承托和防自行滑开，应尽量各自承担明确作用。

## RC3 的交叉审查发现

原审计分别施加 X±0.3 mm 偏移，通过了检查。本轮同时加入轻微上浮，发现一个此前未覆盖的组合姿态。两位评审独立复现后，主任务也用可重复脚本复核。

基准是 RC2 的刚性外壳，排除弹性止退扣等活动部分以单独观察压边配合；**这些偏移是探索值，不是对用户打印误差的测量。**

| RC3 闭合姿态 | 与刚性外壳交叠体积 |
|---|---:|
| 名义位置 | 小于 0.001 mm³ |
| 仅 X+0.3 mm | 小于 0.001 mm³ |
| 仅 Z+0.15 mm | 0 |
| 同时 X+0.3、Z+0.15 mm | **0.124561 mm³** |

组合偏移下，RC3 在滑程 Y=−8、−6、−4、−2、0 mm 的交叠体积约为 0、0、0.021780、0.070561、0.124561 mm³。碰撞落在镜像侧连接颈 X140.6–140.7、Z24.0–24.15：侧间隙只从 Z24 起扩大，下方仍留有台阶。略微上抬后，台阶进入外壳压边高度。

**这说明单轴检查不充分，不证明 RC3 实物必然卡紧。** 交叠体积也不是操作力或故障概率。下一候选可研究将 0.4 mm 侧间隙向下连续延伸、再于承托区域外接回根部；约 Z23.7 只是探索起点，不能直接当作交付尺寸。

当前舌片已从 1.4 减为 1.2 mm，平面承托面积从约 52.67 降为 41.80 mm²，连接颈也局部减至 1.2 mm。下一步应优先修正过渡及配合分工，不能无限减薄或仅凭承托面积推算防摔能力。进一步改单侧定位、另一侧浮动也有价值，但必须核算截面和满载路径。

若 RC3 已开始打印，可以完成后在空盒轻试；不要仅因探索性诊断丢弃打印件。若尚未安排下一片，优先把连续净空修订完成、重新验证后再印，避免未经收敛就反复重打。本轮未生成这种修订盖板。

[完整数值](reports/lid-pose-sensitivity.json)；重现：`python src/evaluate_lid_pose_sensitivity.py`。脚本只输出诊断 JSON，不导出或覆盖打印模型。

## 防脱滑闩的结构构想与硬门槛

构想：后缘两处宽刚性舌片挂入、盖板小角度落下、前端滑闩推入挡肩。滑闩独立平放打印，装入后通过端止挡留在盖板或壳体上，日常开启不取下。约 3–4 mm 闩行程只作为建模起点。

滑闩要分别实现三件事：闩头与挡肩正向搭接承受掀盖载荷；定位机构防止自行滑开；全开/全闭均不脱离盒子。小定位弹片也必须验证止退能力，不能因为它不承担主要掀盖载荷就忽略振动。避免靠摩擦楔紧或持续弹性预压保持闭合。

**当前未过的门槛：**

- 前侧壁 Y0–1.6 mm、托盘从约 Y1.9 mm 开始，两者间约 0.3 mm 不能直接容纳完整锁壳。盖板中央与最不利参考元件也只有约 0.3 mm，不能叠加锁杆或旋钮。
- 应优先研究周边现有压边柱、托盘避让区域。若必须新增托盘开口，按整套新结构评价，不预告“只换壳盖”。
- 闭合仍满足 147×101.6×26 mm、安装孔与单侧 SATA 避让，操纵部位不得外凸挂住硬盘槽。
- 完整检查插钩、转落、抬起、滑闩行程及托盘垂直取放。只检查最终闭合位置不够。
- 宽挂钩和分散承托需要限制盖板扭转；单个小角落锁点不自动等于可靠固定。手指可达、锁定状态清晰，不要求同时按多个隐蔽点。
- 工作配合面尽量来自床面、侧壁或可控顶面，而非难清理的支撑接触面；尚不能称为无支撑设计。

空间和路径门槛通过后，再比较耗材、切片时长和装配时间。单独多一个小闩不一定显著增加打印时间，但不能在没有切片时给出保证。

## 最少成本的验证顺序

先使用一片完整候选盖板和现有空壳：清理支撑，按下止退扣隔离其作用，轻试整个滑程；再检查正常回锁与释放。记录是否徒手可操作、阻力是否随推进增加、卡点、清理分钟数及约 20 次循环后有无发白/裂纹/永久变形或明显松动。20 次只是初筛，不是寿命认证。

局部小试件适合筛选截面与清理方式，但不能验证 147 mm 盖板四处同时配合。之后用非贵重占位载荷检查倒置、轻摇和保持，最后做真实 DIMM 静态装卸。跌落初筛应使用替代载荷并记录高度、落面和方向，不拿珍贵内存验证首轮冲击。

若比较两种机构，使用同一材料、机器及层高，记录操作与清理时间、是否越推越紧、四角抬起/扭转是否脱开、零件数及丢件风险，再看耗材和切片时间。没有实测前不打虚构“强度 9/10”分数。

## 外部依据与使用范围

[Prusa 官方 FFF 建模指南](https://help.prusa3d.com/article/modeling-with-3d-printing-in-mind_164135)说明配合间隙需结合材料、打印方向等条件调整，支撑接触面较不规则，入口倒角有利于插接。本评估采用这些原则，没有把其打印机精度或建议数值当作 P2S 的保证。

[Protolabs Network 卡扣设计指南](https://www.hubs.com/knowledge-base/how-design-snap-fit-joints-3d-printing/)讨论根部圆角、载荷分担、打印方向以及尽量避免卡扣闭合后持续挠曲。这里据此区分承载与止退，并将反复弯曲的 PLA 主锁扣列为需验证项；没有套用注塑/SLS 的寿命或承载结论。

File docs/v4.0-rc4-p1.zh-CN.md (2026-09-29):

# v4.0-rc4-p1：六个侧孔局部屏蔽支撑

用户反馈两条长边共六个安装孔中的支撑难以取出。本次是 **RC4 几何的打印工艺补丁**，不改孔形、孔径、孔位或外壳结构，也不提高速度。孔内上半圆柱面设置为禁止生成支撑，其余自动支撑配置保留。适用于直径 3.6 mm 的 `pin-clearance` 光孔外壳，不适用于攻牙底孔替代件。

## 使用

使用交付包 `rdimm-v4.0-rc4-p1-P2S-print-projects.zip` 内第一盘 `rdimm-4.0-rc4-p1-plate-1-pin-clearance-P2S-PLA-Basic.3mf`，在 Bambu Studio 中**打开为工程**并保留配置。使用 P2S / 0.4 mm 喷嘴 / PLA Basic / 0.20 mm 标准层高、按层打印。重新切片后，可在预览中按线型检查：六个侧孔内部不应出现支撑或支撑界面。

不要把工程仅作为几何导入，也不要用 STL 代替此工程：STL 不含局部支撑涂色。不要关闭全部支撑，外壳卡扣等区域仍需要支撑。第一盘包含外壳和盖板；第二盘的上托盘没有设计或工艺变化，已有托盘及正在打印的托盘可以复用。

## 检查结果

- 原 RC4 切片的六个孔都存在支撑刀路；局部屏蔽后，六孔包围区域中的支撑刀路均为零。
- 288 个网格面设置为禁止支撑，每孔 48 个。用 Bambu Studio 2.8.2.61 保存、重新打开并切片后，涂色完整保留，切片无警告。
- 第一盘导回顶点和三角面索引完全相同；第二盘重存带来最大 0.000004 mm 的坐标序列化舍入，三角面索引相同。全局参数只变更配置名称。
- 原有 28 个关键支撑区域及 9 个活动间隙再次通过名义有限线宽刀路检查。
- 第一盘预计 **2 小时 4 分 39 秒、89.98 g**，比 RC4 减少约 **54 秒、0.12 g**；第二盘约 **1 小时 1 分 39 秒、34.71 g**。整套约 **3 小时 6 分 17 秒**，不含换盘、清理与装配。

本次改动消除的是孔中需要清理的支撑，**尚未实测无支撑圆孔顶部是否下垂、定位销是否顺畅插入**。不能据此承诺零风险、孔径精度或免工具托架全面兼容。下一只外壳先检查六孔，再决定是否沿用；已打印件不会因工艺文件改变而自动解决清孔问题，无需仅为此废弃重打。

保留圆孔是为了避免在赶工中同时改变孔形和打印工艺。若孔顶实际下垂导致定位销受阻，再单独评估带斜面孔顶的自支撑孔形，并重新核对安装接口。

## 复现与记录

先按 [RC4 说明](v4.0-rc4.zh-CN.md)生成配置工程，再运行：

```text
python src/prepare_side_hole_project.py --bambu <Bambu Studio 可执行文件>
python src/audit_side_hole_supports.py
python src/audit_v4.py --version 4.0-rc4-p1 --depth 7.5 --geometry-version 4.0-rc4
```

`src/block_side_hole_supports.py` 仅识别本项目原始排版的光孔上半圆柱面并写入 Bambu 支撑涂色；几何版本仍为 RC4。保存后的工程 SHA256 见 [切片报告](reports/v4.0-rc4-p1-slicing.json)。另见 [六孔刀路比较](reports/v4.0-rc4-p1-side-hole-audit.json)、[原支撑区域检查](reports/v4.0-rc4-p1-toolpath-audit.json)。完整配置工程及 G-code 留在本地交付包，仓库中的原 RC4 几何文件不含此工艺补丁。

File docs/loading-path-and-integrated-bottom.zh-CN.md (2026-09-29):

# 装入路径复查与底层一体化评估

用户将橙色单槽试件放入此前打印的 v3.1 水蓝色外壳，发现上沿挡住托盘；掰动外壳放入后，试件与 SATA 避让隆起相碰，无法放平。下面区分实际观察、现有几何诊断和新结构的可行性。**本文没有交付新的可打印整盒，不要求继续掰壳、削轨或追加小样打印。**

## 两个问题

### 1. 正式托盘也缺少顺畅的垂直装入路径

托盘长度为 **143.2 mm**；外壳两端滑盖上沿伸入后，最上方入口的长度方向净开口约 **140.6 mm**，比托盘短 **2.6 mm**。单槽试件、正式底/中/顶托盘均不能在设计 XY 位置直接垂直放下。RC1 仍沿用了这些上沿，不能靠更换 RC1 外壳锁扣解决。

用每件 121 个高度位置复查，正式托盘在最终位置均无体积相交，却在经过上沿时发生相交。之前只确认装配终态和取放 DIMM 的局部路径，没有验证完整托盘进入外壳的过程，遗漏了这项可用性条件。

这不是对所有旋转/平移组合的数学不可装入证明；即使某种斜插动作可行，也不能视为已满足无需掰壳、直观逐层取放的目标。

仅在虚拟诊断模型中去掉两端上轨后，三种正式托盘的相同垂直路径均无相交。该结果说明入口结构是本次阻挡的原因；**不等于可以直接削掉实物导轨**，导轨原本还承担盖板捕获功能，需要连同盖板一起重设计。

### 2. 单槽试件不等于正式底托盘

橙色 `test-tray-1` 用于独立验证 DIMM 槽口和拨扣，没有正式底托盘的 SATA 凹区；其代码以 `bottom=False` 生成。正式 `tray-bottom-2` 则挖掉 X=0..7、Y=10.8..58.2、局部 Z=0..3.2 的避让空间。

把单槽试件放在底托盘的名义高度 Z=4 时，计算得到约 **134.62 mm³** 的相交落在 SATA 隆起区域；另有局部定位结构相交。正式底托盘在正确终态下相交为零。这解释了用户看到的放不平，但不能用单槽件的结果判定正式底托盘也有同样的终态 SATA 干涉。

试件用途此前说明不足。后续检查件必须明确区分“独立夹持测试”与“可装入旧外壳的配合件”，或者直接覆盖真实的外壳装入路径。

## 底层直接固定 DIMM：有可行性，值得作为 v4 方向

建议研究 **外壳内一体固定 2 条 + 中层托盘 3 条 + 顶层托盘 3 条 + 免工具盖板**。底层取消独立托盘，但保留 PCB 边缘承托、平面限位、向上防脱和可触及的释放结构；不是把内存松放在盒底。

| 方面 | 初步结论 |
|---|---|
| 容量 | 继续以 2+3+3、共 8 条为目标，不因省一层底板宣称可增容 |
| 零件数 | 理论上从 5 个主要件减为 4 个，省去独立底托盘 |
| 进入外壳 | 参考 DIMM 本身长 133.8 mm，小于当前入口；裸模块在两个底层设计位置的垂直路径初查均无相交 |
| SATA 避让 | 当前 PCB 底面 Z=7.0，隆起顶部也为 Z=7.0；PCB 的空白边缘可以布置在此高度，颗粒必须保持避让，不能直接降低到盒底 |
| 元件位置 | 本次参考模型的芯片包络从 X=8.6 起，SATA 隆起伸到 X=6.8；这只是参考几何，不推广为所有 DIMM 的保证 |
| 打印收益 | 有望去掉重复底板、底托盘凹区的清理与一次装配动作；新增固定座也消耗材料，仍需实际切片比较 |
| 盘数/时间 | 未确定。少一个零件不自动等于少一盘，也不证明整套更快 |

裸模块路径只检查了模块与现有外壳，尚不含新固定座、手指、装卸动作及三层系统。因此这里只能确认布局有空间基础。

## 不能简单把原底托盘并入外壳

现有拨扣设计要求先把托盘拿出再解锁，不能直接用于固定在壳底的槽：

- 现有底托盘两根弹臂按既定 1.5 mm 外拨时，都会与外壳发生约 **1.25 mm³** 的几何相交。
- 若直接将原托盘与盒底合并打印，弹臂底边会沿长度与盒底连接，改变其弯曲方式，不能继续按原单端弹臂评价。
- 底层处于深腔内，必须确保不用工具即可触及释放部位，不能以夹持住内存但取不出来作为成功。

这些问题需要重新布置底层固定座与释放方式，不能靠原托盘的布尔合并解决。

## 与上盖一起重设计

仅省去底托盘仍会留下中、上层托盘过不了上沿的问题。新结构应优先采用**开盖后入口完全让开的免工具盖板**，让两层托盘垂直取放。可以研究整体可取下的盖板；若保留滑动操作，内伸导向结构也必须能够让开装配口。继续保持 147 × 101.6 × 26 mm、原 HDD 安装位置及背板避让约束。

新版本交付前应覆盖：空/满载中上层托盘完整装入和取出、底层 DIMM 在壳内装卸及手指可达性、盖板闭合/打开、每层防脱与合理余量、SATA 背板和安装孔位、支撑识别/拆除、整盘排版及 Bambu 切片时间。仍需实物确认保持力和反复开合。

现有 RC1 整套和额外旧结构检查件先暂停追加打印；RC2 A 仅修复旧锁扣试件的下承托，不能解决本次托盘入口问题。此次保留已通过的单槽实际 DIMM 配合结果，未发布 v4 文件。

## 复现

运行 `python src/check_loading_paths.py`，生成 `build/loading-path-diagnosis/report.json`。仓库保存 [诊断摘要](reports/v3.2-rc1-loading-path-diagnosis.json)。检查使用原 v3.1 外壳和 RC1 托盘，并核对 RC1 外壳仍有上沿阻挡；不改写任何旧 STL、工程或 Release。

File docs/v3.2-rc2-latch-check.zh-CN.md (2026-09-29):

# v3.2-rc2：仅修正 A 锁扣检查件

**这是 A 试件底座的局部修订，不是完整收纳盒的新发行版。** 外壳、盖板和托盘仍保留 v3.2-rc1 几何；旧版本文件不覆盖。只需重打一个底座，继续使用现有的 RC1 小盖板，不必再打 B/C/D。

## 实测问题与原因

用户确认 RC1 A 弹臂回弹正常，但盖板推入后向下掉落。旧小样的两侧只有上压边，侧壁内侧没有下承托；前沿虽有支点，后部仍可以倾斜下落。原来的平移和上掀检查不足以覆盖此失效。

用原始 CAD 复现：绕前沿支点使盖板后部向下倾斜 0.5–5°，旧小样均无阻挡。完整外壳另有端部安装柱作为承托，同样路径在 0.1° 时已出现接触，因此不能把小样失效直接认定为完整盒子也会掉盖。但完整外壳尚未因此获得实物通过结论。

## 修改及验证

下图是底座横截面，金色为新增的永久承托（不是支撑耗材），蓝色为原结构：

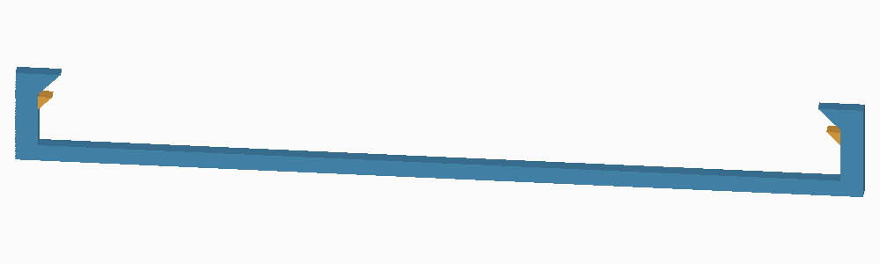
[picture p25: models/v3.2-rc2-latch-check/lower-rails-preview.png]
新增下承托横截面


- 小样两侧增加连续下承托，顶面位于原装配坐标 Z=24.2 mm；原小盖板底面 Z=24.4 mm，保留 0.2 mm 名义余量。
- 承托底面为 45° 斜面，与侧壁连为一体。外形仍为 60 × 22.6 × 6.8 mm。
- 原锁扣、按压行程和小盖板不改。B/C 的弱固定力与 D 的清理困难本轮不修改。
- 旧小样的倾斜失效作为反向检查保留；新小样在同一方向 1° 倾斜时已被承托阻挡。0.5° 内仍可能有设计间隙，不宣称完全无晃动。
- 检查了另外三个倾斜方向、平移限位、26 个锁扣示意释放位置、93 个滑盖滑出位置，以及闭合网格和 Bambu 工程回读。
- Bambu Studio 02.08.02.61 重切最终工程，无警告；新增承托上方的滑动槽未发现支撑挤出侵入。锁扣下仍有必要支撑，名义顶部间隔约 0.20 mm；其拆除难度不保证优于 RC1。

这些是几何和切片检查，修正底座尚未实物打印。弹性、磨损、持续受力、跌落和运输固定力都不由这些检查验证。

## 文件与打印

- 完整本地工程：`rdimm-3.2-rc2-plate-A-base-only-P2S-PLA-Basic.3mf`，位于构建目录 `build/v3.2-rc2-latch-check-project`。
- 仓库几何：[`models/v3.2-rc2-latch-check`](../models/v3.2-rc2-latch-check)，普通 STL/3MF 不包含打印参数。
- P2S / 0.4 mm / PLA Basic / 0.20 mm，沿用 RC1 支撑工艺。以工程方式打开带设置的 3MF；预计 **13 分钟 / 3.54 g**，不含手工清理。PLA Pure 须按实际耗材重新切片。
- 拆除底座锁扣下方支撑后，原小盖板按既有方向滑入。新加的两条下承托属于永久结构，不能拆除。
- 检查盖板是否保持在导轨高度，轻压后部是否仍掉落，锁扣是否阻止滑出，以及按下锁扣后能否正常滑出。不要强压弯曲盖板测试破坏载荷。

可暂存这个修订工程，等后续改动一起验证，不要求立即再开一盘。原 RC1 的单槽 DIMM 配合实测仍保留；它不构成三层或运输验证。

## 重建

```powershell
python src/build_latch_check_rc2.py --output-dir models/v3.2-rc2-latch-check
# 先按 RC1 构建流程生成本地公开官方预设，再执行：
python src/prepare_latch_check_rc2.py --bambu "C:/Program Files/Bambu Studio/bambu-studio.exe"
```

[几何验证报告](../models/v3.2-rc2-latch-check/verification.json) · [工程校验值及切片摘要](reports/v3.2-rc2-latch-check-slicing.json)。完整官方预设和 G-code 保留在本地构建目录，不提交仓库。未创建新 Release 或移动旧标签。

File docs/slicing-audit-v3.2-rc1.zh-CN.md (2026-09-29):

# v3.2-rc1 最终工程切片复核

2026-09-29，使用 Bambu Studio **02.08.02.61 CLI**，对交付目录中的四份完整工程重新切片。先核对 manifest 中的 SHA-256，直接读取工程内的 P2S / 0.4 mm / PLA Basic 配置，没有额外覆盖参数。模型和工艺未修改，不创建新 RC，也不覆盖已交付文件。

结论：下面列明的名义路径检查通过，**可以进入实物验证，但不能据此宣布所有打印隐患消除**。Bambu Studio 提供切片、路径和时间估算，不模拟熔料下垂、支撑粘连/拆除、弹性回弹、疲劳或真实内存配合。

## 切片结果

| 工程 | 预计时间 | 耗材 | 切片返回与警告 |
|---|---:|---:|---|
| `plate-0-checks` | 31 分钟 | 13.7 g | 成功，无警告 |
| `plate-1-body-only` | 90 分钟 | 62.7 g | 成功，无警告 |
| `plate-2-all-trays` | 81 分钟 | 46.7 g | 成功，无警告 |
| `plate-1-pin-clearance` | 117 分钟 | 87.0 g | 成功，无警告 |

均生成完整 G-code 结束标记，时间与原交付估算一致。耗时不是实测，未计入人工清理支撑；PLA Pure 须切换实际耗材后重切，不能直接沿用本表的验证结果。

## 实际路径检查

读取 G-code 的实际 `LINE_WIDTH` 和 `LAYER_HEIGHT`，而非一律假设 0.42 mm 线宽、0.2 mm 支撑层高。圆弧以不超过 0.05 mm 的线段细分；名义挤出投影按带圆端的线宽范围处理。XY 栅格采样为 0.025 mm；侧向最近距离使用线段距离计算。

- **支撑与悬空面：**正式两盘的 27 个区域，以及外壳单独盘和可选试件对应区域，均有与模型投影重叠的支撑。外壳长弹臂、接口凹区、底托盘凹区、8 个活动齿、8 个固定槽和 8 个拨片的局部支撑检查均通过。重叠位置的最小名义竖向间隔约为 **0.20 mm**。这不是连续实心支承；接触层自身有线间空隙，导入斜面和边缘的局部距离也会更大。
- **正式托盘活动缝：**8 个弹臂的名义 0.9 mm 贯通缝，取中央 0.5 mm、排除有意连接的根部和挡齿后，整个打印高度内未发现模型或支撑挤出路径侵入。它检查的是这段明确的活动走廊，不代表整条缝所有边界均逐点验证。
- **外壳自由端：**正式外壳、单独外壳和锁扣试件的自由端间隙中央 0.4 mm，锁齿高度范围内没有挤出路径侵入。弹臂下方的临时支撑仍须拆除。
- **支撑侧向接近：**关键区域附近、Z 范围重叠的支撑/模型名义挤出范围没有相交。局部最小计算侧向间隔约 **0.144 mm**；外壳长弹臂附近约 **0.328 mm**。工艺设置的 XY 距离 0.35 mm 不是所有首层、转角和挤出边界都具有 0.35 mm 实测余量的保证。以上仅是名义路径距离，不能据此证明不会粘连。
- **可选试件的例外：**单槽托盘首层有一小段支撑底脚伸入活动缝靠近挡齿的一端，局部支撑/模型最小名义间隔约 0.159 mm，没有模型路径跨接。该段不是永久结构，须随支撑清除；若清理后仍粘连或损伤弹臂，应记录为失败。正式托盘盘未出现这个中央走廊侵入现象。小样和正式件的自动支撑路径不完全一致。

审计脚本包含平行间隔、交叉接触、不同 Z 层不接触、圆端覆盖的数学控制案例。原始模型装配/运动范围检查仍见 [候选版说明](v3.2-rc1.zh-CN.md)，它们不模拟打印后的变形。

## 打印决定

目前没有从上述路径检查中发现需要立即再次修改几何或工艺的证据。考虑已发生的 v3.1 粘连，仍建议先打印约 31 分钟的一盘检查件，确认支撑能取净、卡扣能回弹、实际 DIMM 能轻柔装卸，再打印正式件。试件通过也不等于正式件或十套批量生产已获验证。

实际三星颗粒/标签与上层托盘是否接触尤其需要检查：参考最不利包络的上方余量仅约 0.1 mm。硬盘背板避让、最终厚度、携带保持力和开合寿命仍未有实物通过证据。保留 [实物验证表](validation-v3.2-rc1.md) 的待测状态。

## 复现和证据

```powershell
python src/recheck_v3_2_projects.py --bambu "C:/Program Files/Bambu Studio/bambu-studio.exe"
python src/audit_v3_2_toolpaths.py
```

完整工程先按既有构建/交付流程生成。上述命令默认从 `build/v3.2-rc1-delivery` 读取 manifest 和工程，在 `build/v3.2-rc1-recheck` 输出新切片及检查结果。

仓库保留 [工程哈希和切片摘要](reports/v3.2-rc1-fresh-slices.json)、[逐区路径审计](reports/v3.2-rc1-finite-width-audit.json)。完整 G-code、官方预设及机器路径仍只保存在本地忽略目录。

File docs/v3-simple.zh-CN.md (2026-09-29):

# v3-S：不用独立限位框的一体托盘原型

**本工作名称已正式命名为 [v3.1](v3.1.zh-CN.md)。** 单件几何相同，当前完整实测与批量打印请使用 v3.1 的版本化文件和 Release；本页保留设计背景。

保留 **8 条容量、147 × 101.6 × 26 mm 外形和逐层取放**，把原 v3 的三个托盘、三个限位框改为 **三个一体托盘**。每槽一端是固定 PCB 边缘槽，另一端是连在托盘上的弹性拨扣；没有需要配对、拆下或保管的限位框，也没有必装内部螺丝。

**这是一版待打印验证的替代方案，尚未验证拨扣力度、寿命或实物防脱。** 已检查几何装配与释放路径；不要把这些检查当作运输测试。

实际托盘与操作位置

## 使用者只需要知道的操作

1. **开盖、拿出托盘。** 按原 v3 盖板上的提示滑开盖板，从固定厚端拿出需要的托盘；下层仍需逐层取出。保持水平，不抓带箭头的活动扣来提托盘。
2. **放内存。** 把一个 PCB 短边送入固定槽，沿箭头向外拨开另一端的小扣，放下内存，再松开拨扣。检查扣已回到 PCB 短边上方。不要靠猛压内存来撑开卡扣。
3. **取内存。** 扶住内存，沿箭头拨开对应扣，稍抬起这一端，再从另一端固定槽抽出。应先拿出托盘再操作，外壳内部不提供充分的拨扣行程。
4. **放回、关盖。** 托盘按 1、2、3 从下往上放回，再滑上盖板。托盘已经带有止挡，**不要额外放入旧限位框**。

装入与取出均只操作目标槽的一枚拨扣；其它槽的拨扣保持闭合。托盘仍应水平拿取，释放时扶住内存，不能在未经实测的情况下靠倒置或甩动来证明卡扣可靠。

## 与原 v3 的关系

| 项目 | 原 v3 | v3-S |
|---|---|---|
| 内部散件 | 3 个托盘 + 3 片框 | 3 个一体托盘 |
| 每槽固定 | 放好内存，再盖上对应框 | 插入固定端、拨扣放下、松扣 |
| 开盖后 | 框可直接脱离，需要水平操作 | 每槽有独立一体止挡，实际防脱仍待验证 |
| 整套排版 | 3 盘 | 2 盘 |
| 首次试件 | 1 盘、7 件 | 1 盘、6 件 |

**原 v3 外壳、滑盖、空壳试配件及滑轨 / 锁扣小样完全保留，文件逐字节复制。** 若这些已经打印，只需先补打 `test-tray-1.stl` 测试新的一体拨扣；通过后补打三张新托盘。不要混用两种内部托盘方案，不要叠加原 v3 的限位框，也不能装入 v2 / v2-R 外壳。

原 v3 的光孔 / 攻牙底孔选择、安装孔深、可选盖板螺丝和固定背板试配要求仍按 [v3 说明](v3.zh-CN.md)。SATA 凹区没有扩大或取得新的实测兼容结论。

## 打印入口

所有新文件位于 **[`models/v3-simple/`](../models/v3-simple/)**，不是原 `models/v3/`。

- **首次打印：[first-test-all.stl](../models/v3-simple/first-test-all.stl)**。空壳、一体单槽托盘、滑轨两件及锁扣两件共 6 件，同一盘一次完成。
- **已打印原 v3 试件：只补打 [test-tray-1.stl](../models/v3-simple/test-tray-1.stl)**。新试件的两端拨扣 / 固定槽截面与正式托盘相同；不同槽的位置为避让外壳柱位而变化。
- **完整第一盘**：`plate-1-body-pin-clearance-lid.stl` 或 `plate-1-body-thread-pilot-lid.stl`，任选一种；与原 v3 第一盘相同。
- **完整第二盘：[plate-2-all-trays.stl](../models/v3-simple/plate-2-all-trays.stl)**：两槽底托盘、三槽中托盘、三槽顶托盘，共三件。

一盘试件与一盘全部托盘

保持 100% 比例、原方向、**按层打印**；不要缩放或选择逐件打印。新试件盘与托盘盘的零件包围盒间距至少 10 mm、床边余量至少 15 mm。外壳第一盘沿用原 v3 的排布。

打印准备仍需操作者处理：

- 托盘底面朝下；0.8 mm 侧向弹臂从热床开始打印，旁边为贯通开槽，不在弹臂下方埋支撑。切片后确认缝隙未粘连，箭头处可向外活动。
- 固定端的短悬挑槽口和活动扣齿仍需检查切片，必要时设置局部可移除支撑，并从内存入口方向清理干净；不能假设这一体结构完全免支撑。不要把支撑塞进弹臂贯通缝。
- 空壳和盖板锁扣底座仍需按原 v3 说明设置悬臂下方局部支撑。
- 先用单槽件确认 PCB 端部无元件、颗粒和标签不受压，空扣可回弹，再试真实内存的轻柔装卸。卡扣不能自然让位、回弹或出现白化 / 裂纹时，停止使用并调整设计，不能通过增大按压内存的力来解决。

## 几何检查与待验证内容

`src/build_simple_trays.py` 读取 v2-R 基准托盘和已生成的 v3 外壳文件。检查包括：

- 四种托盘的 576 组参考内存位置、54 组 PCB 六方向止挡反向检查；满载整盒的所有极端参考位置均不穿入其他零件。
- 弹臂示意向外让位 0–1.5 mm 的 16 个位置；每槽以 2° 小角度抬起释放端、再向外抽出 2 mm，共 3024 个装卸路径位置。反向路径可用于持扣装入；**没有模拟靠内存压迫斜面自动卡入的力学过程**。
- 两种外壳装配、26 mm 外形、十个安装占位圆柱、SATA 凹区、可选盖板螺丝、上层托盘与盖板的叠层捕获、102 个滑盖行程位置。
- 托盘单一闭合实体、STL 导出体积、排版间距和床边余量。四份排版经 Bambu Studio CLI 导入 / 导出回读，实体数量和尺寸保持；**未切片、未打印**。

弹臂长 18 mm、厚 0.8 mm；这些参数和 1.5 mm 示意行程不是实测许可力或寿命。软件只检查示意变形后的空间，不预测应力、断裂、疲劳或长期蠕变。仍使用“每个 PCB 短边有 2 mm 无元件区”的待测假设。侧向 / 转动脱出、跌落、运输和 ESD 均未认证。实测记录放在 [v3-S 验证记录](validation-v3-simple.md)。

重建：`python src/build_simple_trays.py --output-dir models/v3-simple`。可用 `--models` 指定 v2-R 源目录、`--v3-models` 指定 v3 源目录。Bambu 回读脚本使用 `--models models/v3-simple --names first-test-all plate-1-body-pin-clearance-lid plate-1-body-thread-pilot-lid plate-2-all-trays` 选择这版排版。

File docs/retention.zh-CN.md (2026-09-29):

# v2-R：针对携带晃动的固定升级件

用户已打印 v2 两盘文件，反馈整体装配体验良好，但携带时有明显晃动，尚未区分托盘移动和内存移动。本升级分别处理这两处活动空间。

**保留原来的 v2 外壳，换掉全部三层托盘和盖板，再增加六根压条。** 仍为 8 条、147 × 101.6 × 26 mm。普通攻牙外壳和侧面嵌件外壳均做过数字装配检查。不能把本升级件与 v1 外壳或旧 v2 托盘混装。

状态：数字模型与检查完成，**v2-R 本身尚未打印或试装**；不是已经验证的运输容器。原 v2 的晃动反馈不等于本升级已通过实测。

固定升级结构

## 固定方式

### 托盘与外壳

新盖板增加两处沉孔，两颗 **M2×20 沉头螺丝**依次穿过盖板、顶层和中层托盘，拧入底层托盘的塑料螺纹。三层的端部承力面相互接触，盖板内侧新增承力垫面。原来的四颗盖板螺丝继续连接盖板与外壳。

力的传递关系为：外壳 → 原盖板螺丝 → 新盖板 → 两颗贯穿螺丝 → 托盘叠层。内存不承担这条夹紧路径的载荷。贯穿螺丝通孔有装配余量，靠正确紧固和承力面接触限制托盘晃动；塑料螺纹强度仍须实际检查。

### 内存与托盘

每层两端各一根可拆压条，压条用短螺丝拧在托盘塑料承力台阶上。压条下伸的边缘挡住 PCB 短边上方，PCB 下方仍由台阶支撑；增加的端部导向则先接触 PCB 边缘，限制横向活动。

**压条是捕获式止挡，不是强压夹具。** 拧紧时压条应落在塑料台阶上，不能以压紧 PCB 作为拧紧标准。基于 PCB 厚度 1.17–1.37 mm，理论上下余量为 0.33–0.13 mm；保留这点余量是为了避免不同 PCB 厚度和打印误差造成硬压。

参考模型中，PCB 向上接触压条时，颗粒距下一层底面仍有 0.20 mm；PCB 向侧面接触短边导向时，颗粒包络距主槽侧壁仍有 0.10 mm。**这些是理想几何值，打印公差可能消耗这些余量**，必须先试小样。目标三星料号两个短边各 2 mm 无元件区仍需实际确认；现有支撑能放下内存，不自动证明新增上止挡也避开所有元件和标签。

## 文件与五金

所有新 STL 在 `models/v2-retention/`。

| 文件 | 数量 | 说明 |
|---|---:|---|
| `tray-bottom-2.stl` | 1 | 底层；含贯穿螺丝的攻牙底孔 |
| `tray-middle-3.stl` | 1 | 中层；贯穿孔 |
| `tray-top-3.stl` | 1 | 顶层；贯穿孔，中/顶层几何可互换 |
| `keeper-2-print-2.stl` | 2 | 底层左右两根压条 |
| `keeper-3-print-4.stl` | 4 | 中/顶层的左右压条 |
| `lid-retention.stl` | 1 | 新盖板，六个螺孔 |
| `test-tray-1.stl` | 先打印 1 | 单槽固定试件，不装入正式盒子 |
| `test-keeper-1-print-2.stl` | 先打印 2 | 单槽试件专用压条 |

新增五金：

- **12 颗 M2×5 沉头螺丝**：每根正式压条两颗。
- **2 颗 M2×20 沉头螺丝**：连接盖板和整叠托盘。
- 原来的四颗盖板 M2 螺丝继续使用；仍需核对头部完全沉入、螺丝不顶底。
- 单槽试件需要四颗 M2×5，试完后可拆下用于正式装配。

设计沉头口径约 4.3 mm、90°锥面；螺丝头型须实物核对。**沉头螺丝标注长度包括头部**。不要改用突出表面的圆头，也不要擅自增加长度；上方下一层托盘需要平整承力面。

新托盘上的攻牙底孔为 1.6 mm：在塑料台阶顶面 Z=5.6 mm 下方，盲孔底位于 Z=1.0 mm，实际深度约 4.6 mm。装配前用适合盲孔的 M2 丝锥加工，限制深度并清理碎屑。几何孔深不等于有效牙深，先空装试拧。M2×5 压条螺丝理论进入托盘约 3.8 mm；M2×20 贯穿螺丝在底层托盘理论有效进入约 3.6 mm。仅用手工具轻轻紧固，未给出经过验证的扭矩。

## 推荐顺序

1. 先打印 `first-test-plate.stl`：已含一个单槽托盘和两根试件压条，总塑料实体体积约 6 cm³。不要直接批量打印。
2. 先空装、攻牙并检查压条能自然落到台阶、螺钉头不突出，再拆开压条放入一条内存。确认导向只接触 PCB 短边可支撑区域，压条下面没有颗粒、焊点或堆叠标签。若不合适，应调整模型间隙，不能靠加大拧紧力强压。
3. 装上试件压条，轻缓改变放置方向，检查 PCB 被止挡保留、颗粒不接触塑料。无需用猛烈摇晃或跌落来验证。通过后再做整套升级。
4. 正式每层先放内存，再安装左右压条。两槽层用短压条，三槽层用长压条；右端压条相对左端绕竖直轴旋转 180°。对齐额外的小贯穿孔和角部避让缺口，不能反向硬装。
5. 按两槽底层、三槽中层、三槽顶层放入原 v2 外壳。新盖板应自然就位，六处孔位对齐。先将两颗长螺丝和原来的四颗盖板螺丝都轻轻带入，再交替轻紧；盖板有明显翘起时先检查堆叠、压条头部和螺丝长度。
6. 先验证整叠托盘不再有明显移动，再分别检查内存的微小装配余量。长螺丝松动、塑料牙滑丝或压条变形都会影响固定，不应把这些状态视作安装完成。

## 打印与两盘排版

升级两盘

- `upgrade-plate-1-lid-bottom-keepers.stl`：新盖板、两槽底托盘、两根短压条、四根长压条，共八个实体。
- `upgrade-plate-2-middle-top.stl`：两个三槽托盘。
- `first-test-plate.stl`：单槽试件及两根试件压条，先打这一盘。

这些都是每盘一个合并 STL，按 100% 比例导入，**逐层打印**，不要翻转、缩放或拆散重排。均以 256×256 mm 热床排版、零件包围盒间距至少 8 mm，现有外壳不再重复打印。

压条已翻成大平面朝下、下伸边缘朝上。由于止挡高度涉及 0.1 mm，**试件盘和升级第一盘建议统一用 0.10 mm 层高**，避免混合零件逐件设置；第二盘可用 0.20 mm。保留文件中盖板已外表面朝下的方向。薄壁及细导向需检查切片路径，不要用整体缩放补偿配合。尚未提供切好的 G-code 或实测工艺参数。

## 检查范围与仍待验证事项

- 八种单件闭合、法线一致、单实体；装配不干涉，最终外形保持 26 mm；两种原 v2 外壳分别校验。
- 参考板长、板宽、PCB 厚度取上下限，在允许平移范围各端点共检查 **512 组整盒内存位置**；单槽试件另检查 **64 组**。
- 对八个槽的六个方向各故意越界 0.05 mm，共 **48 组反向检查**，确认 PCB 确实会碰到物理止挡，而非仅把空间放大后得到“不干涉”。
- 检查新增螺丝之间及螺丝与参考内存的干涉；打印盘检查边界、间距与导出回读。

以上采用刚性几何和平移端点，不模拟打印弹性、倾斜转动、冲击、振动疲劳、塑料螺纹寿命或真实颗粒布局。仍需实物验证，不能承诺“携带绝不会损坏”。尤其不要为了彻底消除声音，把保留的 PCB 装配间隙改成未经验证的硬压紧。

防静电性能仍取决于材料与使用方式，本升级没有改变原项目的 ESD 验证状态。试装反馈请记录 [验证表](validation-retention.md)。

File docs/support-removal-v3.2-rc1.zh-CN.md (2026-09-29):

# v3.2-rc1 检查件：支撑识别与清理

下图来自实际 CAD 和交付工程的参考 G-code。**蓝色全部保留，橙色是需要清除的支撑**；颜色仅用于说明，单色实物没有这种颜色区别。左边显示支撑位置，右边显示原始模型形状；右图不是已成功拆除支撑的实拍。

支撑与保留结构对照

| 图中位置 | 需要拆除 | 必须保留 |
|---|---|---|
| A 外壳锁扣，朝外的一面 | 长弹臂下面、缺口里的波浪状支撑与接触层 | 上方细长弹臂、末端凸起锁齿、两侧固定框架 |
| B 托盘固定槽，朝内存腔的一面 | 突出压边下、窄槽里的支撑 | 上方压边、下方托住 PCB 的台阶；不把台阶削平 |
| C 托盘活动扣，朝外的一面 | 带箭头拨片下面的支撑柱及外伸底脚；内侧挡齿下方另有局部支撑，参照 B 的槽内清理方式 | 细长弹臂、上端挡齿和带箭头拨片；细长条不是支撑 |
| D 窄条凹区试件，翻到背面 | 大凹区里的支撑，包括底脚和接触层 | 原始底面和肋；正面中间薄隔板也是模型，不要折掉 |

窄条试件正面的固定槽下也有局部支撑，按 B 清理。平整小盖板需要保留，它是锁扣试件的配套滑盖。

## 操作

1. 完全冷却后拿在手里或放稳，扶住粗框架；先从 A 外露且边界清楚的支撑处尝试。
2. 用镊子或小尖嘴钳只夹住一小块支撑的外露边缘，轻微来回松动，向开口方向取出。A 向框架外侧，B 向内存腔，D 从底部开口取出。不要把薄弹臂或槽口压边作为撬点，也不要一把扯整排。
3. 主体支撑取下后，对照右图检查残留接触层和缝隙。不要为了表面光滑而继续削模型，也不要把尖锐工具硬塞入尚未确认的缝隙。
4. **夹不住、看不清分界，或支撑带着弹臂一起弯时就停止。** 拍该处正面和侧面近照，记录“清理未完成”，不凭用力程度判定是否能拆。不要用 DIMM 撬开支撑。
5. 只有清理完成后，才轻轻空载拨动卡扣检查回弹。明显变白、裂纹、持续粘连时停止，不装内存。

最新实物反馈：检查件打印顺利，A–D 支撑现已全部拆除。A 容易施力但粘接紧密；B/C 需要技巧和镊子撬；D 最难，尤其小圆点需精密镊子寻找缝隙。后续 A 回弹正常，但盖板因小样缺少下承托而掉落，参见 [RC2 底座修正](v3.2-rc2-latch-check.zh-CN.md)。C 能固定实际 DIMM、装卸无干涉，但固定力偏弱。见 [详细记录](validation-v3.2-rc1.md)；识别和清理简便性、完整套件及运输保持力仍未通过。

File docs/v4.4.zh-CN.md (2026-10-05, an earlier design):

# v4.4：完整双材料打印工程

收纳 **8 条无散热片 DDR5 RDIMM**，外形 **147×101.6×26 mm**。底层两槽与外壳一体，两片活动托盘各放三条，滑动解锁上盖后逐层取放。日常操作不依赖螺丝；打印完成后的支撑清理仍可能需要工具。

本版将 RC6 实测能一次拆净的整块 Support For PLA 支撑整合到完整产品，共 **20 块**：16 块 DIMM 两端支撑、4 块顶盖限位支撑。支撑体与把手为同一专用材料，不再采用细梳齿、异材锁键或独立永久压条。不采用实测下垂、阻挡 DIMM 的 N 免支撑结构。

## 下载与打印

从 [v4.4 Release](https://github.com/helixzz/rdimm-hdd-case/releases/tag/v4.4) 下载 **rdimm-v4.4-complete-P2S-AMS2Pro.zip**。解压后分别以“工程”打开两份已配置 3MF，不要只导入为几何模型。

| 打印盘 | 内容 | 参考时间 | 总耗材 | 换料 |
|---|---|---:|---:|---:|
| 1 | 外壳＋盖板 | 3 小时 22 分 46 秒 | 121.40 g | 22 次 |
| 2 | 中层三槽托盘＋顶层三槽托盘 | 1 小时 28 分 18 秒 | 46.26 g | 10 次 |
| 完整一套 | 四个永久零件、两盘 | **4 小时 51 分 04 秒** | **167.66 g** | **32 次** |

上述数值包含冲刷与正常擦料塔，不含换盘、拆支撑及装配。全套 PLA 约 **148.87 g**，Support For PLA 约 **18.78 g**；实际专用支撑体约 **0.50 g**，其余专用料主要用于换料。各项按未舍入值求和。相比 v4.3 单材料参考 3:10:44，多约 1 小时 40 分钟；本版优先解决难清理、残留影响装配，不宣称制造提速。

工程文件：

- `rdimm-4.4-plate-1-pin-clearance-P2S-AMS2Pro.3mf`
- `rdimm-4.4-plate-2-upper-trays-P2S-AMS2Pro.3mf`

第 1 盘名称中的 `pin-clearance` 为沿用的内部标识，**本版孔径实际已统一为 3.2 mm**，不是旧版 3.6 mm。

配置为 P2S、0.4 mm 喷嘴、0.20 mm 层高、纹理 PEI、按层打印；材料 1 为 Bambu PLA Basic，材料 2 为 **Bambu Support For PLA / GFS02**，不是 Support for PLA/PETG。发送前将两种逻辑材料映射到实际 AMS 2 Pro 槽位。

保留摆放方向、零件材料、禁支撑涂色与擦料塔。普通自动支撑继续用 PLA；20 块专用支撑已建模并指定材料 2，在切片中属于模型路径，不应再额外填入自动支撑。不要全局禁用支撑，也不要把全部自动支撑界面改为专用材料。双向冲刷维持 800 mm³，不冲刷进成品或支撑中。

两盘排版

两盘是已检查的完整排版，没有证明是所有姿态与算法下的全局最少盘数。包内 STL 位于 `geometry-reference-only`，仅用于几何参考，不含材料分配或局部禁支撑，不能替代配置工程。包内不含 G-code。

## 支撑如何拆除

完整工程局部拆除图

图中蓝色为永久结构，米黄色为整块专用支撑；颜色仅作说明。图中未绘出其他普通 PLA 自动支撑，可在 Bambu Studio 切片预览的“线类型”中单独查看 Support / Support interface；显式建模的专用支撑请按“耗材”查看。

1. 冷却后检查支撑是否完整，再开始拆除。先清掉松散碎屑。
2. DIMM 两端支撑均向空槽内侧取出；顶盖限位支撑向盒子中心取出。扶住刚性框架，必要时使用工具夹住支撑外露部分或从可达边缘逐步分离，避免猛撬永久顶棚、活动卡簧及根部。
3. **固定端和四处顶盖限位仍可能需要工具用力**。RC6 实测已能一次拆净，但没有实现这些位置徒手轻松拔除；完整盒子内的工具可达性也需实物复核。不以加大顶面间隙换取容易拆除，以免功能面再次下垂。
4. 另外拆除普通 PLA 支撑，包括外壳锁扣下方、SATA 避让顶棚、底层弹臂下方、盖板舌片下方，以及切片显示的其他必要支撑。**3 mm 卡簧基座、齿头、PCB 承托台和上盖限位顶棚都必须保留。**
5. 底部四孔和侧面六孔均不生成支撑，无需再从孔内撬支撑塞。孔口如有毛刺仅局部清理，勿整体扩孔或缩放零件。
6. 清理后先检查卡簧回弹、盖板空盒拆装，再轻放 DIMM、逐层放入托盘。固定端先就位，拨开活动端完成装入；遇到阻挡不要用颗粒或 PCB 作杠杆硬压。

上盖沿 OPEN 方向滑动约 8 mm 后抬起，装回反向操作。实际硬盘槽兼容性先用空盒验证；不要用装有真实内存的跌落试验代替机械验证。

## 相对 v4.3 的变化与复用

- 底部和侧面安装孔统一为用户选定的 **3.2 mm 公称孔径**，保留孔位与深度；普通 HDD 6-32 螺丝配合依赖实际打印，未预制标准金属内螺纹，勿过度拧紧。不同免工具定位销仍需实配。
- 移除活动托盘角部原有脆弱短片及其底部细条，不是移除用于约束 DIMM 的连续长挡边。
- DIMM 卡簧外侧拨片保留 RC6 同款斜面加固；3 mm 基座、齿头下框架避让、底部圆弧和侧壁加强棱继续保留。
- 新的完整工程采用整块专用支撑及局部禁支撑；未把尚未实测的剥离槽、薄接触筋或无支撑斜面加入正式基线。
- **上盖永久几何与 v4.3 相同，可复用旧上盖**。外壳孔径与托盘局部结构有更新；要获得完整改进，应使用本版外壳及两片托盘。不要通过拆分为普通对象打散一个永久件与其配套专用支撑，误把悬空支撑自动落到底板。

参考兼容对象为三星 M321RAJA0MB2-CCP/CCPKF 一类裸 DDR5 RDIMM；用户已做局部实装。**不支持带散热片的马甲条，不宣称兼容未测试的 DDR4 或其他板形。** 单侧 SATA 避让进深继续为 7.5 mm，无电气连接功能，实际背板与硬盘座需实配。普通 PLA 不提供 ESD 防护认证。

## 已检查与仍待实测

完整几何检查包含 512 个 DIMM 组合、242 个满载托盘入口位置、1520 个底层释放位置、132 个盖板路径位置及 660 个支撑退出姿态。盖板与 v4.3 的双向布尔差体积为零，四个永久零件均保持连通。

两盘 Bambu Studio 切片无警告，材料分配、支撑涂色和导入网格已核对。20 组专用支撑逐层连通及接触区覆盖、全部 10 孔零支撑、8 条 DIMM 弹臂通道、外壳锁扣自由通道、186 个上托盘卡簧根部逐层 PLA 连接、8 处齿头/框架间隙和 8 处其他必要自动支撑区域通过检查。专用料即使在切片中标为模型，也不会被计作永久 PLA 根部材料。

RC6 的实物结论仅是：A 基本合格，A/C 支撑能一次拆净，固定端/C 仍需工具；N 不能用。**v4.4 完整双材料套件尚未完成实物装配、实际耗时、振动或跌落验证。** 几何及名义挤出路径不模拟粘接力、喷嘴拖动、热翘曲或疲劳，仍先验证一套再批量生产。

包内提供切片、刀路、根部、齿头和自动支撑报告及 SHA-256。源代码重建入口为 `build_v4_4.py`、`prepare_v4_4.py`（传 Bambu 与官方 profiles 路径）、`audit_v4_4_details.py`、`preview_v4_4.py`；干净标签提交用 `package_v4_4.py` 打包。旧标签及附件保持不变。

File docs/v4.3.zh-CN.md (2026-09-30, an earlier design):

# v4.3：底部平顺过渡与侧壁加强棱

用于收纳 **8 条无散热片 DDR5 RDIMM** 的 3.5 英寸硬盘外形盒子，外形 **147×101.6×26 mm**。底层两槽与外壳一体，两片活动托盘各放三条；开盖后逐层取放。日常装卸无需螺丝，盖板的可选螺丝仅用于加固。

本版将侧壁加强棱与底部圆弧做成连续结构，同时保留 v4.2 的 3 mm 托盘卡簧基座和齿头下方 0.5 mm 框架避让。**完整两盘交付，正式版本号不代表通过跌落或寿命认证。**

## 下载与打印

从 [v4.3 Release](https://github.com/helixzz/rdimm-hdd-case/releases/tag/v4.3) 下载 **rdimm-v4.3-complete-P2S.zip**。解压后用 Bambu Studio **打开为工程**，按实际耗材重新切片；保留方向、支撑及局部支撑屏蔽，不要全局关闭支撑。参考配置为 P2S、0.4 mm、PLA Basic、0.20 mm。

| 打印盘 | 工程文件 | 内容 | 切片耗时 | 耗材 |
|---|---|---|---|---|
| 1 | `rdimm-4.3-plate-1-pin-clearance-P2S-PLA-Basic.3mf` | 外壳＋盖板 | 2 小时 11 分 14 秒 | 91.54 g |
| 2 | `rdimm-4.3-plate-2-upper-trays-P2S-PLA-Basic.3mf` | 两片活动托盘 | 59 分 30 秒 | 33.94 g |
| 全套 | 四件、两盘 | 8 条容量 | **3 小时 10 分 44 秒** | **125.47 g** |

各项分别四舍五入；不含换盘、清理与装配。相同配置相比 v4.2，整套预计仅增加约 **13 秒**，耗材约同为 125.5 g。切片预测不等于实际交付时间。两盘是当前交付排版，未证明所有排版方式中的全局最少盘数。

完整包包括两盘配置工程、四个零件 STL、截面与支撑示意、几何/刀路报告、提交号及 SHA-256；不含 G-code。STL 不包含支撑配置。同一 Release 的 Source code 对应固定标签源码。

## 加强棱如何与底部连接

实际 CAD 截面

- 保留旧加强棱的主要外伸位置和顶面高度 **Z10.4**，上内缘加 **R0.4** 小圆角。
- 下方使用 **R3.5 内凹圆弧**从底板顶面 Z4 平顺连接至加强棱内侧竖面；圆弧与底面、竖面均相切。它替代 v4.2 的单独 R6 外形，但保留了 v4.2 该处原有材料，并增加连续加固体。
- 第一层活动托盘底面仍是 **Z10.8**，与加强棱留 **0.4 mm** 名义间隙。**加强棱用于侧壁加固，不是托盘承托面**，没有改变堆叠高度。
- 安装孔净空、单侧 SATA 避让、底层 DIMM 空间及装卸路径均保留。没有新增向下悬空的长棱底面；原有卡扣等部位仍需支撑。

材料增加与圆弧连接的目的在于改善侧壁结构；尚未量化实际刚度、振动或跌落表现，也不保证消除外壁底部横纹。

## 旧零件复用与操作

**相对 v4.2 只更新外壳。盖板、两片托盘 STL 均逐字节相同，可继续使用。** 完整包仍提供全套两盘，避免搜集补丁。已有三件时可在第 1 盘通过“拆分为对象”分离外壳与盖板、删除盖板后重新切片；当前整盘作为单个组合网格导入，不要直接缩放模型。v4.1-rc4 盖板也与本版相同，但 v4.1 旧托盘缺少 v4.2 的基座与间隙修复，不建议沿用。v4.0/v3 零件不混装。

开盖：按压解锁，沿 OPEN 方向滑动 8 mm，再抬起；装回反向操作。先逐层取出托盘，再拨开相应 DIMM 卡簧取放内存。不要强压卡紧的盖板或用内存颗粒作施力点。

拆支撑示意：蓝色保留，橙色拆除

卡簧固定端的 **3 mm 实心基座是永久结构，不可剪掉**。清除齿头/拨片下方支撑，包括齿头与固定框架间可能残留的一层界面。清理后八处齿头下方模型刀路名义净空至少 0.6 mm。六个侧孔内及两处拱顶上部不生成支撑，其他必要支撑保留。

## 兼容范围

- 参考三星 M321RAJA0MB2-CCP/CCPKF 一类无散热片 DDR5 RDIMM，用户已做过该型号局部装卸。**不支持马甲条，不宣称兼容未验证的 DDR4 或其他板形。**
- 默认交付 3.6 mm 定位销/间隙孔外壳，保留 HDD 底部及侧面孔位；并非已经攻好 6-32 螺纹的金属硬盘。实际托架定位销配合需确认。
- SATA 单侧避让进深 7.5 mm，无电气连接功能；目标背板插座的实物避让仍需确认，不能保证所有硬盘座通用。
- 普通 PLA 不提供 ESD 防护认证。完整实物装配、实际按压力、疲劳、振动与跌落均未验证。

## 检查与重建

完整几何检查通过：512 个 DIMM 组合、242 个满载托盘入口位置、1520 个底层取出位置、132 个盖板路径位置；另有孔位、SATA、止挡、网格及加强截面检查。盖板、托盘与 v4.2 字节一致。

Bambu Studio 2.8.2.61 两盘正常切片无警告；36 个支撑区域、九条活动间隙、186 个根部逐层模型连接、八个齿头间隙、六孔零支撑、两个拱顶上部零支撑通过。孔口细分后新增的弦内顶点已纳入局部屏蔽，980 个涂色三角面保存后保持。几何与名义刀路检查不模拟熔融下垂、粘接强度、拆支撑力或热翘曲。

[几何](../models/v4.3/verification.json) · [加强结构](../models/v4.3/reinforcement-check.json) · [切片](reports/v4.3-slicing.json) · [支撑与间隙](reports/v4.3-toolpath-audit.json) · [根部](reports/v4.3-root-beads.json) · [齿头](reports/v4.3-tooth-clearance.json) · [侧孔](reports/v4.3-side-holes.json) · [拱顶](reports/v4.3-windows.json)

运行 `python src/build_v4_3.py --output-dir models/v4.3`。用 `prepare_v3_2_project.py --version 4.3 --plates 1-pin-clearance 2-upper-trays`（另传 Bambu、profiles、models 及 output-dir）输出至 `build/v4.3-unpainted-projects`，再运行 `prepare_side_hole_project.py --geometry-version 4.3 --arch-windows --source-version 4.3-unpainted --release-version 4.3` 并传 Bambu 路径。

运行 `audit_v4.py --version 4.3 --geometry-version 4.3 --depth 7.5`、`audit_tray_roots.py --version 4.3`、`audit_tooth_clearance.py --version 4.3`、`audit_side_hole_supports.py --version 4.3 --baseline 4.3-unpainted`、`audit_v4_1_windows.py --version 4.3 --baseline 4.3-unpainted`。用 `preview_floor_v4_3.py` 和 `preview_v4_1.py --version 4.3` 生成实际几何/支撑图；干净提交并固定标签后运行 `package_v4_3.py`。旧版本文件、标签与附件不覆盖。

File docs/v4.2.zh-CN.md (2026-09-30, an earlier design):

# v4.2：完整两盘发行版

这是一个以 **147×101.6×26 mm 的 3.5 英寸硬盘外形**收纳 **8 条无散热片 DDR5 RDIMM** 的盒子。底层两个槽位与外壳一体，另有两片各容纳三条内存的活动托盘。开盖后逐层取放；托盘与盖板日常使用均无需螺丝，盖板可选螺丝只用于额外加固。

v4.2 是完整版本：统一源码、四个零件、两盘工程、说明及检查报告，通过固定标签 `v4.2` 发布。**无需搜集或拼接历史补丁。** 正式版本号表示交付内容固定，不表示已经完成跌落或寿命认证；3 mm 基座、齿头下方避让、底部过渡和完整装配仍待本轮实物验证。

## 下载与打印

从 [v4.2 Release](https://github.com/helixzz/rdimm-hdd-case/releases/tag/v4.2) 下载 `rdimm-v4.2-complete-P2S.zip`，解压后用 Bambu Studio **打开为工程**，按实际耗材重新切片。参考为 P2S、0.4 mm 喷嘴、PLA Basic、0.20 mm 层高。

| 打印盘 | 工程文件 | 零件 | 参考耗时 | 耗材 |
|---|---|---|---|---|
| 1 | `rdimm-4.2-plate-1-pin-clearance-P2S-PLA-Basic.3mf` | 外壳＋盖板 | 2 小时 11 分 02 秒 | 91.53 g |
| 2 | `rdimm-4.2-plate-2-upper-trays-P2S-PLA-Basic.3mf` | 中层＋顶层托盘 | 59 分 30 秒 | 33.94 g |
| 合计 | 两盘、四件 | 完整一套 | 约 **3 小时 10 分 31 秒** | **125.47 g** |

时长是切片估计，不含换盘、拆支撑和装配。保留工程中的方向、支撑和局部屏蔽：六个侧孔内及两个拱顶上部不生成支撑，其余卡扣、舌片和 SATA 避让顶面仍需支撑。不要全局关闭支撑。包内 STL 用于其他切片器，**不包含这些打印配置**。

完整包包括两盘工程、四个零件的 STL、支撑示意、几何/刀路报告、提交号和 SHA-256。源码可在同一 Release 的 Source code 下载项获取。

## 兼容与结构

- 目标参考：三星 M321RAJA0MB2-CCP/CCPKF 一类无散热片 DDR5 RDIMM。用户已做过该内存的局部实物装卸；**不支持马甲条，不宣称兼容未验证的 DDR4/其他板形**。
- HDD 外形及底部、两长边安装孔保留；默认交付 3.6 mm 定位销/间隙孔外壳。它不是已攻好 6-32 螺纹的金属硬盘。具体托架定位销及实际背板配合仍需检查。
- SATA 单侧避让采用 7.5 mm 名义进深，仅供避开背板插座，盒子没有电气连接功能。不能把名义避让等同于任何硬盘座均已验证兼容。
- 盖板采用 RC4 的连续连接颈间隙、入口斜面、平面承托和独立止退。按压解锁后滑动 8 mm，再抬起；装回时反向操作。
- 两条长内壁采用从底板长出的连续内凹 R6 过渡，取消高位三角凸棱；保留卡扣根部圆角、缩小后的拱形拨扣窗口及操作标记。普通 PLA 不提供防静电认证；这是收纳结构，不作为 ESD 防护的替代品。

## 本版修复的托盘缺陷

此前两片活动托盘的第一弹臂起点为 Y14.5，外壳柱位避让切到 Y14.3，只剩约 **0.2 mm 连接薄片**。实物清理支撑后舌片脱落。理想网格仍然连通，所以旧的“连通且无干涉”检查漏掉了这个制造缺陷。

本版按反馈将基座沿弹臂方向加厚至 **3 mm**，第一弹臂起点后移至 Y17.3。基座从床面连续建立，保持与柱子末端 0.3 mm 名义间隙及 R1 根部过渡；压住 DIMM 的齿头、拨片位置均不变。自由弹臂由 18 缩至 **15.2 mm**，可能需要更大按压力，实际手感和寿命尚待确认。

基座改动

绿色是新增的永久结构，**不是支撑，不能剪掉**。另外两处弹臂保持原位置和结构。

## 齿头下方避让和底部过渡

外壳与两片托盘共八处 DIMM 卡簧的齿头下方，固定框架局部下让 **0.5 mm**，保留齿头厚度、压住 PCB 的位置和 PCB 承托高度。设计净空由约 0.2 增至约 0.7 mm；当前 0.20 mm 层高刀路中的模型表面净空为 **0.6 mm**。局部仍有可拆的一层支撑界面，清理后才是活动间隙，不要将它留在齿头下面。

此前底部 R2 圆角上方另有一条高位三角加强带，截面在上方向内伸出，形成照片所示的凸棱。本版取消该带，改为**贴着底板、向侧壁平顺收拢的内凹 R6 圆弧**。底板顶面 Z4，圆弧顶点 Z10，第一层活动托盘底面 Z10.8，保留 0.8 mm 竖向间隔。另检查了底层 DIMM、安装孔净空和装卸路径；不能只凭圆角低于托盘就断定所有结构都不会干涉。

底部截面对比

此修改不改变外形、SATA 避让和安装孔坐标，也不保证消除外壁横纹；打印表面改善和实际抗震强度仍待验证。

## 已有打印件如何复用

| 已有零件 | v4.2 中的关系 | 处理 |
|---|---|---|
| v4.1-rc1 / rc2 外壳 | 接口保留，但缺少齿头下让和新底部过渡 | 要获得全部修复需重打外壳 |
| v4.1-rc4 盖板 | STL 字节一致 | 可以继续使用 |
| v4.1-rc1 至 rc4 的两个活动托盘 | 均包含旧薄弱基座 | 替换为本包第 2 盘 |
| v4.0 / v3 系列零件 | 不是本版匹配接口 | 不混装 |

从零制作时打印本包两盘即可。已有 RC4 盖板可以复用，其 STL 字节一致；若复用，可在第 1 盘取消盖板对象后重新切片。外壳和两片托盘均有更新，完整修复需要这三件新零件。

## 拆支撑与检查

支撑示意

蓝色保留，橙色拆除。托盘弹臂固定端的实心基座必须保留，只拆齿头/拨片下的支撑及其附着片。先检查六处活动托盘弹臂均连接完整、轻拨后回弹，再逐槽验证 DIMM 装卸。盖板先在空盒上徒手开合；若越推越紧、发白或出现裂纹，不继续强压。最后验证完整叠放及空盒插入目标硬盘槽的避让。

## 验证范围

- 完整几何通过：512 个 DIMM 组合、242 个满载托盘入口位置、1520 个底层取出位置、132 个盖板路径位置，以及弹臂释放、DIMM 抬起/抽出、孔位、SATA、止挡和网格检查。
- 六处活动托盘根部都有完整实心核心及跨根部连接；第一处另检查完整 3 mm 长基座。旧第一处的 1×1×6 mm 核心缺失 4.8 mm³，能够复现并拦截旧缺陷。
- 六处弹臂 × 31 层，共 **186 个逐层模型刀路连接检查**通过，排除所有支撑挤出，确认根部两侧由模型材料连通。
- 两盘 Bambu Studio 2.8.2.61 切片无警告，工程导入/支撑涂色保存通过。36 个支撑区域、九条活动间隙、六孔无支撑、两个拱顶无高位支撑及约 1.158 mm 名义封顶跨度检查通过。
- 八处齿头/固定框架的名义模型刀路净空均至少 0.6 mm；间隙内支撑界面到上下模型表面各至少 0.2 mm。底部截面回归检查确认旧高位凸棱消失、新底部过渡存在；旧 RC4 模型可重建且 STL 字节保持一致。
- **尚未验证：完整实物配合、清理便利性、实际按压力、疲劳、振动及跌落。** 几何与名义刀路不模拟焊接强度、热翘曲或支撑拆除力。

[结构检查](../models/v4.2/tray-root-fix.json) · [完整几何](../models/v4.2/verification.json) · [切片](reports/v4.2-slicing.json) · [支撑及间隙](reports/v4.2-toolpath-audit.json) · [根部刀路](reports/v4.2-root-beads.json) · [齿头间隙](reports/v4.2-tooth-clearance.json) · [底部截面](reports/v4.2-floor-section.json) · [侧孔](reports/v4.2-side-holes.json) · [拱顶](reports/v4.2-windows.json)

## 重建与版本管理

`python src/build_v4_2.py --output-dir models/v4.2`。配置两盘时使用 `prepare_v3_2_project.py --version 4.2 --plates 1-pin-clearance 2-upper-trays`（另传 Bambu、安装配置、模型目录，输出到 `build/v4.2-unpainted-projects`）。再运行 `prepare_side_hole_project.py --geometry-version 4.2 --arch-windows --source-version 4.2-unpainted --release-version 4.2` 并传 Bambu 路径，生成最终 `build/v4.2-projects`。

运行 `audit_v4.py --version 4.2 --geometry-version 4.2 --depth 7.5`、`audit_tray_roots.py`、`audit_tooth_clearance.py`、`preview_floor_v4_2.py`、`audit_side_hole_supports.py --version 4.2 --baseline 4.2-unpainted`、`audit_v4_1_windows.py --version 4.2 --baseline 4.2-unpainted`。源码/报告提交且标签固定后，用 `package_v4_2.py` 打包。旧标签、旧模型和旧 Release 不覆盖，后续几何改动另开新版本。

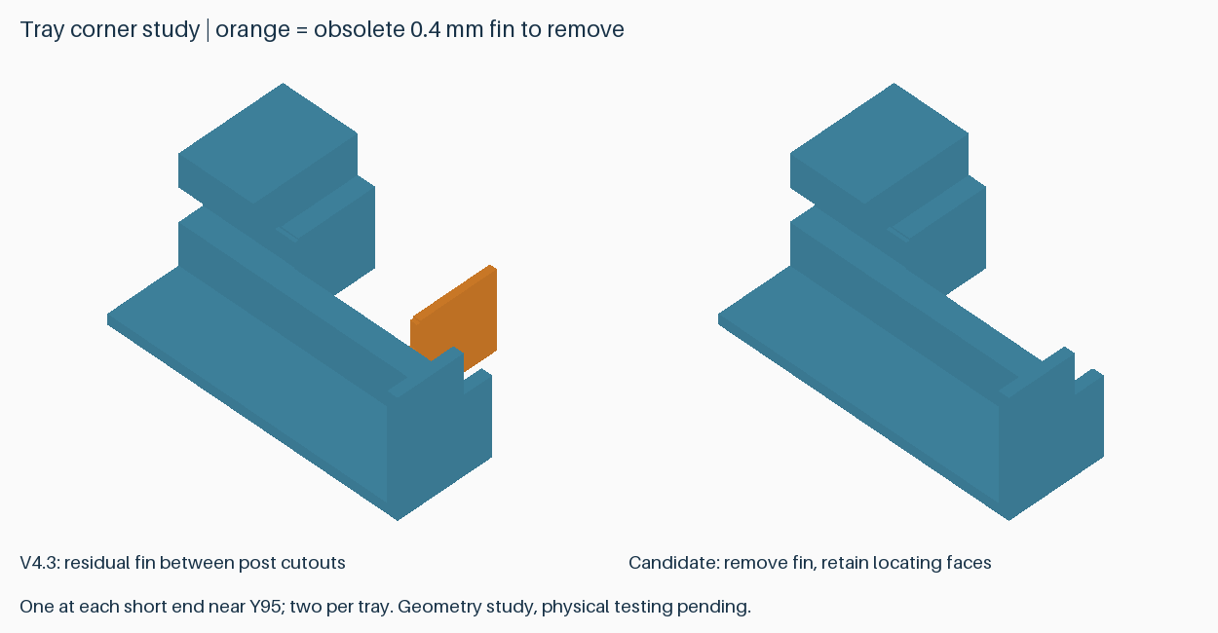
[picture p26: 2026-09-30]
docs/reports/tray-corner-fin-comparison.png

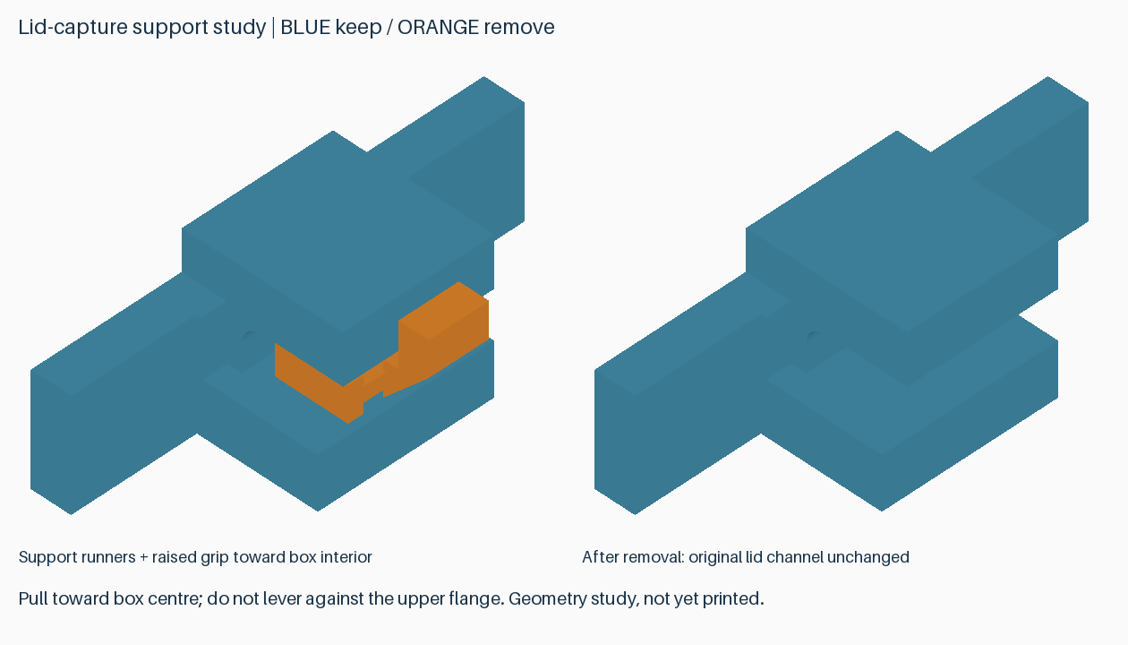
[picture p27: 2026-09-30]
docs/reports/capture-pull-support.png

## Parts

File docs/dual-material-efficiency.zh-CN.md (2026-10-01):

# 双材料效率评估（RC3，未发布新打印工程）

2026-10-01。用户尚未收到 Support for PLA，因此以下为本地 Bambu Studio 2.8.2.61 切片对比，不是实测。使用已发布 RC3 的四试件配置工程，保留原模型、0.20 mm 层高、界面厚度、800 mm³ 双向冲刷量及禁止冲刷入模型/支撑的设置；不覆盖 Release 附件。

## 开销来自哪里

原盘预计 3823.10 秒，Support for PLA 总计 5.9140 g，切片统计 `main_used_g` 仅 0.04879 g。约 99.2% 的专用材料不在这项成形用量中，主要用于冲刷、擦料塔等换料消耗。继续把界面缩小一半，理论上只直接省约 0.024 g；减少换料或分摊换料才是主要方向。

切片器的 Flush 与 Prime tower 分项分别为 1388.34 秒、709.73 秒，合计约 34 分 58 秒。分项统计不应全部叠加成第二个总耗时。

17 个建模界面已按高度合并打印，并非每片分别换料。专用材料出现在层顶 Z=0.8、1.0、3.2、3.4、4.4、4.6、4.8、5.0、5.2、5.4 mm；后三层含拨片的自动支撑界面。交替材料顺序使这一盘共换料 10 次。

## 不削减冲刷量的对比

这里一“组”指 RC3 的四个试件，不是一个完整收纳盒。

| 方案 | 一盘换料 | 一盘耗时 | PLA 总量 | Support 总量 | 每组平均耗时 / Support |
|---|---:|---:|---:|---:|---|
| 已发布 RC3，一组 | 10 | 1:03:43 | 16.95 g | 5.91 g | 1:03:43 / 5.91 g |
| 同高度两组，一盘 | 10 | 1:23:35 | 26.26 g | 5.96 g | 0:41:47 / 2.98 g |
| 一组，擦料塔跳层并移远 | 10 | 0:58:05 | 15.11 g | 5.91 g | 0:58:05 / 5.91 g |

两组方案将第二份沿 Y 移动 92 mm，Z 和朝向相同。几何副本和界面可共享换料；切片无警告，试件本体用量恰好翻倍，而冲刷和擦料塔分项不变。相比单组分开打印，平均耗时下降约 **34.4%**，平均专用材料下降约 **49.6%**。这支持未来将同层高生产零件尽量排在同盘，但不能直接套用为完整外壳、托盘的节省比例，也不主张仅为摊成本而多打印无用试件。

擦料塔跳层采用 `wipe_tower_no_sparse_layers=1`。原位置 X205/Y165 下，单组及双组均被切片器以 -64“Object conflicts”拒绝；单组移至 X205/Y205 后切片通过。该方案省约 **5 分 38 秒、1.84 g PLA**，不减少专用材料用量或换料次数。Bambu 官方将它标为实验功能，要求满足塔与模型相对位置限制，并提示额外 Z 移动可能增加渗料、拉丝。故不纳入当前以可靠性为先的默认打印配置。[官方 2.8.2 发布说明](https://github.com/bambulab/BambuStudio/releases/tag/v02.08.02.60)

## 后续优先级

1. **批量时共享换料**：同高度、同方向、按层打印，尽量让多个有用零件共用同一次换料。先保证平台、擦料塔、支撑和喷头路径净空。
2. **在结构设计阶段减少专用材料出现的层数**：集中不同机构的界面高度；评估能否用自承托把手取消低处脚垫的专用接触层。单纯把平面内的17片合成一片，未必减少换料。此方向会改动几何，需要新的切片、装卸与实物检查，尚无已验证的次数目标。
3. **材料到货后再校准冲刷量**：800 mm³ 是保守起点，不是已证明的最小值。两个切换方向可分别试验，但支撑材料混入 PLA 会影响结构粘接，PLA 混入支撑界面也可能改变拆除表现；不单靠颜色变干净来判断。暂不删擦料塔、不改成单层界面、不把换料废料冲进功能件。

当前推荐先保留 RC3 单组基准，确认材料的拆除效果，再把通过的工艺应用到生产排版。效率实验文件仅存于忽略的 build 目录，不作为新发行版或打印交付。

复现：`python src/evaluate_dual_efficiency.py --bambu <bambu-studio executable>`；需要此前 RC3 的配置工程与切片输出。机器无关的数据见 [对比报告](reports/dual-material-efficiency.json)。实验没有连接或操纵打印机。

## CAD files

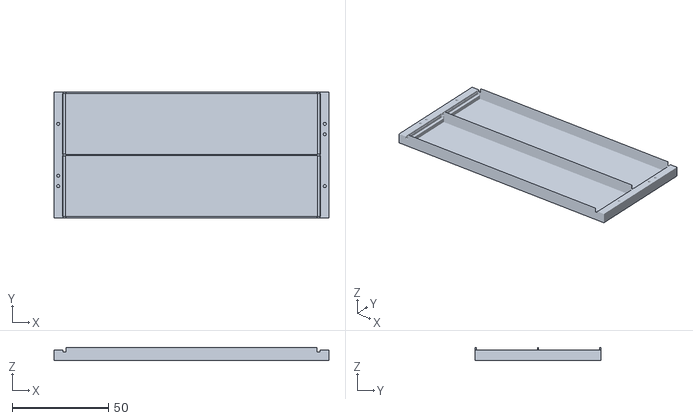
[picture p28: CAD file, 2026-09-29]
models/v2-retention/tray-bottom-2.stl
143.2 x 65.4 x 6.80

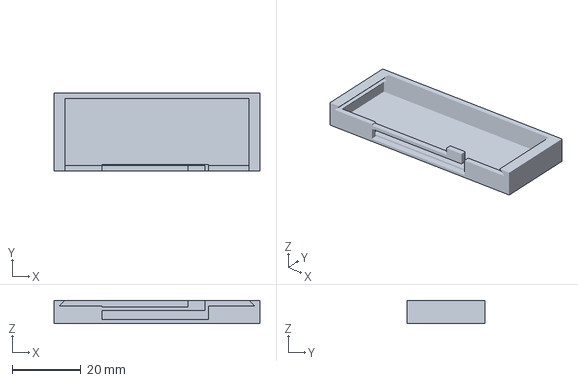
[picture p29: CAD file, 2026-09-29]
models/v3.2-rc2-latch-check/rdimm-3.2-rc2-plate-A-base-only.3mf
60.0 x 22.6 x 6.80 mm

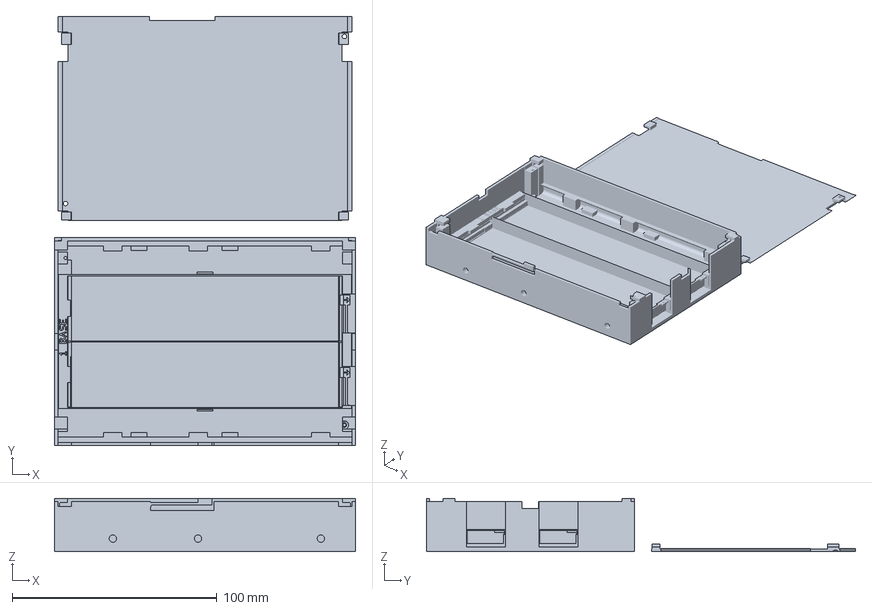
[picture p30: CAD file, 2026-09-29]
models/v4.1-rc1/rdimm-4.1-rc1-plate-1-pin-clearance.3mf
147.0 x 209.6 x 26.0 mm

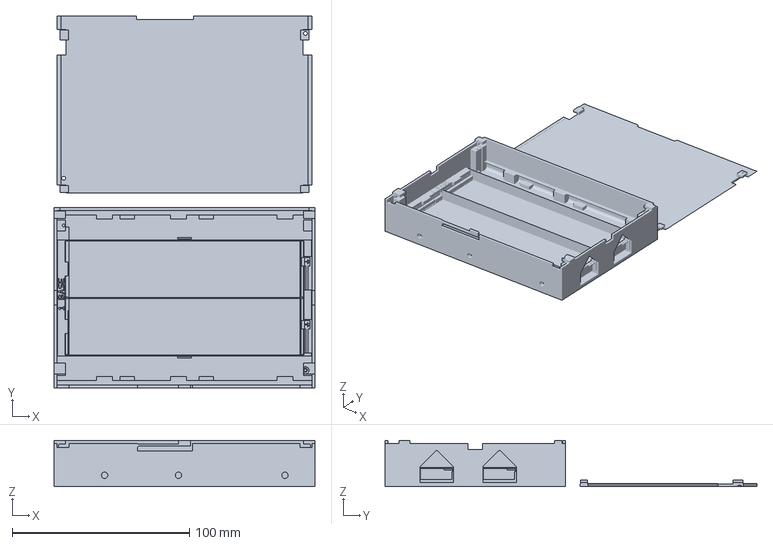
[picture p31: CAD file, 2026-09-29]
models/v4.1-rc2/rdimm-4.1-rc2-plate-1-pin-clearance.3mf
147.0 x 209.6 x 26.0 mm

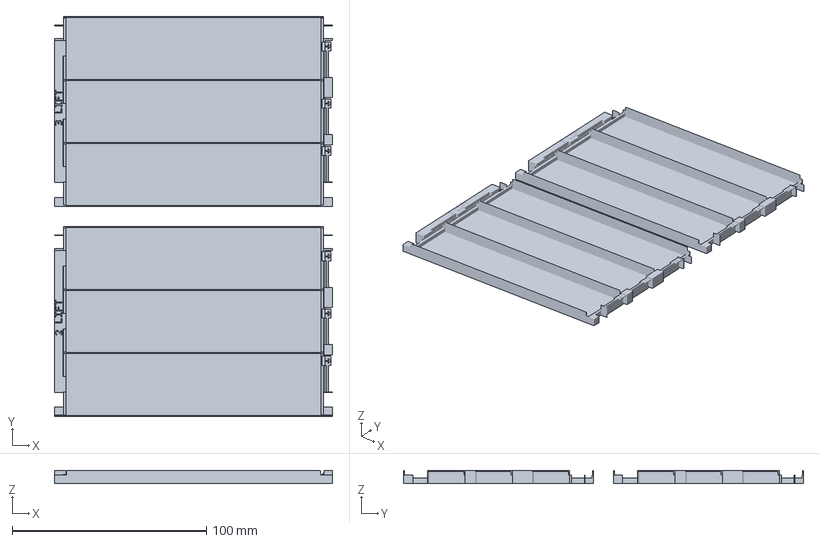
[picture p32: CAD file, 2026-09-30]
models/v4.1-rc4/rdimm-4.1-rc4-plate-2-upper-trays.3mf
143.2 x 205.8 x 6.80 mm

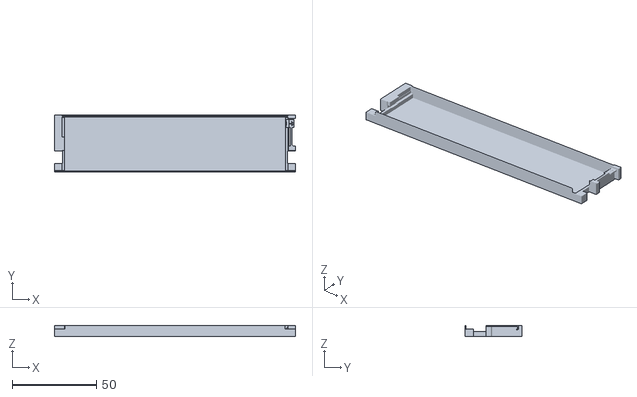
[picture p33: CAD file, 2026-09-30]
models/v4.4-rc1-support-trial/B-cleaned-reference-NOT-PRINT.stl
143.2 x 33.6 x 6.80

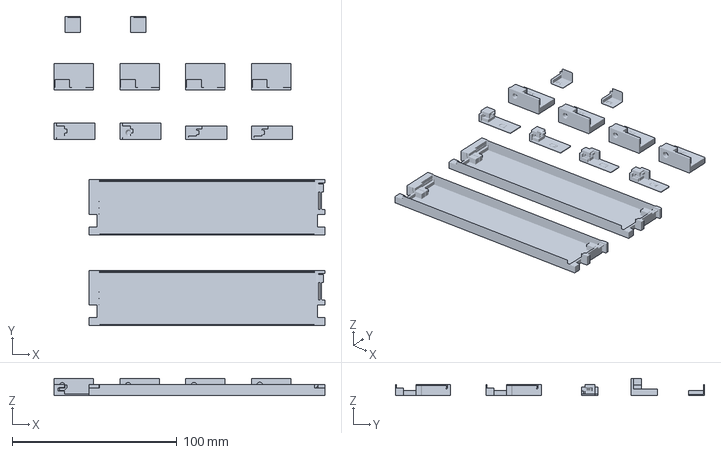
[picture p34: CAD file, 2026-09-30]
models/v4.4-rc2-combined-trial/rdimm-4.4-rc2-combined-trial-plate-0-combined.3mf
164.6 x 187.8 x 10.4 mm

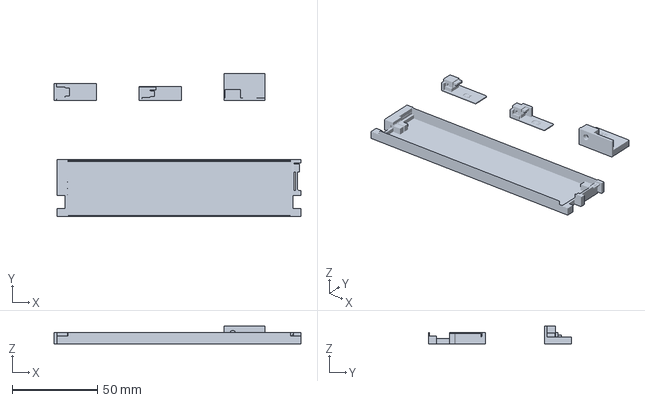
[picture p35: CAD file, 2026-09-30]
models/v4.4-rc3-dual-trial/rdimm-4.4-rc3-dual-trial-plate-0-dual.3mf
145.1 x 84.1 x 10.4 mm

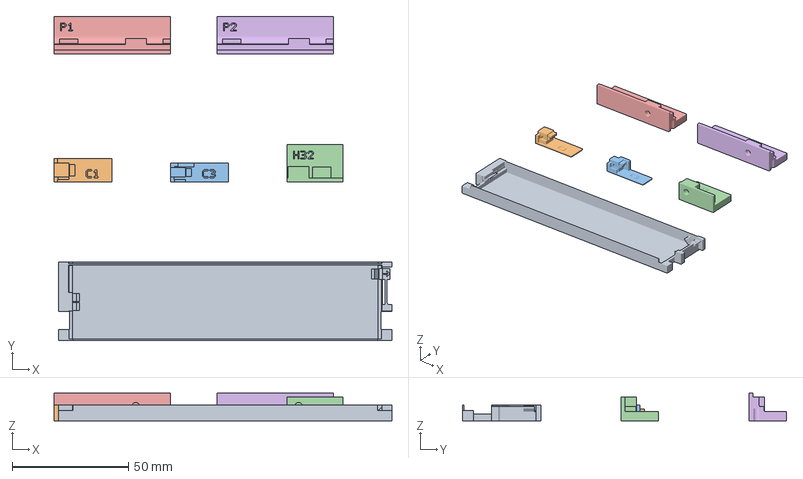
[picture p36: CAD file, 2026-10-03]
models/v4.4-rc4-product-trial/rdimm-4.4-rc4-product-trial-plate-0-dual.3mf
145.1 x 139.1 x 12.0 mm
A
C1
C3
H32
P1
P2

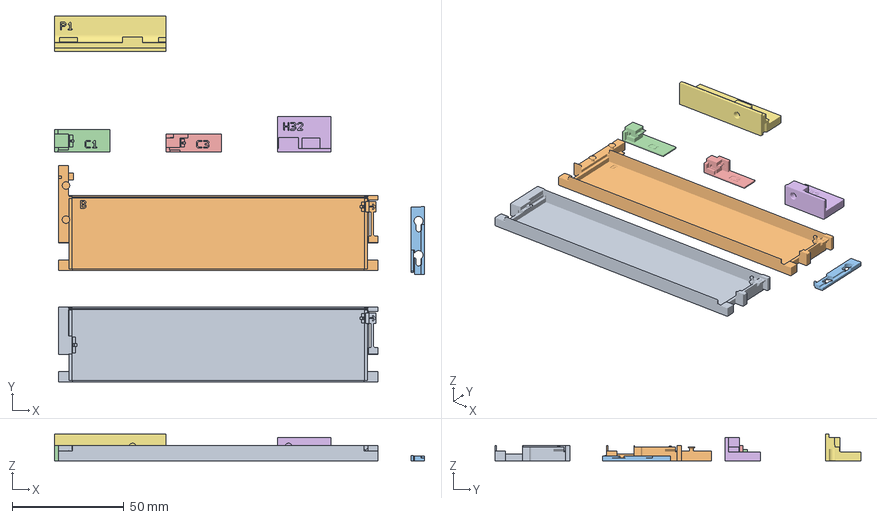
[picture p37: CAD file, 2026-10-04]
models/v4.4-rc5-peel-trial/rdimm-4.4-rc5-peel-trial-plate-0-dual.3mf
166.0 x 164.1 x 12.0 mm
A
B
B-KEEPER
C1
C3
H32
P1

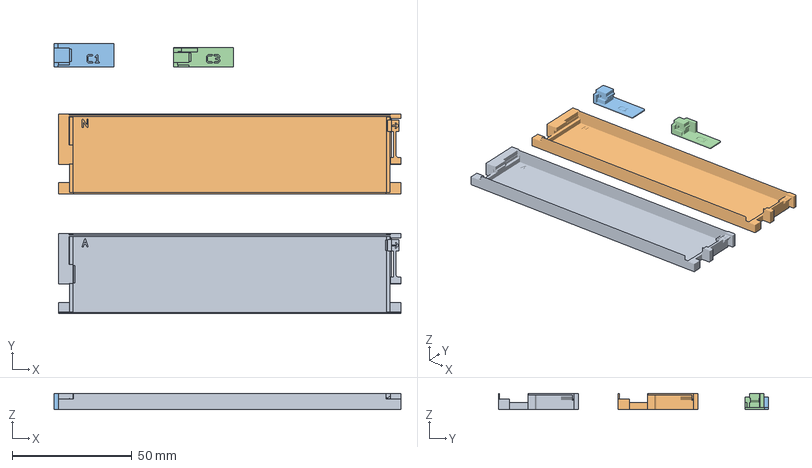
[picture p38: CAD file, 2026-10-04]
models/v4.4-rc6-solid-trial/rdimm-4.4-rc6-solid-trial-plate-0-dual.3mf
145.1 x 113.1 x 6.80 mm
A
N
C1
C3

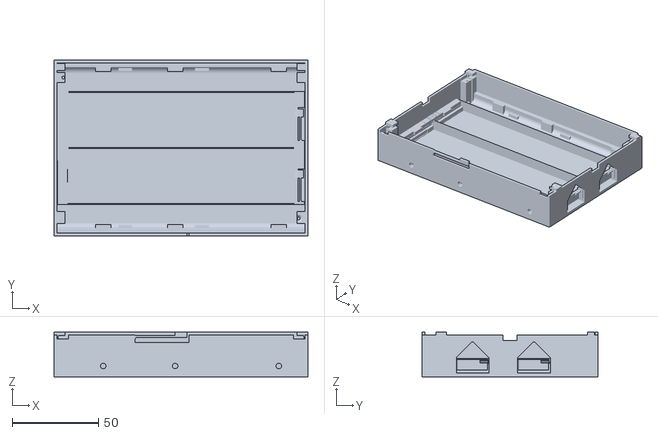
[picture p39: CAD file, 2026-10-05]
models/v4.4.1/body-pin-clearance.stl
147.0 x 101.6 x 26.0

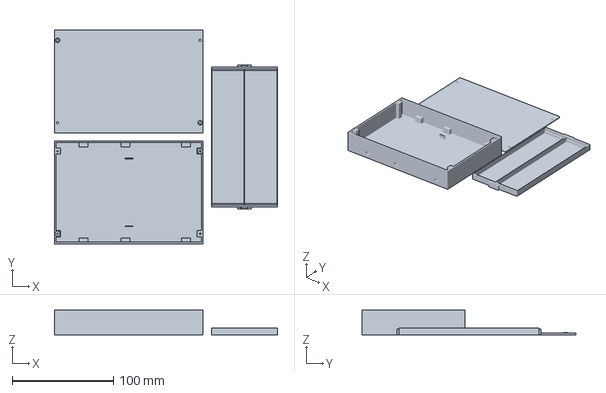
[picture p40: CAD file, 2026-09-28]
plates/v2/plate-1-side-inserts.3mf
220.4 x 211.2 x 24.4 mm

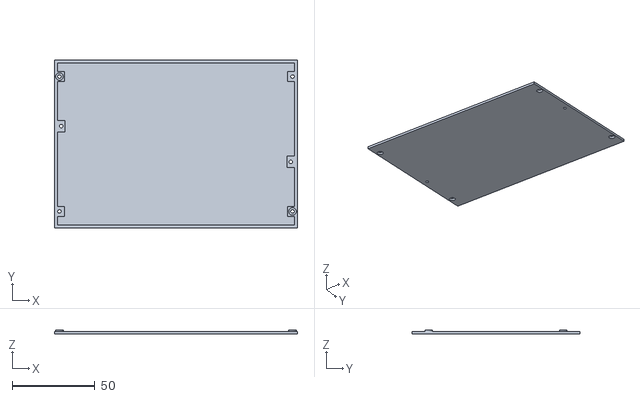
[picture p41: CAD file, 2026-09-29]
models/v2-retention/lid-retention.stl
147.0 x 101.6 x 2.40

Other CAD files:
models/v4.1-rc3/rdimm-4.1-rc3-plate-1-thread-pilot.3mf
models/v4.4.1/1-pin-clearance/rdimm-4.4.1-plate-1-pin-clearance.3mf
models/v4.4.1/2-upper-trays/rdimm-4.4.1-plate-2-upper-trays.3mf
models/v3.2-rc2-latch-check/latch-test-base.stl
models/v1/body.stl
models/v1/fit-coupon-1-slot.stl
models/v1/lid.stl
models/v1/tray-2-slots-print-1.stl
models/v1/tray-3-slots-print-2.stl
models/v2-retention/first-test-plate.stl
models/v2-retention/keeper-2-print-2.stl
models/v2-retention/keeper-3-print-4.stl
models/v2-retention/test-keeper-1-print-2.stl
models/v2-retention/test-tray-1.stl
models/v2-retention/tray-middle-3.stl
models/v2-retention/tray-top-3.stl
models/v2-retention/upgrade-plate-1-lid-bottom-keepers.stl
models/v2-retention/upgrade-plate-2-middle-top.stl
models/v2/body-pilot.stl
models/v2/body-side-inserts.stl
models/v2/fit-coupon-1-slot-print-3.stl
models/v2/lid.stl
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

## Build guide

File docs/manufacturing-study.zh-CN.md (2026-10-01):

# 打印质量、效率与后处理评估

本轮完成五项独立评估，并用 Bambu Studio 2.8.2.61 对其中两项及其组合实际切片。优先候选是**拨片下方斜撑、取消支撑把手底脚**；局部残留避让作为备选。研究保留在源代码和报告中，未覆盖 v4.3 完整套件、v4.4 RC3 试件或已发布工程。Support for PLA 尚未实物验证，本页不构成新打印版本。

## 1. 拨片下方：从水平悬空改成约 45° 斜面

原结构的外侧按压拨片有水平悬空底面，需要一小柱自动支撑。候选只在拨片下方补材料：最外侧位置、顶部按压面、PCB 锁止齿及 3 mm 基座保持原位；斜面从弹臂长出，不连接固定框架。

完整八处拨片合计增加约 **32.77 mm³** 几何体积。外壳、两层活动托盘的名义装卸、弹臂释放、DIMM 包络及顶盖路径检查通过。斜撑位于自由端附近，仍可能改变局部刚度，不能把通过位姿检查解读成按压力或疲劳不变。

在 A 试件中，切片器不再生成拨片下方自动支撑，且未为此新增支撑屏蔽。专用材料最高打印层由 Z5.4 降至 Z4.8；后处理少了一处需要清理的自动支撑。这比单纯调快支撑打印速度更直接。

## 2. 支撑把手：取消底脚，改成向上伸出的斜把手

原 A 的三个支撑主体各有落到底板的垫脚；每个垫脚又需要一片专用材料隔离层。候选从槽内支撑主体向外上方伸出斜把手，取消底脚，也取消底板上对应的三个接触区。

保留固定端两件、弹簧端一件的拆除数量；没有增加散件。全盘建模界面从 **17 片减为 14 片**，所有剩余界面仍采用原厚度、原材料。修正斜把手与接触薄片的体积重叠后，23 个分件均封闭、单连通，无材料体积重叠；五个支撑主体共 165 个水平抽取位姿通过。

实际刀路中，14 处界面均保留专用材料及上下 PLA 接触，H32 孔内仍没有支撑，专用材料未进入保留零件。另检查把手区域相邻层的名义路径覆盖；这不能预测把手是否会断，尤其根部受槽口限制，仍需实物拆除验证。

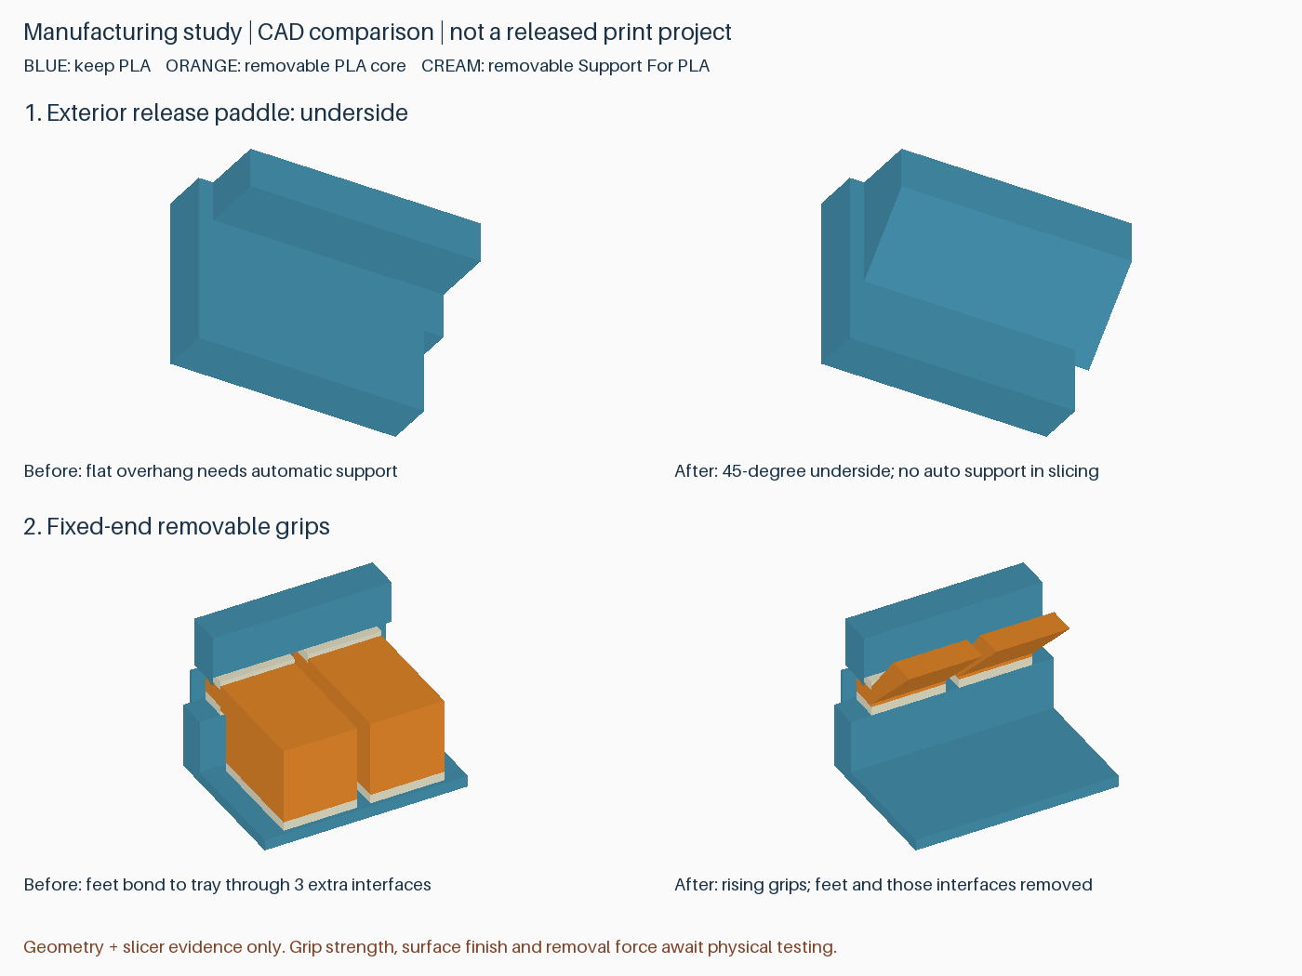
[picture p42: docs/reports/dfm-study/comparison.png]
CAD 前后对照


上图蓝色保留、橙色及米白色拆除；是实际候选 CAD 渲染，非实拍。第二行展示固定端两件，另一个底脚位于弹簧端。

### 切片对照

同一台 P2S、0.4 mm 喷嘴、0.20 mm 层高、PLA Basic＋Support for PLA。**一组四个试件，不是完整盒子，也不是批量分摊。** 保留擦料塔，两方向冲刷量均为 800 mm³；打印速度、温度、层高和全局支撑参数不变。

| 方案 | 预计时间 | 换料 | PLA（含冲刷/塔） | Support for PLA（含冲刷/塔） |
|---|---:|---:|---:|---:|
| 已发布 RC3 对照 | 1:03:43 | 10 | 16.95 g | 5.91 g |
| 仅拨片斜撑 | 0:58:20 | 8 | 15.82 g | 4.79 g |
| 仅取消把手底脚 | 0:55:18 | 8 | 15.45 g | 4.67 g |
| 两项合并 | **0:49:55** | **6** | **14.32 g** | **3.55 g** |

合并节省约 **13 分 48 秒（21.7%）**、**4.99 g 总耗材（21.8%）**；专用耗材减少约 **39.9%**。四组切片均无警告。收益来自删除不必要的支撑接触与打印层，而非减小冲刷量或降低界面质量。完整盒子各部位高度不同，不能直接套用这一比例。

## 3. DIMM 难放入：局部容纳残留，保留承托面

将此前 B 试件的局部避让扩展到完整八个槽位，单独评估。固定端与活动齿的局部顶面/底面约让开 0.3 mm，两端保留承托区域；不把整个 PCB 槽统一加宽。布尔切除略穿过原表面，避免留下零厚度薄皮。

- 三种完整结构对照（仅斜撑、仅避让、两者组合）分别通过 512 个 DIMM 包络位姿、242 个带 DIMM 托盘放入位姿、1,520 个底层释放位姿和 132 个顶盖位姿，以及现有其他几何检查。
- 在每槽两端的凹区放入模拟残留块：**0.1、0.2、0.3 mm** 块在新结构中均不碰名义就位 PCB；旧结构相同高度残留会干涉。**0.4 mm** 残留再次产生干涉。
- 对照检查也确认：残留若落在保留承托面上，仍会干涉。不能宣称“残留 0.3 mm 都无所谓”。

建议暂列为备选。若双材料能使现有槽面干净脱离，就没有必要主动削减活动齿局部截面；若实物仍有残留卡阻，再采用此方案，并验证保持力。

## 4. 柱顶支撑：剥离方向比把手长度更关键

对 C1/C3 测试一条具体路径：以下方入口边附近为轴，把支撑主体向上转，再考虑抽出。两者在该轴、该方向的 **6° 采样位姿开始与保留件相交**；此前 0–5° 采样不相交。这只排除了这条大幅转动路线，并非证明所有剥离方式都不可行。

现有外露把手下方可容纳所建模的 5×1×1 mm 工具接近空间。但内部粘接强度并未被几何分析覆盖，不能因有入口就保证容易撬出。继续加长把手容易增加弯矩；暂不推荐把“大力向上掰”作为设计拆除方式。

优先保留水平抽出动线、专用界面和 RC3 加宽后的把手。等材料到货，区分是界面没有分离、把手断裂，还是轨道卡住，再决定是否分段剥离。现在进一步缩小接触面积可能反而降低打印中的稳定性。

## 5. 小细节与表面质量：先找实际时间大头

读取完整 v4.3 两盘现有 G-code 及切片报告，总计约 3 小时 10 分 44 秒：

| 特征 | 外壳盘 | 托盘盘 | 判断 |
|---|---:|---:|---|
| Gap infill 小间隙填充 | 52 秒 | 59 秒 | 合计约占总时间 1%；不值得为此大改配合尺寸 |
| Bridge 桥接 | 13 分 07 秒 | 1 分 08 秒 | 外壳盘更值得继续研究结构原因 |
| Internal solid infill 内部实心填充 | 31 分 26 秒 | 7 分 51 秒 | 可挖掘空间较大，但涉及刚度、顶底面质量，不能直接删层 |

外壳盘桥接路径中，Z3.2 层约有 **29.1 m**，为最大的单层桥接路径来源。这个长度来自路径解析，不是该层独立耗时，也不能由总桥接时间按长度精确分摊。先研究这一层为何需要桥接，比全局提高桥接速度更有价值。

已确认无必要的角部 0.4 mm 残片及其底部细条，可沿用先前的完整清除方案：每张活动托盘约去除 16.66 mm³，主要收益是避免断片和清理，不应宣传成显著提速。下一完整版本仍按已选定的 **3.2 mm** 安装孔处理，保留之前孔内禁支撑的独立验证；本轮几何对照没有混入孔径变化。

关于成品精细程度：朝下悬空的外圆角可能增加陡峭悬垂；该处优先考虑斜面。底板长出的内凹过渡则是另一种截面，不应一并删除。打印朝向、接触面、适配间隙应分别处理，这是 [Prusa 设计指南](https://help.prusa3d.com/article/modeling-with-3d-printing-in-mind_164135) 对本项目最有用的原则。本轮没有全局减薄壁厚、减少顶底层、扩大卡槽或提高速度。

## 结论与验证范围

优先纳入下一编号候选：**拨片斜撑＋无底脚支撑把手**。局部残留凹槽保留为备选，C 支撑大角度上掰不采用；角部残片清除、3.2 mm 孔径延续已有结论。

完成的是几何干涉、示意弯曲位姿、材料分配和名义刀路检查，**不是粘接、疲劳、冲击、热变形或表面粗糙度仿真**。实际表面改善、拆除力、把手耐断性及 DIMM 固定力仍需试印。已发布文件不变，本页研究工程不作为生产下载文件。

复现顺序：

```text
python src/evaluate_dfm_geometry.py
python src/evaluate_dfm_slicing.py --bambu <Bambu Studio 可执行文件>
python src/audit_dfm_study.py
python src/preview_dfm_study.py
```

切片研究依赖先用 RC3 工程生成脚本建立本地配置与对照 G-code；审计还读取完整 v4.3 两盘切片结果。官方预设、机器路径及 G-code 不进入公开仓库。证据：[几何](reports/dfm-study/geometry.json)、[切片对比与文件哈希](reports/dfm-study/slicing.json)、[界面与残留检查](reports/dfm-study/audit.json)。

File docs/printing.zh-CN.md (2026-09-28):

# RDIMM 8 条收纳盒 v1：标准硬盘外形原型

本设计按普通无散热片 DDR5 RDIMM 的参考机械包络推进，目标参考型号为三星 M321RAJA0MB2-CCPKF / M321RAJA0MB2-CCP。

当前阶段：可打印的工程原型，已做几何检查，尚未切片、打印或实物试装。不是已认证的防静电容器或运输包装。安装孔需要后加工螺纹。

## 设计基准与来源

Micron 原厂文档《288-Pin DDR5 RDIMM Core》，Rev G，图 3（印刷页 24）给出：

- 名义板长 133.35 mm；上限 133.80 mm。
- 名义板高 31.25 mm；未另注尺寸的通用公差 ±0.15 mm，即按 31.40 mm 上限参考。
- PCB 厚 1.27 ±0.10 mm。
- 模块总厚度上限 5.57 mm；单侧元件高度参考上限 2.10 mm。
- 文档的产品家族覆盖 DDR5-6400。具体元件位置仍需对应料号附录。

原厂文档的授权分销商副本：
https://www.mouser.com/datasheet/2/671/ddr5_rdimm_core-3310292.pdf

三星 DDR5 双面 M321R8GA0BB0 的原厂资料第 96 页也给出 PCB 1.27±0.10 mm、双面各 Max 2.10 mm，推导包络为 5.57 mm。这是交叉参考，不是 M321RAJA0MB2-CCP 本型号的专用机械图。
https://www.ssd.group/wp-content/uploads/2022/10/DatasheetDDR5_16Gb_B_RDIMM_M321RxGAxBB0_Rev1.1.pdf

三星目标型号的电子规格可由 ASUS 原厂兼容列表确认：DDR5-6400、128 GB、RDIMM；该列表不提供机械尺寸。
https://dlcdnets.asus.com/pub/ASUS/server/ESC8000A-E13/AVL/ESC8000A-E13_20250819.pdf?model=ESC8000A-E13

5.57 mm 是采用的参考设计包络上限，不是声称所有无散热片 RDIMM 的实测厚度完全相同，也不是保证所有型号的元件位置相同。

## 结构

外形 147 × 101.6 × 26 mm。盒体高 24.2 mm，上盖厚 1.8 mm。底层 2 条，中层 3 条，顶层 3 条，共 8 条。

每个托盘槽的名义腔体为 134.4 × 31.8 × 6.0 mm。托盘底板 0.6 mm，每层总高 6.6 mm；底座 4.4 mm；三层加盖正好 26 mm。盖子内侧浅凹 0.3 mm，为托盘堆叠预留总高误差；螺钉周围和外圈保持原厚。

两端台阶支撑 PCB 的短边，台阶面高出托盘底面 2.8 mm。按元件向两侧各延伸 2.10 mm 的参考结构，元件离托盘底板约 0.10 mm，上方余量约 0.33 mm。此设计不以芯片承压定位。

几何验证假设 PCB 两个短边各有 2 mm 无元件区。这是内胆接触位置的设计假设，尚未取得目标三星型号的元件布局图验证；请先用单槽样件确认实际短边没有元件或标签堆叠干涉。不可用盖子或下一层托盘强压内存入位。

取出上盖后逐层取托盘。两端的小握持筋用于提起托盘。下层导向筋限制两槽托盘的左右移动，上方两层由外壳限位。盖子无外凸铰链或卡扣。

## 文件与数量

| 文件 | 数量 | 用途 |
|---|---:|---|
| fit-coupon-1-slot.stl | 先打印 1 个 | 单槽装配验证；不装进盒子 |
| body.stl | 1 | 外壳与安装孔柱 |
| tray-2-slots-print-1.stl | 1 | 底层 |
| tray-3-slots-print-2.stl | 2 | 中层和顶层 |
| lid.stl | 1 | 上盖 |
| [src/build_case.py](../src/build_case.py) | — | 可修改的参数化生成源文件 |
| verification.json | — | 数字几何检查结果 |

各 STL 已独立放到打印坐标原点。外壳和托盘底面朝下；盖子已翻转为外表面朝下。不要把分别归零的文件原位叠放当作完整装配模型。零件装配由外壳形状及上述顺序定位。

## 安装孔与五金

标准孔位参考 Seagate Desktop HDD Manual 100686584 Rev Y 图 4。原点位于模拟硬盘连接器端、一个长侧面和底面的交点，X 沿长边、Y 沿短边、Z 向上。

- 侧孔：X = 28.4988、70.104、130.0988 mm；两侧各 3 个，Z = 6.35 mm。
- 底孔：X = 41.275、85.725 mm；Y = 3.175、98.425 mm，共 4 个。
- 真实硬盘安装接口为 6-32 UNC。不要使用 M3 硬拧。

本版 STL 内的上述 10 个孔为 **2.7 mm 攻牙底孔，盲孔深 3.7 mm**，没有已成形的螺纹。打印后需按实际孔径修孔、用适合盲孔的 6-32 UNC 丝锥后加工，彻底清理碎屑，再装内存。底板余厚仅 0.7 mm，必须限制加工深度。若没有工具，可先试装不紧固；不要强拧硬盘螺丝代替攻牙。

此塑料螺纹是轻载原型方案，耐反复拆装能力尚未验证。不能套用金属硬盘的扭矩规格。机箱安装时，螺钉伸入盒子长度应不超过 **3.0 mm**；按托架厚度选择长度，必要时加垫片。孔位兼容不意味着可以沿用任意长度的硬盘螺钉。

上盖另用 **4 颗 M2 沉头螺钉，建议从 M2×8 开始核对**；沉头直径不超过约 4.3 mm。盖上通孔 2.2 mm，盒体上盖孔为 1.6 mm 底孔，也需适当修孔和攻 M2 螺纹。上盖螺钉头必须完全进入沉孔，保持 26 mm 外形包络。不同头型需实际核对。

图纸来源：
https://www.seagate.com/www-content/product-content/barracuda-fam/desktop-hdd/barracuda-7200-14/en-us/docs/100686584y.pdf

不包含 SATA/SAS 接口外形；不承诺热插拔背板对接。采用传统常见的 6 侧孔、4 底孔布局，不覆盖所有厂商托架及高容量盘孔位变体。

## P2S 打印起点

建议先打印单槽样件，再打印一套，实物验证后再批量。不要按比例缩放整个模型；缩放会改变安装孔距。

- 使用实际 P2S / 0.4 mm 喷嘴 / 耗材配置，STL 单位为毫米，100% 比例。
- PETG 可作为原型起点；机箱内温度较高时，依据材料规格选择 ASA 等更耐热材料。
- 0.20 mm 层高；托盘底板为 0.60 mm，建议底部至少 3 层。外壳 4 层墙，托盘至少 2 层墙，Arachne 薄壁处理；具体路径以切片预览为准。
- 零件均以大平面朝下。原则上不需要支撑；先检查侧孔的小跨度顶部能否正常桥接。
- 上盖已在 STL 中翻转为外表面朝下（较大的沉孔口朝热床），内侧浅凹朝上，避免大面积架空桥接；保留文件的导出方向。
- 核对托盘 0.6 mm 隔片是否连续、两端台阶和握持筋是否完整。翘曲或底部象脚应先排除，再判断装配间隙。
- 先将内存自然放在样件两端台阶上，确认颗粒不顶底、短边支撑不碰元件，并能轻松取出。样件槽宽余量包含打印误差，不能保证未经校准的打印机一次即合适。

本版按裸条尺寸设计，没有额外计入完整防静电袋、厚泡棉或运输缓冲层。普通 PETG/ASA 不是静电耗散材料；若要求按防静电包装储存，应换用有明确 ESD 性能的材料/内衬并重新留量，不能直接把袋子硬塞进这些槽里。

## 验证与容量解释

已验证：每份导出 STL 为单一闭合实体、法线一致；装配后零件之间无实体重叠；8 个参考内存模型无实体干涉；两侧和底部螺钉以 3.0 mm 侵入深度不会进入内存或托盘空间。

未验证：真实切片、打印公差、三星目标型号元件位置、塑料螺纹强度、机箱实物适配和 ESD 性能。预览图由实际几何网格渲染，不是实物照片。

之前以 4.0 mm 实厚假设得到的 11 条/16 条估算已被本版的 5.57 mm 参考包络取代。8 条是当前保守结构的容量，不是对所有排布方法的数学最大值。如果后续有更薄实物的可靠尺寸，可重新生成更密的托盘，同时保留外壳外形和安装孔位。

加厚竖放方案仍为备选，尚未生成其完整收纳盒；在同一保守厚度包络下可从约 13 条、38 mm 总高继续设计。本仓库 v1 仅提供 26 mm 完整收纳盒，尚未提供 38 mm 完整版本。

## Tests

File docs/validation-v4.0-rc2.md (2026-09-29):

# v4.0-rc2 validation

Status: geometry and reference Bambu slicing checked. First body printed; surface defects reported. Complete physical RC2 validation pending.

RC1's 6.0 mm cavity missed the standard backplane guide-post reach. SATA 3.3 figures 32/40/42 yield 6.30 mm nominal and 6.76 mm with the listed axial tolerances conservatively added. RC2 provides 7.50 mm; this is a project allowance, not full interface certification.

| Item | RC2 result |
|---|---|
| Guide-post axial reach vs cavity | CAD passed; old 6 mm regression reproduced |
| Reference chip vs extended isolation wall | CAD gap 0.20 mm; actual component clearance pending |
| Reference modules, loading paths, lid stops, holes, envelope | CAD checks passed |
| Two Bambu plates and 28 support / 9 free-corridor checks | Nominal toolpaths passed |
| Body print | First body completed; side lettering and lower wall surface defects reported |
| Upper tray print and support removal | Pending; user preparing plate 2 |
| Body support removal | Pending |
| Empty shell fully seated in dock / fixed backplane | Pending |
| Actual 8 DIMMs and loaded lid operation | Pending |
| Clip strength, repeated handling and transport | Pending |

Prior coupon observations do not validate this complete body. Record actual material, nozzle, layer height, project hash and observations here. User photographs remain private.

## First body feedback — 2026-09-30

The first body was printed. The user reports poor surface quality around the side lettering and at the floor-to-wall transition, and suggests removing the side lettering and considering an internal curved transition later. The supplied photograph also shows horizontal surface variation beyond the letters. This does not establish a single root cause, layer separation, or functional failure. Actual project hash and any slicer overrides were not reported for this print. No user photo is published.

The user is preparing the internal tray plate. Keep the existing RC2 tray project for this first complete assembly; no geometry or process update is required solely by this surface report. Dock seating, DIMM clearance, lid operation and support removal have not yet been reported.

Follow-up candidates, not changes to the frozen RC2 files:

- Remove vertical side-wall lettering in a future revision; retain necessary operation cues on suitable horizontal rigid faces. Compare toolpaths before claiming an improvement.
- Check the height of the long lower-wall line against the floor/solid-layer transition and changes in speed, flow and layer time. A floor-to-wall transition can produce a similar line; see [Prusa's explanation](https://help.prusa3d.com/article/the-benchy-hull-line_124745). This is a hypothesis for this print, not a confirmed diagnosis.
- Evaluate a local internal fillet or chamfer only after checking DIMM, latch, mounting-hole and SATA cavity clearances. A fillet adds material and does not guarantee removal of the exterior line. Preserve the 26 mm envelope and do not consume the already tight reference chip clearance without explicit revalidation.

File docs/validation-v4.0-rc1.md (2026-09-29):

# v4.0-rc1 validation

Status: CAD and reference Bambu slicing checked; no complete v4 physical print reported.

Preceding hardware evidence: v3.1 shell latch fused; RC1 supported shell leaf returns; RC1 single-slot actual DIMM fits but has weak retention; upper rails obstruct tray loading; a single-slot coupon lacks bottom SATA relief; the old connector recess is opposite the receptacle in the tested USB dock. These are NOT v4 test results. User photographs remain private.

| Item | v4 result |
|---|---|
| Envelope, mounting and corrected cavity | CAD passed |
| Loaded upper-tray entry and integrated bottom DIMM extraction | Sampled CAD paths passed |
| Short-slide / lift lid and rigid stops | Sampled CAD paths passed |
| Support and free-corridor toolpaths | Nominal bead audit passed |
| Physical print and support removal | Pending |
| Empty shell fully seated in actual dock/backplane | Pending |
| Actual 8 DIMMs, chip clearance and handling | Pending |
| Lid locking, clip strength, repeated handling and transport | Pending |

Record project hash, material, nozzle, layer height, settings changes and actual observations here. Do not backfill CAD success as physical success.

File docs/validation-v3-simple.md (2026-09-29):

# v3-S 实物验证记录

当前只有软件几何和 Bambu Studio 导入回读结果，**没有 v3-S 实物反馈**。原 v2 的打印反馈不能转移为本版通过。

| 项目 | 状态 |
|---|---|
| 单槽一体托盘打印、槽口与弹臂缝清理 | 待验证 |
| 三层 2+3+3 满载叠放、滑盖闭合 | 待验证 |
| 真实三星 PCB 短边元件 / 标签避让 | 待验证 |
| 新使用者无需背景讲解即可找到固定槽和拨扣 | 待验证 |
| 手指能否轻松拨扣、同时扶持与取出内存 | 待验证 |
| 松手复位、反复开合、白化 / 裂纹 | 待验证 |
| 打开状态倾斜与闭盒携带保持 | 待验证 |
| 原 v3 外壳固定背板试配 | 尚无实测结果 |

记录实际耗材、喷嘴、层高、切片支撑、打印方向、开合次数和具体观察。发生卡滞或损坏时，不要填写“通过”，也不要用真实内存做跌落试验。

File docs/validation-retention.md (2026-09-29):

# V2-R physical validation record

Status: **not printed, sliced or physically fitted**. This retrofit responds to the user's v2 carrying-rattle report; it is not a verified transport solution.

| Check | Status | Required evidence |
|---|---|---|
| Single-slot keeper seating, empty | Not tested | Keeper on plastic rail, screw heads flush |
| Actual Samsung PCB edge/label clearance | Not tested | Both short edges, above and below PCB |
| Single-slot retention in different orientations | Not tested | Gentle handling; no forced fitting |
| Printed guide and roof dimensions | Not tested | Process settings and fit observations |
| Keeper screw thread engagement | Not tested | M2×5 head geometry, depth and no bottoming |
| Full retrofit in existing v2 body | Not tested | No interference, lid naturally seated |
| Two M2×20 ties secure all trays | Not tested | Correct bottom-tray thread engagement |
| Carrying-rattle reduction | Not tested | Separate whole-stack movement from PCB clearance |
| Repeated assembly / plastic thread strength | Not tested | Observations and a defined test method |
| Impact / vibration / transport qualification | Not tested | Requires an explicit physical test plan |
| ESD performance | Not tested | No certification implied |

Record exact revision, material, nozzle, layer height, module and fastener details. Do not promote these statuses using numerical checks alone.

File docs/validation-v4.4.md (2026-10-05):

# v4.4 完整工程验证记录

本版在用户授权下将 RC6 整块专用材料支撑推广到完整四件两盘工程。此处不将试件结果当作整盒验证。

已知局部证据：RC6 A 用户评价基本合格，固定端需工具用力、活动端较易拆；C1/C3 需工具撬。上述支撑均能一次拆净、无残留。N 两端下垂，固定端令 DIMM 无法插入，未采用。H32 的 3.2 mm 孔此前反馈正常。

完整 v4.4 待记录：

- 两盘实际耗时、材料及打印中支撑是否完整。
- 外壳两槽与两片三槽托盘各处拆除难度、残留、保留功能面质量。
- 八处卡簧回弹与实装，满载托盘装卸、上盖开闭。
- 侧孔、底孔与实际螺丝/免工具销钉，空盒与目标背板的插入。
- 整套携带时的保持和晃动；没有真实跌落、疲劳或冲击认证。

不得上传用户照片或将未报告项填写为通过。正式版本号表示固定的设计与工程快照，不表示物理认证。完整打印入口及名义检查范围见 [v4.4 指南](v4.4.zh-CN.md)。

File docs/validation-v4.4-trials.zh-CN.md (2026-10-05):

# v4.4 试件反馈与后续决策

更新日期：2026-10-04。以下仅摘录设计相关观察；不发布私人照片或完整对话。未提供实物试件的文件校验值、确切打印日期和逐项用力数据。

## RC4 六件测试盘：实物反馈与孔内支撑复核

| 试件 | 用户报告 | 决策 |
|---|---|---|
| A 活动端 | 可以无工具拆下支撑，但残留 1–2 层，仍需工具清理 | 支撑主体可拆不等于接触界面拆净；未通过免后处理目标 |
| A 固定端 | 仍难拆，借力把手先折断 | 不直接推广当前把手/支撑结构，优先改变剥离路径与接触薄片的取出方式 |
| C1、C3 | 侧向用力可以徒手掰出，有时残留 1–2 层 | 保留可拆的实物证据，但清理目标尚未通过；不据此宣称任意旋转取出均无干涉 |
| H32 | 用户评价完美、无问题 | 保留 3.2 mm 孔径和局部免支撑策略；不外推为所有托架的兼容认证 |
| P1、P2 | 未见明显区别；两件安装孔都有支撑 | 外观暂未见明显差异，不等于强度、整盘翘曲相同；孔内支撑是工程遗漏，需修正 |

用户补充的 A 两端照片可见狭槽内残片，并明确确认残留**主要是 Support for PLA**。因此下一步不能只解决 PLA 支撑芯强度，也要解决专用接触薄片的可达性和剥离。照片不能确定每处残片的原始层号、确切断裂面或粘接力。

### 已确认并修正的工程遗漏

RC4 的 P1/P2 从真实外壳截取，因此同时带入侧孔和底孔；生成器对 `process` 试件关闭了局部禁支撑选择，遗漏了这四个孔。原检查仅覆盖 H32 的两个孔，没有覆盖 P1/P2。这是交付和检查覆盖的错误。

`src/evaluate_rc4_feedback.py` 在原配置工程的**未发布副本**上恢复 P1/P2 孔内局部禁支撑，保留网格、全局参数及其他对象设置，使用 Bambu Studio 2.8.2.61 重新切片。每件增加 265 个禁支撑面，切片无警告。结果与校验值见 [刀路复核记录](reports/rc4-feedback-bore-audit.json)：

- 原 H32 两孔无自动支撑；原 P1/P2 四孔均确有自动支撑刀路。
- 修正副本的全部 **6 孔**检查区域均无自动支撑刀路。
- 另外复核完整产品选择性双材料候选的 **6 个侧孔＋4 个底孔**，全部无自动支撑刀路。

原测试盘估算 3795.305 秒，修正副本 3738.242 秒。此处约 57 秒差异仅属于测试盘，不作为整套产品收益。检查数是刀路分段数（包含圆弧离散），不是支撑件数量。修正副本孔顶的打印质量尚未实测；H32 的实测成功不能替代 P1/P2 孔顶验证。

### 下一步设计筛选

1. **优先处理薄片本身的取出。** 当前上下接触层分开，PLA 芯脱离后薄片可能仍留在成品上。评估把专用薄片连接到可达的剥离边或可取出的连接片，使取出操作能直接作用于薄片；检查其与成品的材料分离及实际刀路连续性。此解释是结构推断，不是粘接力测量。
2. **固定端改变受力路径。** 评估更靠近接触区的受力点和开放的剥离出口，避免仅延长、加粗把手；同时保留 DIMM 承托面、3 mm 卡簧基座及装卸净空。
3. **C1/C3 针对残留改进，H32 保持。** 不用增加配合间隙掩盖全部残留，不默认减少接触层、冲刷量或取消擦料塔。
4. **先检查完整工程，再选少数试件。** 对完整八槽、四处顶盖限位及全部安装孔检查几何、材料刀路、拆除可达性，并比较整套时间、专用耗材与换料次数；实际剥离力和残留仍需实物复核。P1/P2 的小试件结果不足以直接批准整套填充工艺。

本次不发布新测试盘，不更改已发布标签或工程附件；完整版本仍为 v4.3。RC4 当前结构不能标为免工具拆净、免后处理已通过。

## RC2 综合测试盘实物反馈

| 试件 | 用户报告 | 对设计的影响 |
|---|---|---|
| A、B | 仍需用技巧撬下，不能徒手直接抽取；比以前更容易拆除，残留减少 | 保留局部支撑分件，下一轮增加不同材料的接触面；未据此认定 B 优于 A |
| C1–C4 | 突出把手先被拔断，内部支撑仍不动；撬除似乎比以前容易 | 不能宣称抽取方案已成功；加宽把手并隔离支撑接触面 |
| H31/H32/H33/H36 | 用户已试过四个候选，并明确选择 **3.2 mm** | 后续完整工程的底部、侧面安装孔统一以 3.2 mm 为默认公称值，保留孔位/孔深；旧版不改 |
| K1/K2 | 尚未收到明确逐项结果 | 不填写通过结论 |

打印条件已知为 P2S、日常 PLA Basic 或 PLA Pure；此次试件确切耗材、层高及螺丝/销钉尺寸未单独记录。3.2 mm 是用户确认的设计取值，不是所有硬盘托架的兼容认证。

## RC3 双材料测试安排

用户确认使用 AMS 2 Pro，计划购买 **Support for PLA**。因此先交付 A、C1、C3、H32 四件同盘、明确区分保留 PLA / 可拆 PLA / 专用接触薄片的配置工程。RC3 尚无实物结果；本轮保持 A 永久接触结构不变，检验换材料能否减少残留，C 则同时加强已断裂的把手。

待记录：能否直接抽取、界面残留、把手完整性、DIMM 放入及回弹、实际材料用量/耗时。通过后再向完整工程推广；完整最新版本仍为 v4.3。

## RC5 一体/分体对比盘：等待实测

用户同意两条方向同盘比较。A 为连体专用材料稀疏梳齿与 PLA 锁键把手；B 为无支撑的分体固定端压条，活动端保留同款支撑。C1/C3 同时复核，H32 保持 3.2 mm，P1 修复孔内禁支撑。整盒几何与刀路筛选已完成，尚未打印，不能记为实测通过。见 [试件说明](v4.4-rc5-peel-trial.zh-CN.md) 和 [完整研究](rc5-structure-study.zh-CN.md)。

## RC5 实物反馈：2026-10-05

- P1、H32：用户观察没有明显问题；延续 3.2 mm 孔及对应孔内禁支撑。不据此宣称完整外壳强度、全部底孔或所有硬盘托架已验证。
- B 独立永久压条：用户认为复杂、不好用、难保管且容易丢，暂停作为首选。
- 一体 DIMM 试件：用户称为“B 集成一体式”，发行版实际编号为 A；照片覆盖固定端和活动端。按结构记录，不将名称差异当作用户打印错误。用户明确确认散丝和碎块在打印完成、尚未碰支撑时已存在。因此至少发生了打印阶段失败，不能归咎于拆除技巧；具体脱落起始层及原因尚未知。
- C 组：用户写“C3、C3”，记录为两件 C 组反馈，未据此证明每个编号均被独立确认。比较容易拆净，但普通 PLA 在异材交界处有瑕疵。缺陷属于牺牲把手还是永久顶棚仍需区分。
- 照片私有，不上传。RC5 DIMM 支撑实测未通过；旧版几何/刀路连通检查不是打印稳定性证明。后续优先取消异材锁键和细梳齿，不继续单纯加粗把手。

用户建议可拆支撑体连同延伸把手全部用 Support For PLA、使用完整简单形状。新增 `src/evaluate_rc5_solid_support.py` 进行完整产品初筛：填平梳齿间隙，全部牺牲件采用专用材料，永久产品几何不变。20 件支撑无异材内部锁键，660 个名义取出姿态、整盒 512/242/1520/132 个姿态检查通过；两盘 Bambu Studio 切片无警告。

整套参考 **5 小时 28 分 37 秒，46 次换料，183.38 g**，其中 Support For PLA **26.86 g**（包含冲刷/塔；实际牺牲件专用材料仅约 0.77 g）。比 RC5 一体候选增加约 34 分钟；这只是初筛，不是更快或已证明更稳的方案。见 [切片报告](reports/rc5-solid-support-screen.json)。尚未进行该候选完整刀路、打印过程和剥离验证，不发布为可打印新版，也不覆盖旧附件。

全专用材料取消的是支撑内部 PLA/Support 连接，永久 PLA 与支撑的接触面仍存在；接触面积增大可能增加剥离力，不能承诺消除所有表面瑕疵。随后应优先检查宽底支撑的第一层是否稳定、顶棚首层覆盖与取出通道，再筛选把手高度及整套换料成本。

关于无支撑：两端局部顶棚/齿头即使最终成形，也可能经历临时残料承托和底面下垂；当前照片不是干净无支撑对照。短悬伸仍值得做局部候选，但应检查齿头下表面尺寸、DIMM 装卸及保持，不能直接推广整盒。通用桥接下垂机制参考 [Prusa 官方说明](https://help.prusa3d.com/article/poor-bridging_1802)；本产品可行性仍以其具体几何和实物为准。

## RC6 整块支撑对照盘：原测试安排

已完成整盒两档把手筛选，交付 A（整块低把手专用支撑）、N（同结构无支撑诊断对照）、C1/C3 四件一盘。H32/P1 不重复；不再试独立永久压条。几何和实际刀路已检查，尚未打印，不能记为实物通过。请分别记录打印完成前的支撑失稳、拆除难度、残留与保留 PLA 功能面质量。见 [RC6 指南](v4.4-rc6-solid-trial.zh-CN.md)。

## RC6 实物反馈：整块支撑拆净，无支撑对照失败

以下实测结果取代上述等待实测状态。照片私有，不上传。

| 件 | 用户反馈 | 判断 |
|---|---|---|
| N | 两端悬空底面均略下垂；固定端导致 DIMM 完全无法插入 | 无支撑对照失败，不能用于当前完整产品 |
| A 固定端 | 支撑结实，需要工具用力拆除；一次拆净，无残留 | 残留改善，仍非免工具拆除 |
| A 活动端 | 支撑较容易拆除，一次拆净；用户评价 A 基本合格 | 保留整块支撑基线，不扩展为疲劳/冲击认证 |
| C1/C3 | 需要工具用力撬出，一次拆净，无残留 | 重点转为降低拆除力 |

重新检查 RC6 发布工程实际刀路：接触区首层 Z=4.8 mm，固定端混有 Bridge、Inner wall、Overhang wall，活动端为 Overhang wall；两个接触区前层均无直接承托。不能将其全部视为双端锚固桥接，单改桥接流量不能覆盖全部悬垂壁。

工程已配置悬垂降速和强制桥接/悬垂冷却（目标 100%），并非未启用这些功能。配置不是实测风量或热行为。局部温度、悬垂速度、层高及桥接流量仍可受控试验；不承诺越慢越好，也不建议直接全局降温或放大槽口。[Prusa 桥接说明](https://help.prusa3d.com/article/poor-bridging_1802)讨论了速度、冷却与流量；本件仍须按实际路径及实物判断。

若继续免支撑研究，优先考虑逐层伸出的自支撑斜面或改变顶棚路径，但斜面会占用槽口，必须重新核查 PCB、端部元器件、装入路径、释放动作及保持量。不能直接往槽内加三角筋，也不能用加高槽口掩盖不可控下垂。

下一步保留 A 活动端基线，优先检查固定端/C 支撑的非功能侧面接触、退出空间和可达施力缺口。目标是保留连续承托顶面与宽底座，通过可控的剥离起点逐步分离；没有粘接力测量，不能断言难拆只由侧壁摩擦导致。任何减小接触面积或局部底部间隙的试验都须重新检查支撑首层稳定性，不退回细梳齿、不默认增加顶面 Z 间隙。

此次记录反馈与诊断，不发布新盘、不修改 RC6 标签及附件。完整版本仍为 v4.3；整套成本、整盒装配及后处理效果仍需结合完整产品评估。

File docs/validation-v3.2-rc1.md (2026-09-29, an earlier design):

# v3.2-rc1 实物验证

状态：检查件已完成打印及全部支撑拆除。A 回弹正常，但小盖板因缺少两侧下承托而倾斜落下；C 基本正常、能固定 DIMM，但固定力较弱。实际 DIMM 可正常装卸且无干涉，两端元件距固定结构约 1 mm 或更多（用户观察）。单槽配合已有实测证据，完整装配和运输可靠性尚未通过；易拆性仍有问题。

后续外壳配合反馈：单槽件被旧外壳两侧上沿阻挡，掰壳放入后碰到 SATA 隆起，不能放平。CAD 已复现正式托盘也存在的垂直入口阻挡；单槽件没有正式底托盘的 SATA 避让，不能当作底层装配件。见 [路径诊断及底层一体化评估](loading-path-and-integrated-bottom.zh-CN.md)。暂停追加旧方案整套或小样打印，待入口和底层结构统一处理。

切片复核记录（2026-09-29）：已对四份最终带设置工程重新切片，并检查实际线宽、变层高支撑、竖向间隔和活动缝路径。见 [最终工程切片复核](slicing-audit-v3.2-rc1.zh-CN.md)。正式托盘中央活动走廊无挤出侵入；可选单槽试件有局部首层支撑伸入，须清理。模型/工艺没有改变，最新实物进度如下。

| 项目 | 结果 |
|---|---|
| 合盘检查件能完成打印 | 用户报告打印顺利；已提供四张照片，具体材料/参数与工程哈希未再次核验 |
| 外壳弹臂下方支撑可取出，弹臂可活动 | A 试件已拆支撑，用户确认回弹正常；完整外壳仍待测 |
| 底托盘接口凹区支撑可取出，表面不影响叠放 | D 试件支撑已拆除，尤其小圆点较难清理；完整底托盘及叠放仍待测 |
| 8 个固定槽和活动齿下方支撑可清理，不损坏弹臂 | B/C 试件已拆除，需技巧及镊子撬；无损状态与正式 8 槽仍待测 |
| 实际三星 PCB 槽高合适，颗粒及标签不接触框架 | 当前单槽和所用 DIMM 装卸无干涉；用户观察两端元件余量约 1 mm 或更多，非三层上下余量 |
| 手动拨扣装卸、松手回弹、无白化和裂纹 | C 基本正常、可固定 DIMM，用户评价单薄且固定力弱；白化/裂纹检查及寿命未单独确认 |
| A 小样盖板导向和锁定 | 未通过：缺少两侧下承托，后部倾斜落下；见 RC2 小样修正 |
| 新外壳与既有 v3.1 盖板可滑入并锁定 | 待实测 |
| 加宽外壳弹臂的解锁力度、意外侧向受力及开合寿命 | 待实测 |
| 三层托盘叠放和盖板捕获，不产生新的干涉或明显晃动 | 待实测 |
| 托盘从外壳上方自然装入和取出 | 未通过：用户单槽件被上沿阻挡；正式底/中/顶托盘的垂直路径也在 CAD 中相交，原终态检查不足 |
| 空盒孔位、固定背板、26 mm 成品厚度 | 待实测 |
| 完整真实 DIMM / 目标硬盘槽装配 | 待实测 |

每次记录使用的工程名、SHA-256、Bambu Studio 版本、耗材、喷嘴、层高及参数修改；分别记录打印、拆支撑和实际装配结果。没有这些证据，不把 RC 标成正式验证完成或批准十套批量制作。

早期照片拍摄于清理前；后续文字及两张照片已确认上述装配情况。已补充 [支撑对照](support-removal-v3.2-rc1.zh-CN.md) 和 [RC2 A 小样修正](v3.2-rc2-latch-check.zh-CN.md)。暂不建议十套批量制作；完整外壳、三层与硬盘槽仍须实测。用户照片未上传公开仓库。

## 支撑拆除反馈

| 位置 | 用户实物评价 | 当前结论 |
|---|---|---|
| A 外壳锁扣 | 顺利拆除，容易施力，但支撑与保留部分粘接紧密，需小心发力 | 本件可拆，不能归类为轻松剥离 |
| B 固定槽 | 顺利拆除，但依赖技巧，需要用镊子撬 | 本件可拆，工具接近和操作简便性待改善 |
| C 活动扣 | 顺利拆除，但依赖技巧，需要用镊子撬 | 本件可拆，薄弹臂清理后的状态待确认 |
| D 底部凹区 | 较难拆除，尤其小圆点需要精密镊子找到缝隙 | 本件可拆，是后处理改进的首要问题 |

本轮只更新实物记录，未调整模型或切片参数。不能因本次成功而推定加大支撑间距、减少接触层等改动不会引入新的打印问题。

## 后续功能反馈与修正

A 的前沿有支点，但两侧没有下承托。CAD 复现了后部向下倾斜 0.5–5° 的无阻挡路径；完整外壳另有安装柱承托，同一路径会接触，不能将小样失效等同为完整外壳失效。原检查遗漏倾斜下落，已在独立 RC2 A 试件中加入对应反向检查和两侧下承托。RC1 文件保持原状。

C 固定力弱仍是开放问题。本次单槽可固定并正常装卸，不能由此确认携带、防振或跌落保持力；没有据主观力度直接加厚弹臂。两端约 1 mm 余量不改变最不利参考包络的上方 0.1 mm 叠放余量，也不推广至其他 DIMM 型号。

用户建议取消独立底托盘，直接在壳内固定底层 DIMM。初查参考模块与外壳有布局空间，可作为下一架构的方向；还需改底层拨扣与顶盖入口，不能直接将旧托盘并入壳底。未输出新整套模型，也未确认省盘或打印提速。

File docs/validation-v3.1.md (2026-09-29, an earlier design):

# v3.1 首套完整实测记录

当前状态：几何与文件导入检查通过，有参考切片估计；**首个外壳实物反馈：按压锁扣与框架粘连、无法使用，免工具锁盖验证未通过。暂停采用当前方案批量制作。** 其他项目尚未获得通过证据。

## 2026-09-29 外壳锁扣失败记录

- 打印文件：`rdimm-v3.1-plate-1-pin-clearance`，用户报告为首次打印。收到两张实物照片；照片不随本记录公开提交。
- 用户观察：外壳按压锁扣与外壳框架粘连，无法使用。照片可见弹臂下方弯曲的丝线；仅凭照片不能确定全部粘连位置，也不能排除尝试分离后的变形。
- 对应已导出的切片：Bambu Studio 02.08.02.61，P2S / 0.4 mm 预设，0.20 mm 层高，2 道墙、15% Grid，支撑关闭。使用 PLA Basic 预设；实装线材为 Basic 还是 Pure 及其颜色名称尚未确认。切片预计 1h 54m 14s，实际耗时未报告。
- 源码核对：`src/build_v3.py` 的 `latch_leaf()` 采用 29 × 0.8 × 1.0 mm 弹臂及末端锁齿；弹臂下表面 Z=23 mm，下方槽底 Z=20 mm。`latch_guard()` 的 Y 最大值为 0.6 mm，弹臂 Y 最小值为 0.8 mm，局部净间隙仅 0.2 mm。
- 实际 G-code 核对：Z=23.2 mm 的弹臂首层包含约 29.59 mm 的长直线，标记 `Overhang wall`，F600（10 mm/s）。该位置缺少可移除支撑；它不同于底板 Z=3.2 mm 的封顶桥接，不能用此前底板桥接提速试验解释或解决。
- 初步归因：单端悬臂的无支撑首层及护挡处过小的间隙均为设计/打印适应性风险。照片与悬空路径下垂相符，但两项因素各自贡献尚未通过对照实物确认。不能将此归因为已证实的打印机精度不足。
- 后续处理：不以降低层高、提高速度或强行掰开作为已验证修复；优先评估将弹性结构移到可平放打印的盖板、外壳只保留固定止挡，并扩大活动间隙。该方向尚未完成新几何、切片和实物验证，不承诺零风险或与旧壳兼容。模型变更使用新版本，不覆盖 v3.1 标签、模型或附件。

| 打印信息 | 填写 |
|---|---|
| 下载包名、版本 / 提交号 | v3.1；待填写 |
| 日期、机器、喷嘴 | 待填写 |
| 耗材与颜色 | PLA Basic / PLA Pure；待填写 |
| 层高、墙数、填充、线宽 | 待填写 |
| 热床、支撑、裙边、其他修改 | 待填写 |
| 每盘切片预计 / 实际时间 | 待填写 |
| 每盘耗材 / 失败重打情况 | 待填写 |

| 检查 | 结果 / 观察 |
|---|---|
| 五件齐全、无翘曲或残留支撑 | 待验证 |
| 空托盘叠放、盖板徒手锁定与解锁 | **锁扣失败：外壳按压锁扣与框架粘连、无法使用**；托盘尚未打印，叠放仍待验证 |
| 空外壳在托架中能轻推到底、背板不干涉 | 待验证 |
| 侧 / 底定位销能到底、托架能锁住 | 待验证 |
| 单条三星 DIMM 的 PCB 短边、颗粒和标签避让 | 待验证 |
| 持扣装入、松手回弹、扶住 DIMM 拨扣取出 | 待验证 |
| 2+3+3 满载、盖板自然闭合 | 待验证 |
| 满载完整盒子插入硬盘槽并锁定 | 待验证 |
| 携带晃动、开合后损伤、白化 / 裂纹 | 待验证 |
| 新使用者能否无需讲解完成取放 | 待验证 |
| 填充候选与基线的尺寸 / 强度 / 外观对照 | 待验证 |

先空盒检查目标背板，再装真实 DIMM。阻力异常或卡扣不能回位时记录现象，不强推、不靠内存撑开卡扣；不使用真实 DIMM 做跌落测试。首套通过前不把切片成功当作十套批量质量保证。

## 2026-09-29 托盘打印前风险复核（非实物失败记录）

用户已完成外壳盘，托盘盘尚未开始。本次检查没有收到托盘实物，不将以下风险记为已发生故障。

- 有利差异：托盘 0.8 × 18 × 6.2 mm 弹臂从热床开始打印，旁边为贯通槽，不具有外壳按压弹臂的长距离悬空起印方式。弹臂主体内侧在所切开的区域名义间隙约 0.9 mm；这不是所有活动位置的最小间隙证明，也不是打印精度或寿命认证。
- 活动扣齿：下表面为 Z=4.5 mm 的平面，相对弹臂内侧伸出约 2.6 mm；其斜面在上侧，不是底部自支撑斜面。固定端亦有水平悬挑。下垂可能侵入 PCB 槽口或降低有效扣合余量，尚未实测。
- PCB 竖向槽高参考为 1.5 mm（Z=3.0..4.5），参考最厚 PCB 1.37 mm，剩余总高度余量仅约 0.13 mm。此值不是活动臂与框架的间隙；尚未测量实际三星 PCB，也未验证打印后的槽高。
- 底托盘：避让切除范围 X=0..7、Y=10.8..58.2、Z=0..3.2 mm。与底托盘左轨交叠后，局部约 40 mm 长的下表面缺少下层实体承托；不能直接填实该凹区，否则可能与外壳背板避让处的凸起干涉。
- 参考切片：使用正式 `rdimm-v3.1-plate-2-all-trays.3mf`，本地 Bambu Studio 02.08.02.61 / P2S 0.4 mm / PLA Basic，将工艺字段按外壳实际设置映射为 0.20 mm、2 道墙、15% Grid、关闭支撑。Z=3.4 mm 的底托盘凹区有约 39.3–40.0 mm 的 `Overhang wall` / `Bridge` 长直线。切片器无警告仍不能证明打印可靠。此为离线参考实验，不是用户实际托盘任务的导出或经验证的打印配置。
- 决策：不建议沿用无支撑设置直接打印整盘。优先在新版本处理底托盘避让区的打印承托方式、固定槽/活动扣齿的下表面及 PCB 槽余量；保持 8 条容量、无独立限位框、免内部螺丝、26 mm 外形约束。任何新模型仍须完成几何、切片和实物验证，不宣称零风险；v3.1 模型与附件保持不变。

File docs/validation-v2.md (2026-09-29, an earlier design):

# V2 physical validation record

Status: **user print reported; carrying retention needs correction**. The user confirmed printing the v2 two-plate files and described the overall result as good, with noticeable movement during carrying. It is not yet known whether the tray stack, the modules, or both are moving. No measured tolerances or detailed material/slicer information were supplied. Numerical results in `models/v2/verification.json` remain the original generation-time record.

An unprinted [v2-R retrofit](retention.zh-CN.md) is proposed. It has a [separate physical validation record](validation-retention.md).

| Check | Status | Evidence / conditions |
|---|---|---|
| P2S slicing and continuous thin-wall paths | Print reported; path details unknown | Actual slicer/profile/material/nozzle/layer height were not supplied |
| Exact Samsung short PCB-edge contact areas | Not tested | Confirm no components or label buildup on shelves |
| Single-slot component clearance and removal | Not tested | Record module part number and actual print |
| Three-coupon stack without preload | Not tested | Record gap, warp and any witness marks |
| Full 2+3+3 stack with lid resting naturally | Not tested | Do not force the lid down with screws |
| Lid locators and flush countersunk screws | Not tested | Record head size, length and effective tapped depth |
| Side insert calibration and installation | Not tested | Record part, measured bore, material and installation method |
| Repeated side insert tightening / pullout | Not tested | Establish a test method before claiming strength |
| Bottom plastic thread depth and durability | Not tested | Empty body test first; max intrusion 3 mm |
| Chassis/tray fit | Not tested | Record chassis or holder and mounting direction |
| RAM/tray retention during carrying | Issue reported by user | Noticeable movement; source not isolated; v2 has no independent PCB latch |
| Pull eye / optional ribbon usability | Not tested | Keep attachments outside RAM cavities |
| ESD material / enclosure performance | Not tested | No ESD certification implied |

Add dated observations with the exact commit, printer, material and module identification. Keep failures and limitations visible. Do not replace “not tested” solely because the generator or CI passes.

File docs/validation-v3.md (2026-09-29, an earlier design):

# v3 实物验证记录

状态：数字模型与自动检查完成；未切片、未打印、未试装。旧 v2 的打印反馈不作为 v3 通过依据。

软件导入检查：七份排版 / 试件文件已通过 Bambu Studio CLI 的 STL → 3MF 回读，边界、实体数量、闭合性和体积保持。该结果不是切片或实物通过记录；对应输入哈希见 `models/v3/bambu-import-check.json`。

| 阶段 | 验收内容 | 结果 |
|---|---|---|
| 滑轨小样 | 不磨损硬挤即可滑动；抬起时仍被捕获 | 待实测 |
| 凹字与图标 | `TEST` 小样可读；整件英文和箭头连续、未因首层挤压而糊字 | 待实测 |
| 锁扣小样 | 局部支撑可彻底清理；徒手按下可解锁，复位后不能直接滑脱 | 待实测 |
| 反复开合 | 记录材料、次数、变白 / 裂纹 / 松弛，以及保持力变化 | 待实测 |
| 单槽框 | 连筋完整；定位柱可徒手装拆；短边唇不碰颗粒、焊点和标签 | 待实测 |
| 空壳孔位 | 定位销直径、实际伸入长度、孔深和孔距全部适配 | 待实测 |
| 固定背板 | 空壳轻推可插到底，托架完全锁上，插座塑料壳及导向柱不接触 | 待实测 |
| 总高 | 成品包括锁扣和盖板最高点不超过 26 mm | 待实测 |
| 完整装配 | 三层框自然就位，滑盖无强压即可闭合，空置槽位不影响固定 | 待实测 |
| 温和翻转 | 盖板锁好，先用等尺寸非电子试件确认无脱出或明显撞击 | 待实测 |
| 内存实装 | 实际三星料号布局及打印余量核对后，再观察是否有移动与接触痕迹 | 待实测 |

反馈建议包含：打印材料、喷嘴 / 层高、是否保留所有细筋、锁扣支撑清理方式、托架与背板型号（如知道）、销的直径与伸入长度、凹区实际干涉位置。没有这些实测前，不标记为运输容器认证，也不承诺所有硬盘槽位通用。

开盖后的单层托盘没有独立倒置锁止，需水平拿取。这是当前结构的使用边界，不应通过反复倒置未封闭托盘来验证本版。

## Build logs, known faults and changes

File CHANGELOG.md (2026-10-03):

# Changelog

## v4.4-rc4-product-trial — one plate selected from full-product studies

- Six specimens: A DIMM slot with no-foot raised grips and an exterior paddle gusset; C1/C3 captures; selected H32; P1/P2 identical full-body floor/sidewall crops apart from labels. P2 alone uses wider internal lines and combined sparse infill. Keep whole-product benefits as the selection criterion.
- Five PLA cores and14 explicitly assigned Support For PLA interfaces; ordinary automatic interfaces remain PLA with.2mm gaps. Preserve normal tower,800mm3 purge each direction and no flushing into functional parts. One configured project retains six independent objects and P2 overrides.
- P2S .4/.2 reference1h03m15,6 changes,25.00g including flush/tower. Fourteen interface audits, support-free bores, spring corridor, process variants and tower clearance pass. Geometry and actual toolpaths do not establish physical removal force, surface quality, fatigue or full-plate warpage.
- Numbered prerelease includes project, removal/plate diagrams, instructions, reports and checksums. Complete release/VERSION remain4.3; earlier assets unchanged.

## v4.4-rc3-dual-trial — Support for PLA contact layers

- Address RC2 feedback: A/B still need prying; C grips break before release. One plate with A, long/short C1/C3 captures and selected H32. Keep A permanent contacts unchanged; widen C grips to4.8/3.4 mm and make removable parts solid.
- Five PLA cores,17 explicit Support For PLA contact volumes, individually assigned to material2; automatic paddle-support interfaces also use material2. Use official GFS02 Support For PLA preset, AMS mapping, prime tower and800 mm3 flushing in both directions; no flushing into printed parts/supports. Actual material mixing and release remain unverified.
- P2S .4/.2 reference1h03m43,10 changes,22.86g including flushing/tower. Geometry/extraction checks and all17 actual interface-path audits pass; report bead-contact gaps and preserve correct material identity. H32 holes remain support-free.
- User selected3.2mm from the printed hole candidates; adopt for future complete side/bottom mounting bores. This numbered prerelease contains coupons only; latest complete release stays v4.3, old assets unchanged.

## v4.4-rc2-combined-trial — one plate for all current cleanup changes

- Combine unchanged RC1 A/B DIMM slots, four cropped lid-capture coupons with inward pull supports, four bottom/side-hole coupons (3.1/3.2/3.3/3.6 mm), and two tray corner coupons with obsolete fins AND floor remnants removed. Twelve labeled specimens; ten modeled removable supports.
- Block automatic support only in intended channels and bores; retain A/B paddle supports. Nominal bead checks pass for all twelve specimens, including grip connectivity and eight empty bores.
- Configured P2S .4 / PLA Basic /.2 project, 56m31 /22.57 g, with illustrated removal guide. Physical removal, bridging, screw fit and retention remain pending. This prerelease keeps the complete v4.3 release and historical RC1 unchanged.

## v4.4-rc1-support-trial — one-plate A/B experiment

- Add two full-length single-slot coupons with three inward-pull sacrificial supports each. Retain automatic paddle supports; include a configured P2S project and removal diagram.
- A retains v4.3 slot contacts. B locally recesses seat/ceiling by ~0.3 mm while preserving end bearing lands. B keeper is locally thinner; retention and fatigue require physical checks.
- Geometry and sampled toolpath checks pass, including 198 support extraction poses. P2S reference 31m55 /13.12 g. Removal force, surface quality and actual insertion remain unverified. This prerelease does not replace the complete v4.3 set.

## v4.3 — continuous floor reinforcement with retained ledge

- Preserve the ledge at Z10.4 with R0.4 top edge, and join its inner face to the Z4 floor using a tangent concave R3.5 blend. The first tray remains at Z10.8 with 0.4 mm clearance; this is wall reinforcement, not a tray seat.
- Only bodies change; v4.2 lid and both upper trays are byte-identical. Preserve holes, SATA, module clearance and loading paths; complete two-plate package still provided.
- Include subdivided cylindrical chord vertices in support blockers; final six bores contain zero support. All other support/clearance audits pass. P2S reference 3h10m44, 125.47 g, approximately 13 s above v4.2. Actual strength and finish remain unverified.

## v4.2 — complete release

- Repair first upper-tray clip anchors with 3 mm full-height bases; preserve keeper positions and R1 root blends.
- Recess fixed frame below all eight DIMM heads by 0.5 mm while preserving PCB seats and moving heads. Nominal sliced model gap 0.6 mm; local support interfaces still require removal.
- Replace high long-wall triangular ridges and separate R2 fillets with continuous concave R6 floor transitions. Preserve mounting bores and loading paths; first upper tray has 0.8 mm vertical clearance.
- Complete four-part/two-project release; RC4 lid reusable, shell and trays updated. P2S reference 3h10m31, 125.47 g. Geometry and nominal toolpath checks pass; complete physical fit, force, fatigue and impact remain unverified.

## v4.1-rc3 — replacement lid for tight RC1/RC2 capture slots

- Address reported entry and full-travel jamming with double entry chamfers, small exit chamfers and .2 -> .4 mm upper/lateral gaps. Preserve flat capture and release latch; RC1/RC2 body and trays unchanged.
- Sliding tongue thins 1.4 -> 1.2 mm with full 1.4 mm root; upper riser narrows to 1.2. Flat bearing area decreases to 41.80 mm2. Upward clearance increases; explicit .55 mm stop probe preserves historical defaults. No unchanged-strength claim.
- Full reference geometry and four replacement-lid support regions pass. One configured replacement-lid plate estimated 36m38 /24.25 g. Physical fit, force, fatigue and impact remain unverified.

## v4.1-rc2 — connect upper wall above bottom-release windows

- Add two 45-degree arch roofs with R1 apex in the original 1.6 mm wall footprint; minimum upper link height 4.114 mm. Preserve lower latch/support access and all loading paths. RC1 lid/tray geometry is unchanged and reusable.
- Configured p2 blocks support only on six side bores and the two arch roofs; re-sliced bead checks find no upper-window support, with all 36 required support areas and nine motion corridors passing. Automatic p1 arch supports retained only as an audit control.
- Same-profile total estimate ~3h12m06, +30 seconds and +0.63 g versus RC1-p1. First physical arch finish, access and impact performance remain unverified.

## v4.1-rc1 — flat lid captures and reinforced clip roots

- Replace four short sloped lid captures with 2 mm flat flanges and matching tongues; preserve the press/8 mm slide/lift operation. Adjust all tray end reliefs: matched complete set required.
- Thicken lid/DIMM springs, widen locking teeth and add root fillets. Brace the long walls with low triangular belts while preserving HDD bores and SATA clearance. Central lid skin stays unchanged to preserve component clearance.
- Full reference geometry/motion, optional-screw, watertight mesh and 36 support/nine corridor audits pass. P1 projects retain local side-hole blockers. Supports on new tongues and ledges need removal; provide actual-path diagrams.
- Same-profile total estimate ~3h11m36, +2.9% and +0.94 g versus RC4-p1. Impact, fatigue, opening force and support-removal ease are untested; not a drop rating.

## v4.0-rc4-p1 — local side-bore support blockers

- Preserve RC4 round bores; block support only on six upper cylindrical side-hole surfaces after difficult support-removal feedback. Retain all other support settings.
- Bambu save/reload preserves paint; six hole regions have zero support extrusion, with 28 other support regions and nine corridors passing nominal bead audits. First plate saves about 54 seconds. Physical unsupported-roof quality and pin fit remain untested.
- Deliver configured projects as a separate process revision; STL cannot carry the support paint.

## v4.0-rc4 — R2 long-wall floor fillet candidate

- Add R2 to the two long internal floor edges while preserving original mounting bores. Leave short-end release windows and SATA geometry unchanged; RC2/RC3 lid and upper trays remain compatible.
- Evaluate R1/1.5/2/3 with sampled full-assembly checks; demonstrate why blindly adding a full perimeter ring fills mounting and release voids. R2 top is Z=6, 4.8 mm below the first removable tray.
- Same-process Bambu first-plate estimate increases by 1.52 seconds and 0.127 g. Two plates and nominal support/corridor audit pass. Surface improvement and full physical assembly remain unverified.

## v4.0-rc3 — remove exterior side engravings

- Fill vertical PRESS/arrow and SATA END cuts following the first RC2 body surface report. Preserve horizontal operation marks, all internal geometry, and RC2 lid/upper-tray compatibility. No internal fillet or slicing speed change.
- Geometry differences are confined to the outer 0.3 mm; full assembly/path checks and two-plate slicing/support audit pass. Reference plate 1 saves about 107 seconds. Physical finish improvement and full assembly remain unverified.

## v4.0-rc2 — standard SATA backplane guide-post depth

- Increase the single connector recess from 6.0 to 7.5 mm after checking SATA-IO 3.3 figures 32/40/42. Reproduce the old cavity collision with the 6.76 mm axial envelope. Width, side and height stay unchanged.
- Extend the 0.8 mm isolation wall; reference chip lateral gap is now 0.2 mm and requires physical checking. Lid and upper trays are unchanged from v4 RC1.
- Rebuild full meshes, two plate layouts, reference configured projects and previews; geometry and nominal toolpath audits pass. Full physical fit and retention remain pending.

## v4.0-rc1 — corrected connector side and integrated bottom

- Move the single connector recess from Y=11–58 to Y=43.6–90.6 mm after correcting bottom/end-view interpretation. Preserve its width, mounting datums and published old artifacts.
- Integrate two bottom slots into the body. Expose their release beams through end windows, isolate their feet above the floor and require removable support. Keep two removable three-slot upper trays.
- Replace continuous lid rails with four corner retainers, a notched lid and an 8 mm slide-then-lift operation. Verify loaded upper-tray insertion, in-shell bottom DIMM removal, lid translation/tilting stops and module envelopes.
- Deliver four parts on two comfortably spaced plates. P2S / PLA Basic / 0.20 mm estimate: 127 min body/lid + 62 min upper trays, about 125 g total. No speed increase or ten-set deadline promise.
- Audit 28 supported regions and nine free corridors from actual Bambu toolpaths. Physical support cleanup, full assembly, dock fit, clip strength and transport reliability remain unverified.

## v3.2-rc2 — A coupon correction only

- Record RC1 physical results: all coupon supports removed, shell leaf returns normally, actual DIMM fits without interference, tray retention feels weak. Full-set and transport validation remain pending.
- Reproduce the A slider tipping into its base: the cropped fixture omitted lower side bearings. Full-body bearing posts block the same rigid path, but do not establish physical success.
- Add two lower rails only to the A coupon base, retaining the existing slider. Add pitch/roll regression checks alongside release and sliding sweeps; preserve all RC1 files and settings.
- Provide a one-base P2S / PLA Basic project estimated at 13 minutes / 3.54 g. This is not a new full enclosure release; tray stiffness and support-cleanup improvements remain open.

## v3.2-rc1 — supported printability candidate

- Record a real v3.1 shell latch fusion failure; trays have not yet been physically printed. Keep the v3.1 release immutable and mark this revision as awaiting physical validation.
- Remove the shell's 0.2 mm parallel-guard clearance and widen its release leaf from 0.8 to 1.6 mm. Local support remains required; the changed load path has no force/fatigue validation.
- Raise tray PCB roofs by 0.1 mm to give 1.6 mm nominal slots and add entry chamfers, keeping the PCB shelf above the connector roof. Recheck reference envelopes, module stops and extraction paths; worst upper component headroom is 0.1 mm.
- Generate editable P2S / PLA Basic Bambu projects with explicit normal/snug supports. Audit support paths under the shell leaf, connector recess, bottom tray recess, all eight teeth/hoods and finger paddles. Support removal is still untested.
- Keep the full set at two plates, add a body-only alternate for existing lids, and pack four optional validation pieces onto one plate. Source scripts generate full vendor presets and G-code only in ignored local build output.

## v3.1 — versioned full-validation release

- Name the v3-S integral-latch design v3.1 without changing part geometry. Publish versioned STL and geometry-only 3MF files, manifests/checksums and an immutable release tag; preserve historical designs.
- Prove two flat plates are minimal for a single set by actual projected area (65,847.84 mm² > 65,536 mm²). Supply both shell-hole variants and clear five-part packing lists.
- Add a ten-set batch option: ten body/lid/bottom plates plus five plates with two middle/top pairs, totaling 15 jobs. This is not a global batch minimum proof.
- Benchmark eight actual CLI slices with P2S 0.4 / PLA Basic profiles. Infill-only tuning saves about 3.6% per set; combined batching/tuning estimates 5.7% machine-time savings for ten sets, plus five fewer plate changes. No physical quality or time guarantee; profiles remain candidates.

## v3-S — experimental integral-latch trays

- Keep eight modules and the v3 shell/lid, replacing three loose retainer frames with fixed end slots and integral outward-release tabs on three trays. Retain tool-free daily use; lift the tray out before releasing RAM.
- Check reference-module clearances, six-direction PCB stops, illustrative flexure travel and a held-release tilt/withdrawal path. Force, fatigue, actual printing and physical retention remain unverified.
- Preserve all v3 files. Publish separate `models/v3-simple` files, one combined six-piece test plate, and a two-plate full set. Existing v3 shell/mechanism test parts need not be reprinted.

## v3 — experimental tool-free storage and backplane-clearance design

- Combine all three first-test groups into `first-test-all.stl`: seven pieces on one 256 mm bed, preserving print orientations, with at least 10 mm part gaps and 15 mm bed margins. Keep individual test files for replacements; add a mesh-derived plate preview and Bambu import verification.

- Engrave simple operating instructions directly into the cover, fixed body walls, tray end rails and paired retainer frames: press/open arrows, level icon, layer numbers, lift points and connector-end orientation. Use original 0.55 mm stroke lettering, 0.30 mm recesses and no external font dependency. Regenerate all plates and retainer lettering samples; preserve assembly interfaces and the 26 mm envelope.

- Remove mandatory interior hardware: three trays and three removable keyed PCB-edge retainer frames are captured by a closed sliding cover. Open trays must stay horizontal; they are not independently latching cartridges.
- Add 45-degree slide rails, a press-down anti-slide latch, optional cover reinforcement screws and finger access. Keep the 26 mm CAD height and eight-module capacity.
- Deepen side/bottom bores to 5.7/5.3 mm (+2 mm), with checked 5 mm intrusion. Offer separate thread-pilot and 3.6 mm locating-pin-clearance bodies.
- Add a 6 x 47 x 6.2 mm connector-end bottom recess as a trial clearance envelope, with a matching bottom tray. Actual fixed-backplane compatibility is unverified.
- Add mechanism/retainer first-test plates, a full-footprint empty fit gauge and three complete P2S plates. Local latch support and thin-wall slicing must be checked.
- Validate 512 module poses, 2048 frame-offset cases, 48 PCB stop controls, 64 retainer coupon cases, lid release sweep and both body options. Record a limited parallel-tilt study (6 or 7 modules under the stated assumptions); do not claim a global packing optimum.
- Preserve all previously printed v2 artifacts. No v3 physical, fatigue, impact, ESD or universal-bay-fit claims.

## v2-R — experimental carrying-retention retrofit

- Respond to a user print of v2 with noticeable carrying rattle; preserve the printed body and original v2 meshes.
- Replace trays/lid, add six PCB-edge keeper bars and short-edge guides, and connect the tray stack to the lid with two M2x20 screws. Add twelve M2x5 keeper screws; the existing four lid screws remain in use.
- Retain intentional PCB clearance instead of force-clamping memory. Add 512 reference translation cases, 48 physical-stop negative controls and 64 single-slot cases.
- Supply a first-test plate and two upgrade plates. Real fit, rattle reduction, thread strength and transport performance remain unverified.

## v2 — unprinted engineering prototype

- Keep the 147 × 101.6 × 26 mm envelope, 8-module capacity and mounting coordinates.
- Raise the short-edge shelves and increase tray pitch: nominal component-to-floor clearance improves from 0.10 to 0.30 mm; clearance to the next tray remains 0.33 mm.
- Reduce base/lid thickness and total stack relief to make room; shorten bottom pilot holes to preserve 0.7 mm of material behind them. V1 parts must not be mixed with v2.
- Add two lid locating collars, tray pull eyes and one/two/three tier marks.
- Offer a separate body with six side bores for PEM IUTB-632-150 inserts; retain bottom plastic pilots due to the edge-distance constraint.
- Add a three-tray single-slot stack coupon, flat cap, insert bore calibration coupon, mesh detail preview and physical validation checklist.
- Extend geometry checks to alternate body, maximum insert envelope, coupon stack, assembled envelope and 64 component-offset cases.
- Preserve v1 meshes and source as `src/build_v1.py`. No physical, orientation-retention, insert-strength or ESD claims are added.

## v1 — initial engineering prototype

- Three removable trays (2+3+3 RDIMMs), conventional HDD mounting pilots, M2-fastened lid, single-slot fit coupon and reference geometry checks.

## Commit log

2026-09-28 Publish 8-RDIMM HDD-form-factor prototype with reproducible build and collaboration docs
    [body.stl, fit-coupon-1-slot.stl, lid.stl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]
2026-09-28 Use current GitHub Actions releases for supported runner runtimes
2026-09-28 Add v2 RDIMM case with larger component clearance and serviceable tray features
    [body-pilot.stl, body-side-inserts.stl, fit-coupon-1-slot-print-3.stl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]
2026-09-28 Add two-plate P2S layouts for v2 with STL and geometry-only 3MF exports
    [optional-test-plate.3mf, optional-test-plate.stl, plate-1-pilot.3mf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]
2026-09-29 Add v2 retention retrofit with PCB edge keepers and tray tie screws
    [first-test-plate.stl, keeper-2-print-2.stl, keeper-3-print-4.stl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]
2026-09-29 Clarify v2 print status after user feedback
2026-09-29 Add v3 tool-free retainer stack and sliding cover prototype
    [body-pin-clearance.stl, body-thread-pilot.stl, empty-fit-gauge-pin.stl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]
2026-09-29 Engrave operating guides on v3 case and trays
    [body-pin-clearance.stl, body-thread-pilot.stl, empty-fit-gauge-pin.stl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]
2026-09-29 Combine all v3 first-test parts on one print plate
    [first-test-all.stl]
2026-09-29 Add integral-latch trays to simplify eight-module storage
    [body-pin-clearance.stl, body-thread-pilot.stl, empty-fit-gauge-pin.stl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]
2026-09-29 Version v3.1 two-plate release and benchmark ten-set batch printing
    [batch-a-body-lid-bottom.stl, batch-b-middle-top-2sets.stl, body-pin-clearance.stl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]
2026-09-29 Add v3.2 RC1 supported shell latch and tray printability revision
    [body-pin-clearance.stl, body-thread-pilot.stl, bottom-recess-test.stl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]
2026-09-29 Document RC1 support cleanup feedback and add CAD removal guide
2026-09-29 Fix A coupon lower bearings and reproduce slider tipping failure
    [latch-test-base.stl, rdimm-3.2-rc2-plate-A-base-only.3mf, rdimm-3.2-rc2-plate-A-base-only.stl]
2026-09-29 Add v4 RC1 with corrected SATA side and integrated bottom slots
    [body-pin-clearance.stl, body-thread-pilot.stl, lid-slide-lift.stl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]
2026-09-29 Fix SATA backplane guide-post depth in v4.0-rc2
    [body-pin-clearance.stl, body-thread-pilot.stl, lid-slide-lift.stl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]
2026-09-29 Record first RC2 body print and surface finish follow-ups
2026-09-29 Add compatible v4.0-rc3 body without side engravings
    [body-pin-clearance.stl, body-thread-pilot.stl, lid-slide-lift.stl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]
2026-09-29 Evaluate floor fillets and add compatible R2 long-wall RC4
    [body-pin-clearance.stl, body-thread-pilot.stl, lid-slide-lift.stl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]
2026-09-29 Add V4.1 flat lid captures and reinforced clip roots
    [body-pin-clearance.stl, body-thread-pilot.stl, lid-slide-lift.stl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]
2026-09-29 Close upper release windows with printable arches in v4.1 RC2
    [body-pin-clearance.stl, body-thread-pilot.stl, lid-slide-lift.stl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]
2026-09-29 Ease lid entry and travel with RC3 replacement lid
    [body-pin-clearance.stl, body-thread-pilot.stl, lid-slide-lift.stl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]
2026-09-29 Document cross-reviewed lid alternatives and coupled-pose sensitivity
2026-09-30 Fix lid neck shoulder clearance with RC4 replacement lid
    [body-pin-clearance.stl, body-thread-pilot.stl, lid-slide-lift.stl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]
2026-09-30 Release v4.2 complete set with 3 mm tray clip anchors
    [body-pin-clearance.stl, body-thread-pilot.stl, lid-slide-lift.stl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]
2026-09-30 Finalize v4.2 with tooth clearance and floor-grown concave transitions
    [body-pin-clearance.stl, body-thread-pilot.stl, rdimm-4.2-plate-1-pin-clearance.3mf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]
2026-09-30 Release v4.3 with continuous floor reinforcement and rounded side ledges
    [body-pin-clearance.stl, body-thread-pilot.stl, lid-slide-lift.stl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]
2026-09-30 Add versioned A/B pull-support and residue-relief trial
    [A-cleaned-reference-NOT-PRINT.stl, B-cleaned-reference-NOT-PRINT.stl, rdimm-4.4-rc1-support-trial-plate-0-support-ab.3mf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]
2026-09-30 Add v4.4 RC2 combined one-plate cleanup and mounting trials
    [rdimm-4.4-rc2-combined-trial-plate-0-combined.3mf, rdimm-4.4-rc2-combined-trial-plate-0-combined.stl]
2026-09-30 Add v4.4 RC3 Support for PLA dual-material trial and select 3.2 mm mounts
    [rdimm-4.4-rc3-dual-trial-plate-0-dual.3mf]
2026-10-01 Evaluate dual-material batch and prime-tower efficiency without reducing purge
2026-10-03 Add v4.4 RC4 one-plate product validation with selective interfaces and infill controls
    [rdimm-4.4-rc4-product-trial-plate-0-dual.3mf]
2026-10-04 Record RC4 physical support failures and audit all mounting bores
2026-10-04 Add RC5 integral and split-keeper comparison plate with whole-product audits
    [rdimm-4.4-rc5-peel-trial-plate-0-dual.3mf]
2026-10-04 Record RC5 print failures and screen solid dedicated supports on full product
2026-10-04 Add RC6 solid-support trial with unsupported DIMM control
    [rdimm-4.4-rc6-solid-trial-plate-0-dual.3mf]
2026-10-05 Release complete v4.4 dual-material case with solid removable supports
    [body-pin-clearance.stl, lid-slide-lift.stl, rdimm-4.4-plate-1-pin-clearance.3mf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]
2026-10-05 Release v4.4.1 with physical version identifiers on every permanent part
    [body-pin-clearance.stl, lid-slide-lift.stl, rdimm-4.4.1-plate-1-pin-clearance.3mf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]
